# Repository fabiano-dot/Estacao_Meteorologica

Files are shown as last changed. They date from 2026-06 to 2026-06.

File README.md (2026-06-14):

# 📡 Estações Meteorológicas LoRaWAN – UNICAMP

Firmware e infraestrutura de servidor de uma rede de monitoramento ambiental baseada em **LoRaWAN**, implantada no campus da **Universidade Estadual de Campinas (UNICAMP)**. As estações são identificadas de `em01` a `em10` e estão sendo gradualmente implantadas ao longo do campus.

Os dados coletados estão disponíveis publicamente e são atualizados diariamente em: **[HuggingFace Dataset](https://huggingface.co/datasets/adr1t0s/estacao-meteorologica/tree/main)**

---

## 🏗️ Arquitetura do sistema

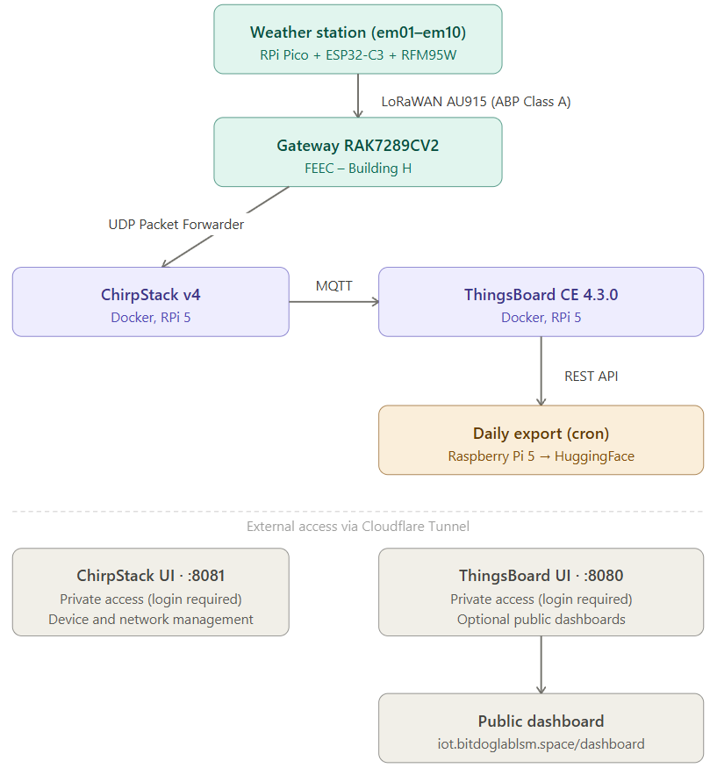
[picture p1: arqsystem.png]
Arquitetura do sistema


---

## 📡 Rede LoRaWAN

| Parâmetro | Valor |
|---|---|
| **Gateway** | RAK7289CV2 |
| **Região** | AU915 — sub-bandas 0 e 1 (16 canais) |
| **Modo** | ABP Classe A |
| **Servidor de rede** | ChirpStack v4 (self-hosted, Docker) |
---

## 🖥️ Servidor

| Componente | Descrição |
|---|---|
| **Hardware** | Raspberry Pi 5 (8 GB RAM) + SSD NVMe 256 GB |
| **OS** | Raspberry Pi OS (64-bit) |
| **ChirpStack v4** | Servidor de rede LoRaWAN (Docker) |
| **ThingsBoard CE 4.3.0** | Plataforma IoT — ingestão, regras e dashboards (Docker) |
| **Mosquitto** | MQTT broker |
| **Cloudflare Tunnel** | Acesso remoto seguro sem exposição de portas |

---

📂 Estrutura do repositório

```
Estacao_Meteorologica/
├── README.md
├── arquitectura.png
├── ScriptsToDataDailyUpdate/
│   ├── export_for_date.sh      ← exporta dados de uma data específica
│   ├── export_yesterday.sh     ← wrapper que chama export_for_date com ontem
│   ├── run_daily.sh            ← orquestrador do cron: pull → export → push
│   └── config.env              ← credenciais (não versionado)
└── .gitignore
```

Os scripts de exportação de dados e os CSVs estão no **[HuggingFace Dataset](https://huggingface.co/datasets/adr1t0s/estacao-meteorologica/tree/main)**, não neste repositório. Os três scripts principais são:

- **`export_for_date.sh`** — recebe uma data (`YYYY-MM-DD`) como argumento, autentica na API REST do ThingsBoard, baixa a telemetria de cada dispositivo ativo e do asset OWM para aquela janela de 24h (fuso `America/Sao_Paulo`), converte os JSONs brutos em CSVs com `jq` e remove os JSONs ao final.
- **`export_yesterday.sh`** — wrapper simples que calcula a data de ontem e chama `export_for_date.sh`. É o ponto de entrada do cron.
- **`run_daily.sh`** — orquestrador diário: faz `git pull --rebase` para receber atualizações dos scripts, chama `export_yesterday.sh`, e se houver dados novos em `data/` faz commit e push para o HuggingFace automaticamente.

---

## 🚧 Estado do projeto

| Componente | Status |
|---|---|
| Rede LoRaWAN operacional | ✅ |
| ChirpStack v4 self-hosted | ✅ |
| ThingsBoard CE com dashboards públicos | ✅ |
| Export automático diário para HuggingFace | ✅ |
| Plugin ML para ADR (ChirpStack JS + FastAPI) | 🔄 em desenvolvimento |
| Mapeamento preditivo de cobertura (Random Forest) | 🔄 em desenvolvimento |

---

## 🔗 Links

- 📦 [Dataset (HuggingFace)](https://huggingface.co/datasets/adr1t0s/estacao-meteorologica/tree/main)
- 📊 [Dashboard público](https://iot.bitdoglablsm.space/dashboard)
- 📡 [ChirpStack v4](https://www.chirpstack.io/docs/getting-started/docker.html)
- 🖥️ [ThingsBoard CE](https://thingsboard.io/docs/installation/docker/)
- 🌐 [Cloudflare Tunnel](https://developers.cloudflare.com/cloudflare-one/connections/connect-networks/)

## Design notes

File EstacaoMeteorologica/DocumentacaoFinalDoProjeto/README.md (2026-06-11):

# Projeto final - EmbarcaTech 2025-2026

Autores: **Carlos Martinez Perez** e **Ricardo Jorge Furlan** e **Antonio Crepaldi (na fase 3)**  

Curso: Residência Tecnológica em Sistemas Embarcados

Instituição: EmbarcaTech - HBr

Campinas 15, fevereiro de 2026.

---

## ⚠ Disclaimer
## THE PROJECT IS PROVIDED "AS IS", USE AT YOUR OWN RISK
## O PROJETO É FORNECIDO "COMO ESTÁ", USE POR SUA CONTA E RISCO

## This project was developed for educational purposes as an assignment for Phase 3 of the residency program in the **EmbarcaTech professional training program**, with the goal of demonstrating some of the concepts learned during the residency.

## Third-Party Code

- The `pico_sdk_import.cmake` file was **automatically generated** during project creation by the **Raspberry Pi Pico plugin**.
- The `CMakeLists.txt` file was initially **automatically generated** during project creation by the **Raspberry Pi Pico plugin**, and later edited as needed for the project.

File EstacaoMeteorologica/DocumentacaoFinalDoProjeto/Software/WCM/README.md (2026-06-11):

# Esp32-C3

## Comando para verificar acesso ao Esp32
$ .espressif/python_env/idf6.0_py3.13_env/bin/esptool --chip esp32c3 --port /dev/ttyACM0 chip-id

## Comando para apagar Flash
$ .espressif/python_env/idf6.0_py3.13_env/bin/esptool --chip esp32c3 --port /dev/ttyACM0 erase-flash

## Comando para gravar Flash
$ .espressif/python_env/idf6.0_py3.13_env/bin/esptool.py --chip esp32c3 --port /dev/ttyACM0 --baud 460800 write_flash 0x0 lmic_abp_00.ino.merged.bin

## Versões:
- Build 0004: Testado na semana 12-16/01/2026
- Build 0005: Incorpora OTAA ainda não testado

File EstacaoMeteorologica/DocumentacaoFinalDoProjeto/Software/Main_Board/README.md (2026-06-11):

# Descrição do Código da Estação Meteorológica IoT
Rev: Beta01   Data: 07/02/2026

## Configurações pelo usuário
Os parâmetros configuráveis pelo usuário são feitos apenas através do monitor serial e está descrito claramente no manual do usuário. Resumidamente as principais são:
- Modo LoRa e seus parâmetros
- Sensores ativos na estação
- Definição do tempo para cada leitura
- Configuração de recursos de log, LEDs e USB (Obs. eles afetam o consumo da estação).

Estes parâmetros podem ser salvos em flash (no menu de configuração) assim sendo desnecessário a reconfiguração quando se reenergiza a estação.

## Configurações pelo programador
Os parâmetros de configuração de compilação ficam em:
- CMakeLists.txt
Utilizado para definir configurações específicas para debug
- code_config.h
Arquivo que concentra todas as principais configurações do código, destacando-se:
    - PICO_WITH_DEBUG_PROBE, se definido habilita o uso do debug probe reconfigurando as portas UART a serem utilizadas
    - DEBUG_ON e derivados, habilitam printf de log para depuração
    - WATCHDOG_ENABLED, se definido ativa o funcionamento do watchdog
    - START_SEND_WITH_FIX_DATA, se definido faz com que as 5 primeiras transmissões sejam valores conhecidos independentes do valor lido, útil para debug
    - SLEEP_STATE_BY_GPIO, se definido faz que durante os períodos de sleep os gpio reflitam o funcionamento do Sleep mode, util para debug
    - INITIAL_DELAY_MS, define o tempo, em milissegundos, de espera inicial para rodar o programa, permitindo assim conectar a interface serial (USB) antes do programa iniciar
    - USB_TURN_ON_TIME_S, define o tempo, em segundos, que vai esperar a USB ligar quando no modo de log ON-OFF
    - ADD_CHECKSUM_ON_PAYLOAD, adiciona uma sum e xor dos bytes do payload com objetivo de verificar a integridade do mesmo (util para debug)

## Funcionamento do código
A estrutura do código foi definida visão o baixo consumo da estação. Para isso foi utilizado os recursos de colocar os sensores em sleep-mode e desativar ao máximo os recursos não utilizados da rp2040 bem como reduzir seu clock nos momentos de sleep-mode, o que reduz expressivamente seu consumo.

**Obs.: Os fluxogramas são versões simplificadas do código com intuito de mostrar os pontos principais do código. Tratamento de erros e timeout geralmente não estão incluídos.**

### main.c
A rotina main tem como função inicializar todos os dispositivos após o power on e manter o main-loop.

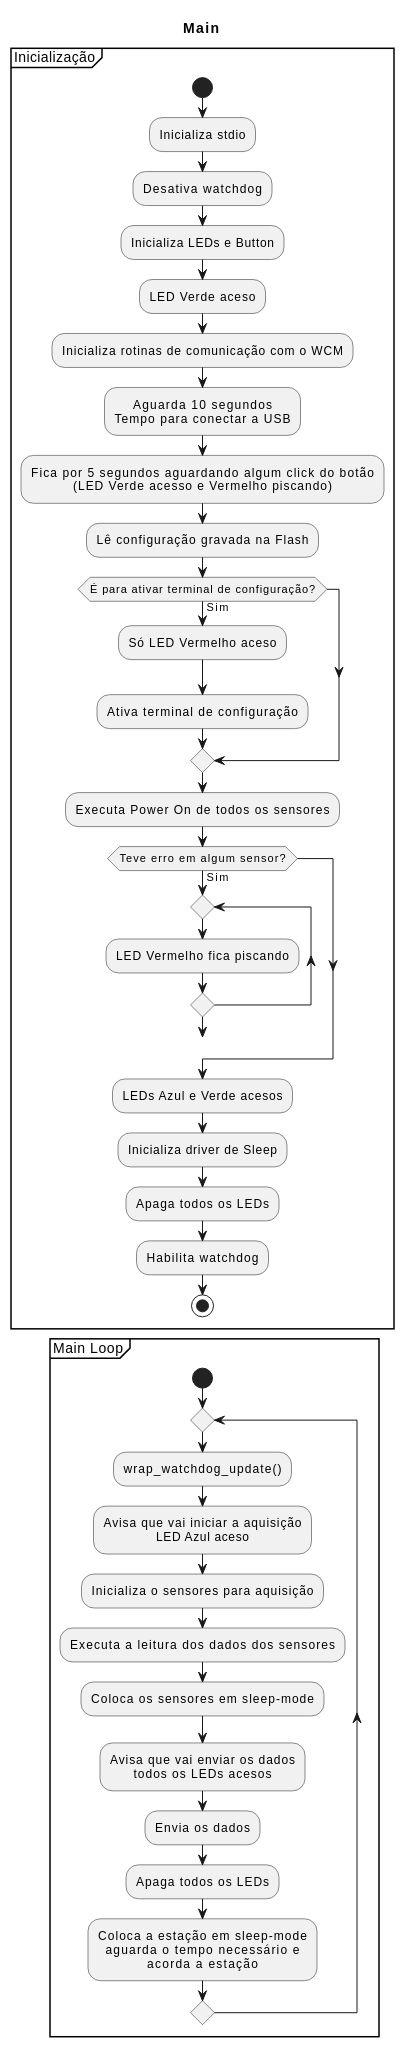
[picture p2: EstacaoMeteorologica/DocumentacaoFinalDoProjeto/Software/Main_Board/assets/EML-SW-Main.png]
Fluxograma do main


### aq_data
Neste arquivo há:
- A definição de uma variável que armazena os dados de todos os sensores;
- Um grupo de funções que tem como objetivo chamar as funções equivalentes de cada sensor quando este está ativo (Obs.: O sensor é definido como ativo pelo usuário na configuração do sistema).

Funções:
- aqdata_init_power_on: Utilizada apenas após o power-on/reset do software;
- aqdata_init_aq: chamada no main-loop após o MPU acordar e tem como função acordar os sensores e inicializar as aquisições dos mesmos;
- aqdata_read: chamada após a aqdata_init_aq, le os dados dos sensores;
- aqdata_sleep: chamada após a aqdata_read, tem como objetivo colocar os sensores em sleep-mode quando for o caso.

### aq_data_ad
Driver do AD para leitura da MPU Temperature e VSys.
Desliga e liga quando não necessários:
- Sensor de temperatura
- O AD
- O Clock do AD

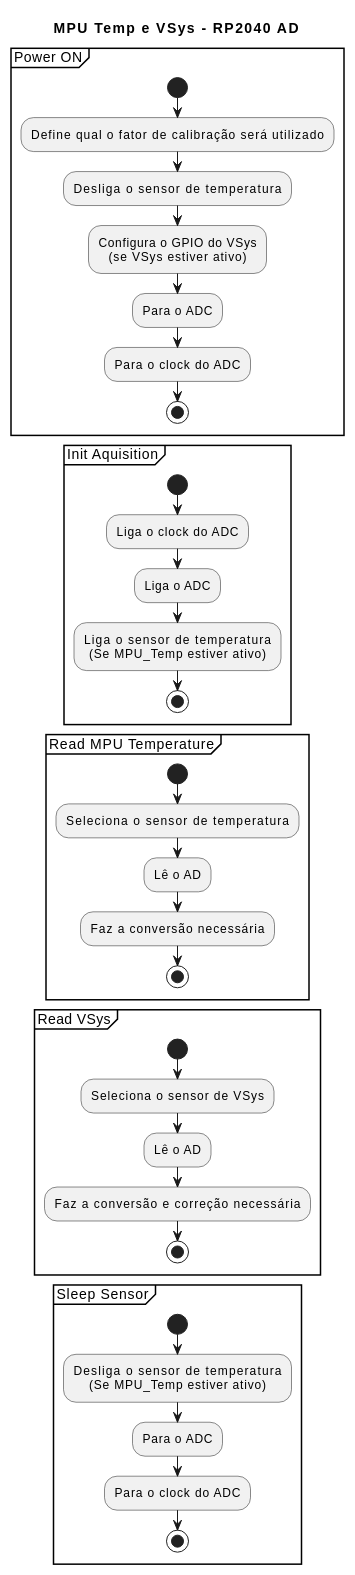
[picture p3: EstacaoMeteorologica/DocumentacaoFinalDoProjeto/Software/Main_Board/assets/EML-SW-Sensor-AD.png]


### aq_data_bmep280
Obs.: O sensor de: temperatura, pressão, e umidade é o bme280, mas caso se utilize o bmp280, que não tem o módulo de umidade, ele será reconhecido e tratado corretamente, apenas o dado de umidade será reportado como ERRO.

Funcionamento
- A rotina após o reset lê qual CI está instalado e lê os dados de calibração presentes no CI
- Para cada leitura é necessário:
    - Setar o mode de oversample de cada unidade.
    - Disparar o modo de  aquisição, no caso se está usando o Forced Mode que inicia uma aquisição e após ela estar concluida faz o CI entrar em sleepo-mode
    - Para fazer a leitura correta é necessário:
        - Aguardar o flag de em aquisição true
        e após
        - Aguardar o flag de em aquisição false
        Obs.: O flag demora uns 450us para ficar true, caso não se aguarde ele ficar true e só se verifique que ele esta false, pode-se estar lendo a aquisição anterior.
    - Fazer as compensações com os parâmetros de calibração.

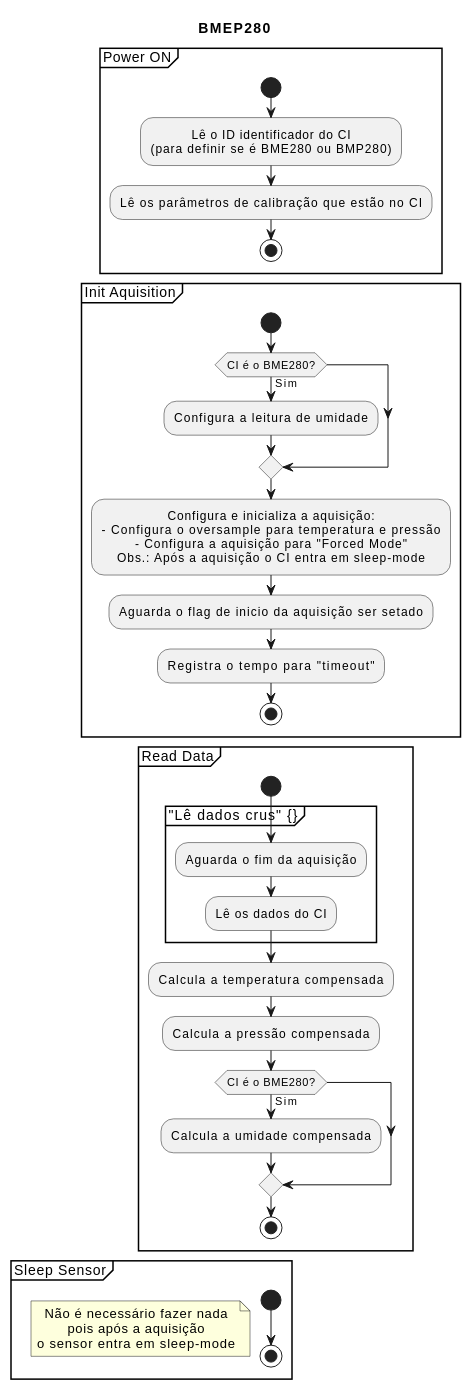
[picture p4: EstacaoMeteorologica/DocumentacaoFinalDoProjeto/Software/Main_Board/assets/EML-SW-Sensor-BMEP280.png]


### aq_data_gps

### aq_data_lux
O sensor de luminosidade, luxímetro, é o BH1750.
Como a leitura dele é afetada pela proteção que o envolve há um fator de correção configurável pelo usuário (detalhes no manual do usuário).
O sensor BH1750 consome algo em torno de:
- 115 uA quando ativo
- 3.7 uA quando em sleep-mode
Por isso está sendo setado o modo em que ele faz uma leitura e já entra em sleep-mode, reduzindo o consumo.

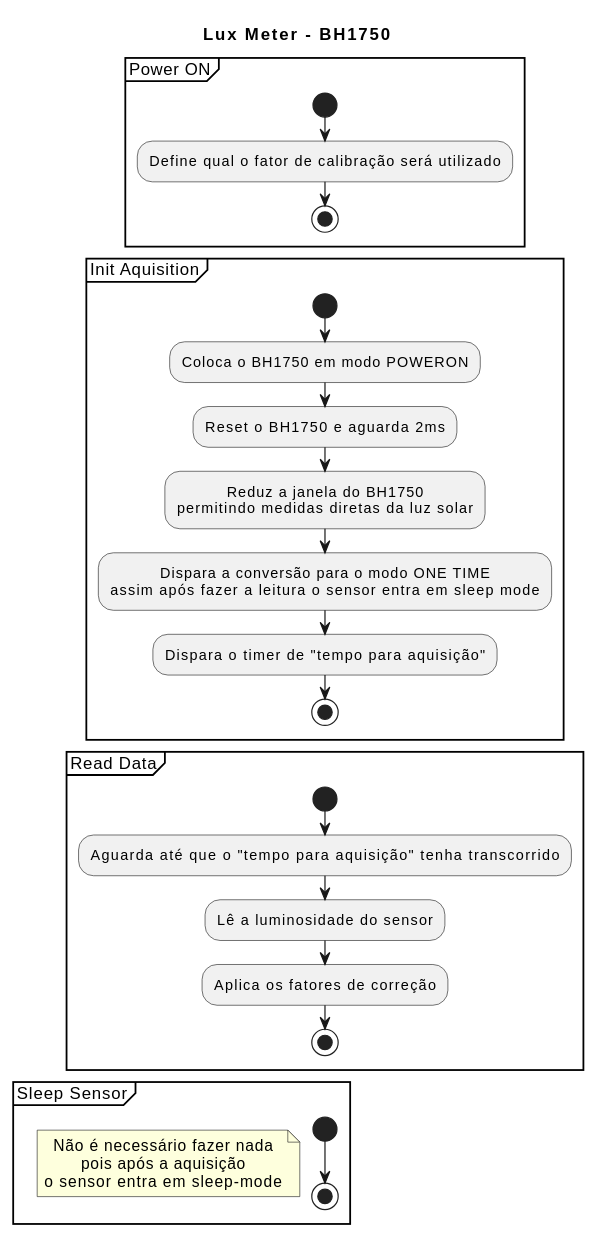
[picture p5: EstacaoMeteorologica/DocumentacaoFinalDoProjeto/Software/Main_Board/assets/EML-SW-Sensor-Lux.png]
Fluxograma das rotinas do Luximetro


### buttons_and_leds
Configura o Driver dos LEDs e botão
- A porta do botão é configurada como input e com um pullup
- A porta dos LEDs serão configuradas como output e como zero
- Obs.: durante a inicialização cada LED fica aceso por: LED_INIT_DELAY_MS

### est_config
Define as estruturas utilizadas para a configuração da estação
Possui funções para manipular a configuração:
- Ler da flash
- Salvar na flash
- Definir valores default
Obs.: Os valores que são salvos e lidos na flash possuem um "HASH-like" para verificação da integridade

### hw_sleep
Para que o sistema consuma o mínimo de energia é necessario desativar módulos desnecessarios.
Entre uma aquisição e outra o número de recurso necessários e muito baixo podendo a maioria ser desligado, mas que devem ser ligados quando se for efetuar a aquisição e transmissão dos dados,
O Clock da CPU tem um grande impacto no consumo sendo que sua redução durante o periodo entre aquisições é relevante.
Temos duas funções:
- init, que desativa tudo que não será utilizado permanentemente
- sleep, que:
    - desativa tudo que não for necessário entre aquisições;
    - aguarda até o momento da próxima aquisição
    - ativa tudo o que é necessário para a próxima aquisição

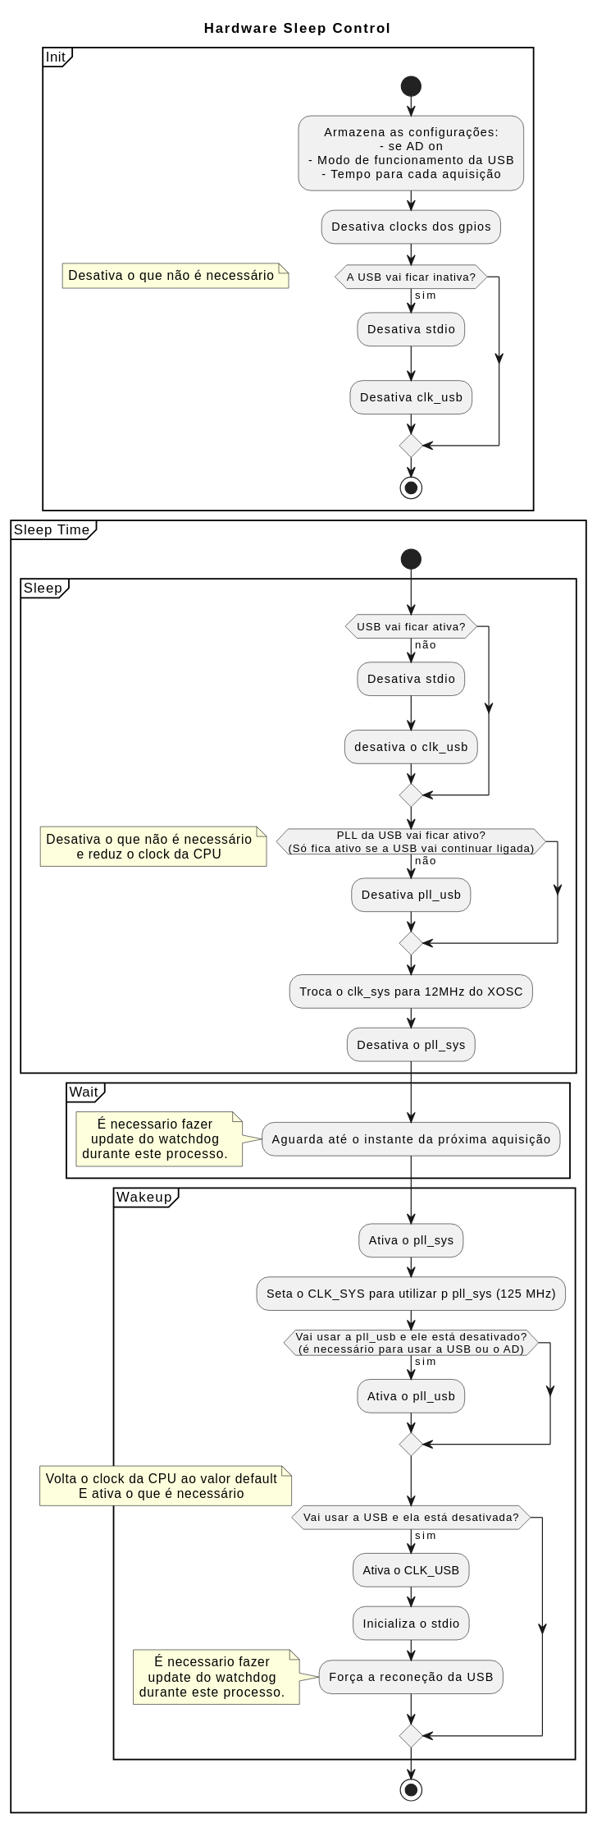
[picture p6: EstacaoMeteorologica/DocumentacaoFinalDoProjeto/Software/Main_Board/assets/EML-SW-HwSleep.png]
Fluxograma das rotinas de Sleep


### loop_printf
 Rotina que "embrulha" o printf em loop_printf
 Funciona como o printf só que:
 - a função loop_printf é chamada no lugar do printf pelas rotinas que são executadas dentro do main-loop
 - Foi criada pensando em futuras melhorias, para ser usada quando o USB está off ==> inativar o printf

### menu_conf
O menu de configuração funciona enviando e recebendo caracteres txt para o terminal;
Para gerar a tela é iniciado com uma sequencia de caracteres que faz "ir" para o topo da tela. Ai são enviadas todas as linhas formatadas.
O programa aguarda um caractere que será tratado como comando. Este comando é executado e o processo se repete.
Obs.: Caso o comando seja Exit a rotina é encerrada, voltando para a execução do programa principal.

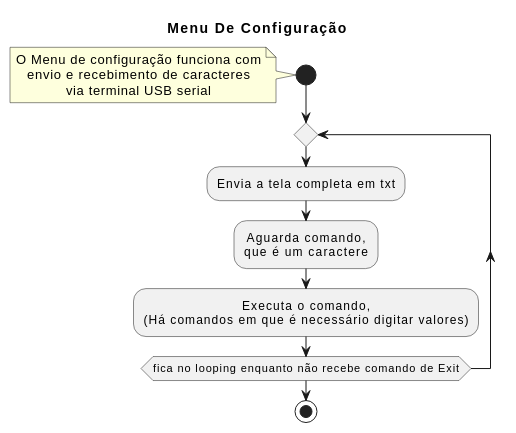
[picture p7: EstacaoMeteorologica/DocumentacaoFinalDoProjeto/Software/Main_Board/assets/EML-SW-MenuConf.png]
Fluxograma do Menu de Configuração


### storage
Obs.: Este arquivo é uma simplificação do utilizado na fase2.

O ponto mais relevante é que para que se escrever na flash tem que ser garantido que não ocorrerá nenhum outro acesso a flash até que a operação de escrita seja feita.
Para isso normalmente todas as interrupções devem estar inativas e o programa de escrita rodar a partir da RAM. Para isso utiliza-se na definição da função a expressão: __not_in_flash_func

### wcm
A rotina de envio do WCM consta de:
- Criar o comando
    - Monta a parte que depende apenas da configuração
    - Adiciona o payload dos dados recém adquiridos
- Enviar o comando
    - Ativar o WCM para receber dados
    - Enviar o comando
    - Aguardar a resposta

- Obs.: o payload é formado por números inteiros (bytes, não ASCII) e será convertido ao ser utilizado com a grandeza e resolução abaixo:

| Grandeza |  Resolução  | Unidade | Casas<br>decimais | Exemplo |
| :---: | ---: | --- | :-: | ---: |
| BME280<br>Temperatura | 0,01 | Celsius |  2  | 23.45 |
| BME280<br>Pressão | 0,02 | hPa |  2  | 12.34 |
| BME280<br>Umidade | 0,5 | % |  1  | 12.5  |
| Luminonidade | 4 | lx |  0  | 123456 |
| GPS-Latitude<br>GPS-Longitude | 0,000000119 | graus |  7  | -42.1234567 |
| GPS-Altitude | 0,1 | m |  1  | 432.1  |
| VSys |  20<br>0,02 | mV<br>V | 0<br>2 |3220<br>3.22 |
| MPU-temp | 1 | Celsius |  0  | 25 |

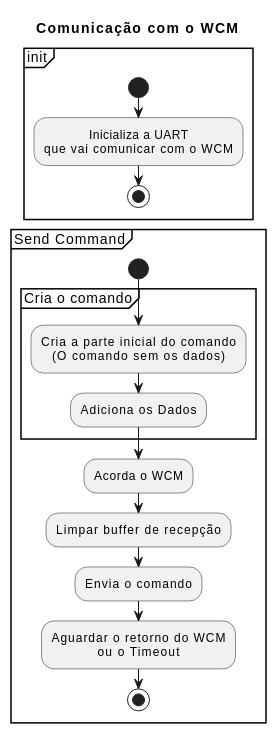
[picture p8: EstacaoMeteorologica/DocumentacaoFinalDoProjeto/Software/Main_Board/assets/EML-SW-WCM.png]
Fluxograma das rotinas de comunicação com o WCM


#### Descrição do Payload
               
##### O Primeiro byte, byte de controle BC, descreve os bytes seguintes.       
Cada um dos bits do BC representa a presença ou não de um valor no payload:
- bit 0 ==> Battery,  1 byte (Deprecated)                                
- bit 1 ==> BME280,   5 bytes                                            
- bit 2 ==> GPS,     10 bytes                                            
- bit 3 ==> BH1750,   2 bytes                                            
- bit 4 ==> Reserved                                                     
- bit 5 ==> Reserved                                                     
- bit 6 ==> VSys,     1 byte                                             
- bit 7 ==> MPU Temp, 1 byte                                             
                                                                           
##### Tamanho e descrição de cada valor:                                       
- Bit 0 – Battery (Deprecated)
    - Utiliza um byte
    - Corresponde a carga da bateria em %, passos de 0,5%
    - Valor real = byte * 0.5
    - Quando o byte for 0xFF ==> ERRO
- Bit 1 – BME280
    - Utiliza 5 bytes, sendo:
      - Byte  0                  ==> Umidade, passos de 0.5%
        Quando o byte for 0xFF   ==> ERRO
      - Bytes 1 e 2              ==> Temperatura, passos de 0,01 °C
        Quando a word for 0x7FFF ==> ERRO
      - Bytes 3 e 4              ==> Pressão, passos de 0,02 hPa
        Quando a word for 0xFFFF ==> ERRO
- Bit 2 – GPS
    - Utiliza 10 bytes, sendo:
      - Bytes 0 a 3              ==> Latitude,  passos de 1 / (2^23) graus
        Quando a long word for 0x7FFFFFFF ==> ERRO
      - Bytes 4 a 7              ==> Longitude, passos de 1 / (2^23) graus
        Quando a long word for 0x7FFFFFFF ==> ERRO
      - Bytes 8 a 9              ==> Altitude,  passos de 0,1 metro
        Quando a word for 0x7FFF ==> ERRO
- Bit 3 – Lux Meter
    - Utiliza 2 bytes, sendo:
        - Bytes 0 e 1              ==> luminosidade, passos de 4 lux
        Quando a word for 0xFFFF ==> ERRO
- Bit 4 – Reserved
- Bit 5 – Reserved
- Bit 6 – Vsys
    - Utiliza um byte
    - Corresponde a tensão VSys, passos de 20 mV
    - Valor real(em mV) = byte * 20
    - Quando o byte for 0xFF ==> ERRO
- Bit 7 – CPU Temp
    - Utiliza um byte
    - Corresponde a temperatura da MPU, passos de 1 Celsius
    - Valor real = byte tratado como signed
    - Quando o byte for 0x7F ==> ERRO

### wrap_watchdog
Rotinas que embrulham (wrap) as rotinas originais do wathdog
Permitindo assim serem facilmente habilitadas ou desabilitadas: WATCHDOG_ENABLED

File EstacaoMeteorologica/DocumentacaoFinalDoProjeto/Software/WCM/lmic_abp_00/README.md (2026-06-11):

# main
- Versão funcional no envio de LoRaWAN ABP:
    - WCM Versão 0.00.04 04/01/2026 Build: 0004
    - Branch CmdUart
- Utiliza placa WCM com:
    - RFM95W
    - Speed Studio, XIAO ESP32-C3
- Recebe comandos pela UART, nesta versão só está ativo o CMD 'A' (LoRaWAN ABP)

### Comentários
- Os parâmetros LoRaWAN são enviados junto com a linha de comando
- O módulo consome algo como 2,1 segundos para cada transmissão

### Próximos passos
- Documentar o código
- Suporte ao ESP32-C3 Mini Super
- Iniciar testes com OTAA
- Avaliar melhorias no consumo

### Consumo do Módulo WCM com transmissão ABP

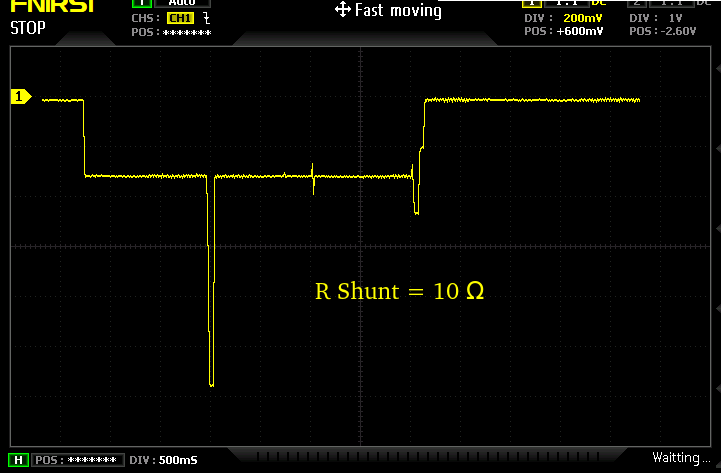
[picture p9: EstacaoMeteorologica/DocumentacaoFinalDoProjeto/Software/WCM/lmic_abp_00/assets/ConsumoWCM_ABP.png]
Foto1


## Versão 0.00.05 - 14/01/2026 - Build: 0005
Add Suporte para LoRaWAN OTAA

## Versão 0.00.06 - 25/02/2026 - Build: 0006
- Correção do setting do SF

## Versão 0.00.07 - 25/02/2026 - Build: 0007
- Remoção das mensagens de debug

## Versão 0.00.07c - 26/03/2026 - Build: 0008
- Instruções de Build
    para o lmic funcionar em au915 é necessario editar o arquivo:
        /home/user01/Arduino/libraries/MCCI_LoRaWAN_LMIC_library/project_config/lmic_project_config.h
        para:
```
// project-specific definitions
//#define CFG_eu868 1
//  #define CFG_us915 1
#define CFG_au915 1
//#define CFG_as923 1
// #define LMIC_COUNTRY_CODE LMIC_COUNTRY_CODE_JP      /* for as923-JP; also define CFG_as923 */
//#define CFG_kr920 1
//#define CFG_in866 1
#define CFG_sx1276_radio 1
//#define CFG_sx1261_radio 1
//#define CFG_sx1262_radio 1
//#define ARDUINO_heltec_wifi_lora_32_V3
//#define LMIC_USE_INTERRUPTS
```
## Versão 0.00.08 - 07/04/2026 - Build: 0009
- Add channels:
    - 0xFD  ==> AUTO 0-7
    - 0xFE  ==> AUTO 8-15
    - 0xFF  ==> AUTO 0-15

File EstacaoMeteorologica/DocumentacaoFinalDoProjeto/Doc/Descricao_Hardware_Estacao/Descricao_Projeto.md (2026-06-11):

# Descrição Técnica do Projeto da Estação Meteorológica

**Autores: Antonio - Carlos - Ricardo**
**Data: 15/02/2026**

## Hardware

Principais elementos da Estação Meteorológica:  
- Placa principal;
- Módulo WCM;
- Base de fixação;
- Caixa da PCB;
- Painel Solar;
- Invólucro do luxímetro;
- Invólucro do BME280;
- GPS;
- Antena LoRa.  

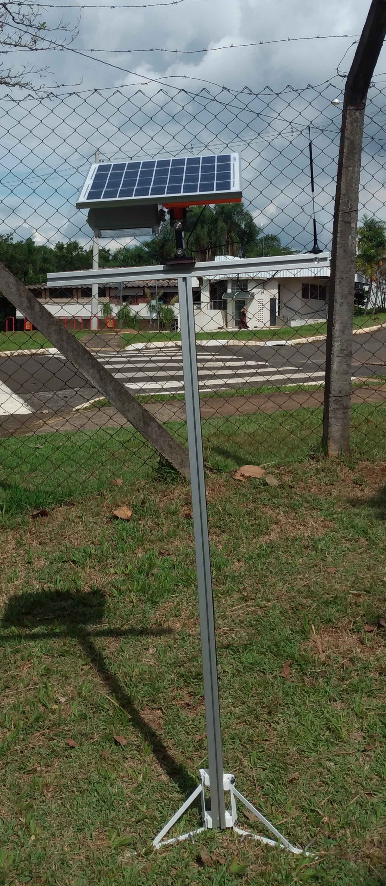
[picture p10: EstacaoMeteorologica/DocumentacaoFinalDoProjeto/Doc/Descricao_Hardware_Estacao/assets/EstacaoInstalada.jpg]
Estação Instalada


### PCB da Estação

Principais elementos da PCB:
- Fonte de Energia:
	+ Conversor DC-DC de 21V para 5V - permite que o painel solar que funciona na faixa dos 21V alimente com segurança o carregador de bateria;
	+ Carregador de Bateria com circuito de proteção - carrega a bateria e a protege contra cutto circuito e descarga além do limite permitido;
	+ Obs.: Todos os demais elementos da PCB são alimentados com 3v3 fornecido pelo regulador buck-boost da placa Raspberry Pi Pico.
- MPU:
	+ Placa Raspberry Pi Pico (RP2040) - possui as funções de:
		* Gerar 3V3 a partir da bateria;
		* Orquestrar todo o funcionamento da estação.
- WCM - LoRaWAN:
	+ Permite que através de comandos seriais via UART faça a transmissão das informações através do protocolo LoRaWAN.
- Conectore3s para os sensores:
	+ BME280 - permite, via I2C, medir temperatura, pressão e umidade atmosférica;
	+ BH1750 - permite, via I2C, medir a luminosodade visível incidente;
	+ GPS - permite, via UART, obter a localização geográfica da estação, ou seja, latitude, longitude e altitude.
- Sinalização:
	+ Três LEDs (R, G e B) - indicam em que estágio o software se encontra.

A figura a seguir mostra a distribuição dos principais elementos na PCB
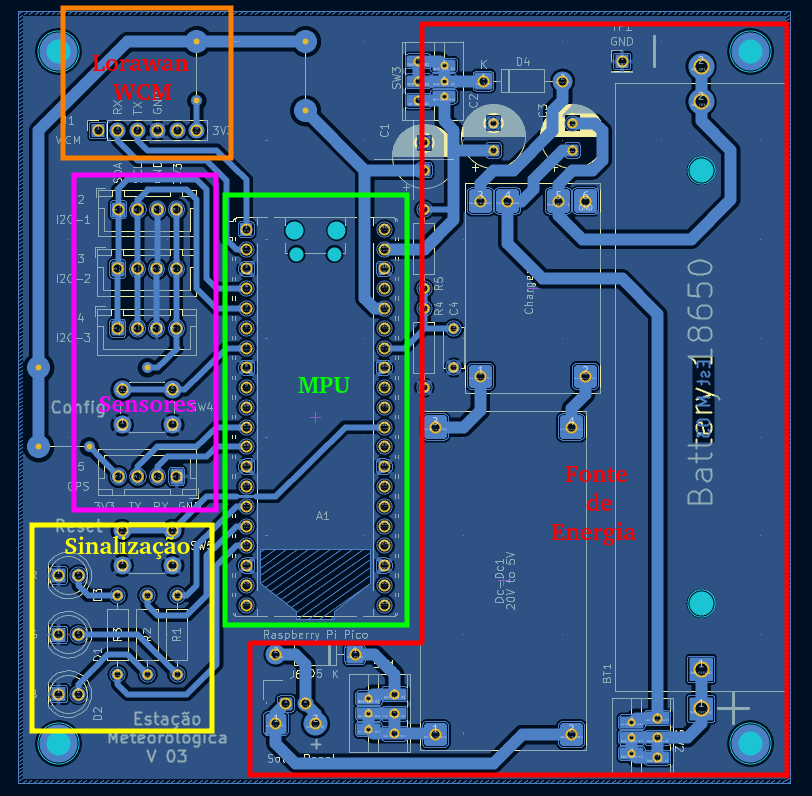
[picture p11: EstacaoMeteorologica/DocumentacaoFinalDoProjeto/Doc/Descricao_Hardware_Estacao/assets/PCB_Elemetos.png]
Distribuição do elementos na PCB


A figura a seguir mostra a PCB Montada
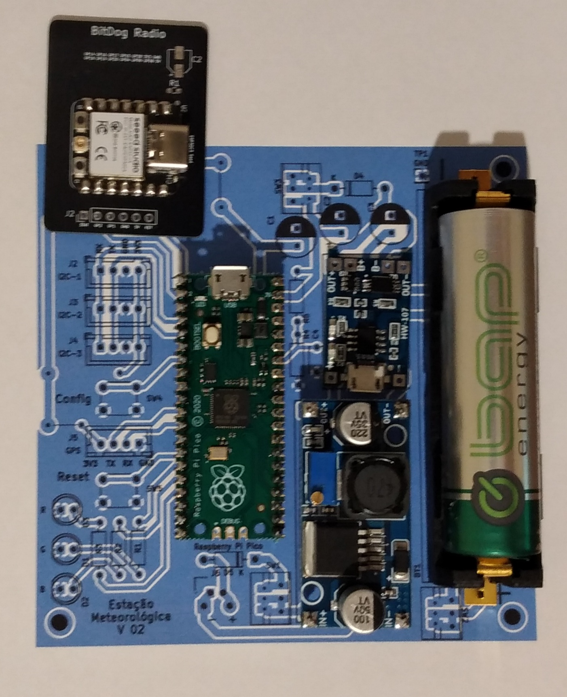
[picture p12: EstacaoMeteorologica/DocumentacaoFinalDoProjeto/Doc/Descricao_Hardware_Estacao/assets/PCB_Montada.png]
PCB Montada


A figura a seguir nostra o esquema Elétrico da PCB
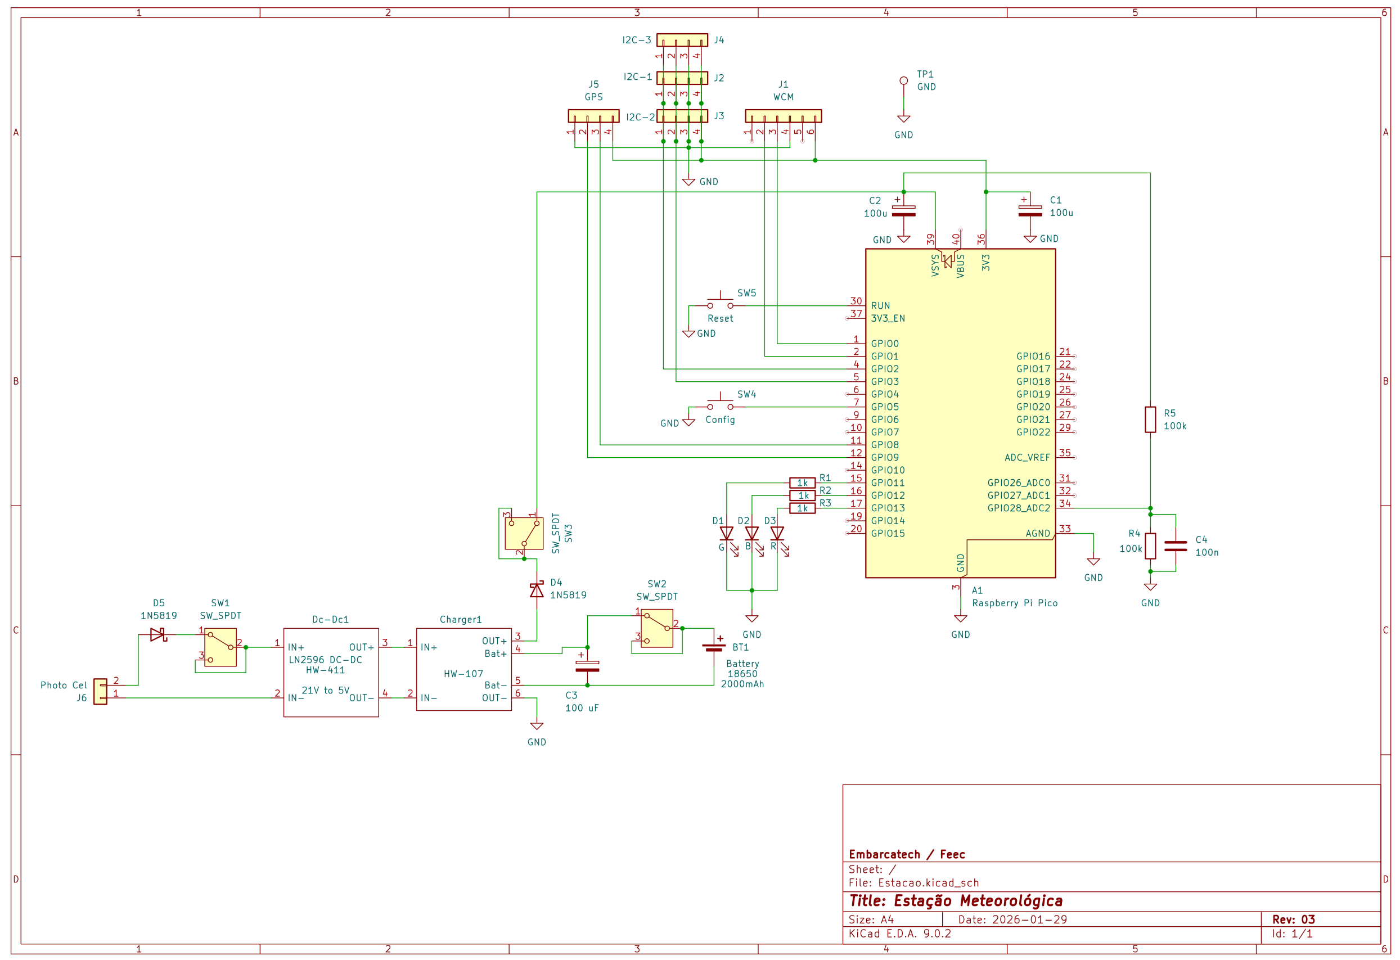
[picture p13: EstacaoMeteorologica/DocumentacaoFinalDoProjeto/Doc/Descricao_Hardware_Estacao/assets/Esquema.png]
Esquema Elétrico


- A PCB possui 3 chaves, que são úteis para a aperação. Em operação normal todas devem estar ligadas.
Função das chaves:  
	- SW1: Liga o Painel solar, permitindo, se desligado, que a estação só funcione via bateria. Isso é útil para se medir a autonomia da estação sem a carga do painel solar.
	- SW2: Liga a bateria, permitindo, se desligado, que a estação só funcione com o painel solar. Isso é fortemente não recomendado.
	- SW3: Liga efetivamente a estação.  
    Portanto, é possível:
	    - A estação operar só com a bateria;
	    - A bateria ser carregada pelo painel solar enquanto a estação está desligada;
	    - A bateria ser carregada pelo painel solar enquanto a estação está ligada.
  
- O Botão SW4 (Config) é utilizado para que a estação entre no modo de configuração ao energizar a estação (vide manual do usuário).

- O Botão SW5 (Reset) é utilizado para reinicializar o MCU sem ter a necessidade de desligar a placa.

- Os resistores R1, R2 e R3 tem como função limitar as correntes nos LEDs.

- Os resistores R4 e R5 integram um divisor resistivo para que o AD do RP2040 possa monitorar de forma segura a tensão do VSys, que é bem próxima a tensão da bateria. C4 ajuda na estabilização da leitura de tensão.
 
- D1, D2 e D3 são os LEDs de sinalização da placa.

- D4 tem como função evitar que quando a placa estiver conectada em uma porta USB, a bateria seja incorretamente carregada por esse meio.
 
- D5 tem como função evitar que a ligação invertida do painel solar danifique a placa.

- C1, C2 e C3 ajudam na estabilização da alimentação da placa.

### WCM
Principais elementos do WCM:
- XIAO-Esp32-c3 - traduz os comandos recebidos via UART em pacotes LoRaWAN e os direciona para o RFM95W respeitando as sequencias e os tempos dos comandos necessários.

- RFM95W - rádio LoRa, agrega todos os circuitos de RF (Transmissor, Receptor, PLL, etc), moduladores e demoduladores de sinal e circuitos auxiliares para a transmissão e recepção do sinal.

A figura abaixo mostra o esquema fornecido pela equipe da Unicamp.
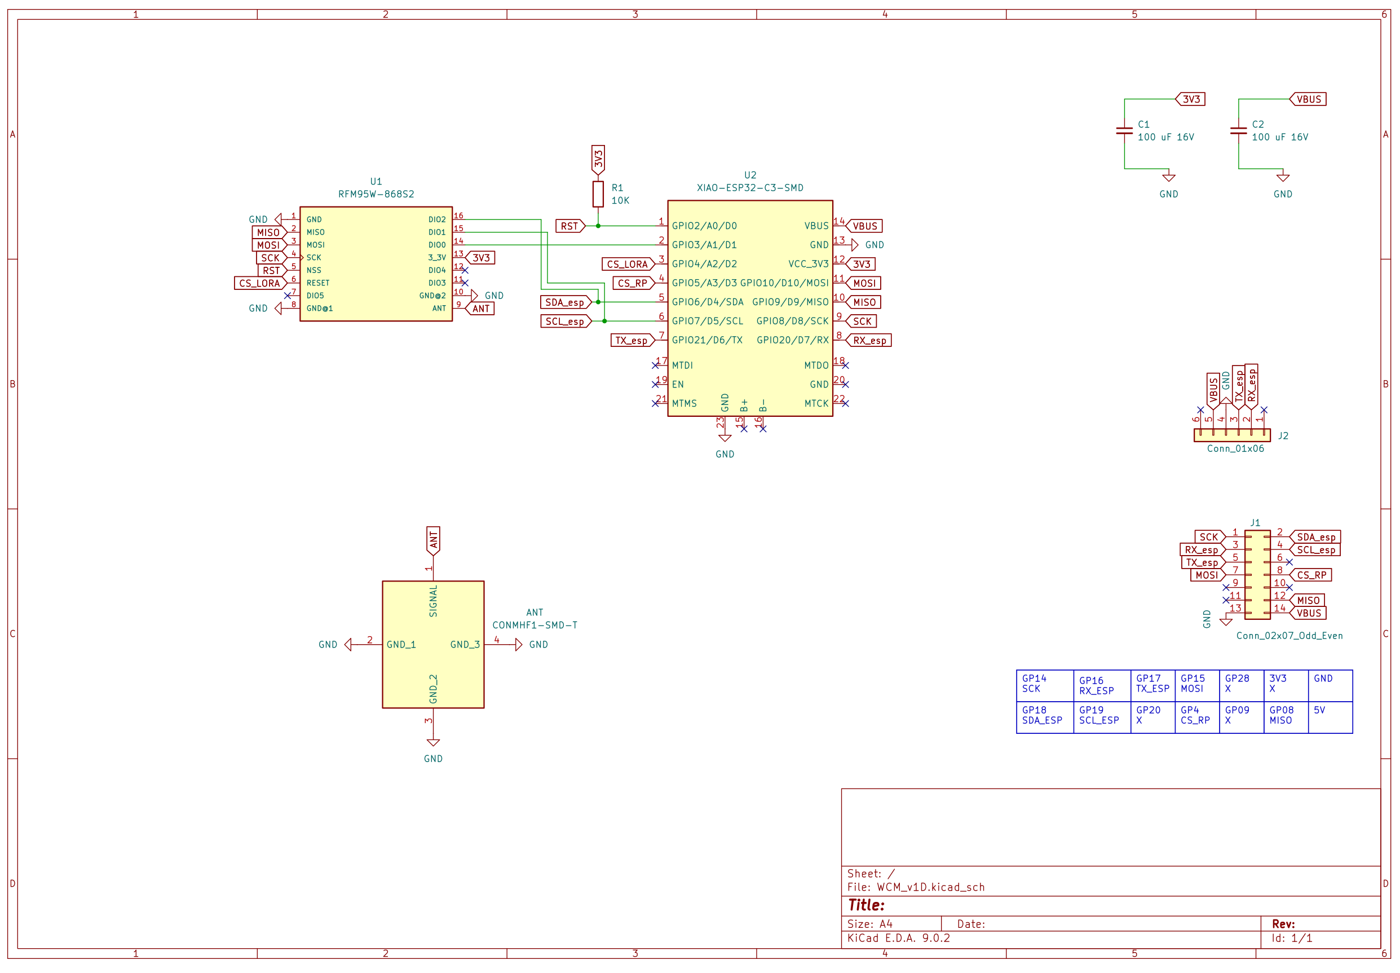
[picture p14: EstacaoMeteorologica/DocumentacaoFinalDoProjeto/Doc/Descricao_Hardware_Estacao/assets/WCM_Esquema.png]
Esquema Elétrico WCM
    

WCM antiga visão frontal:
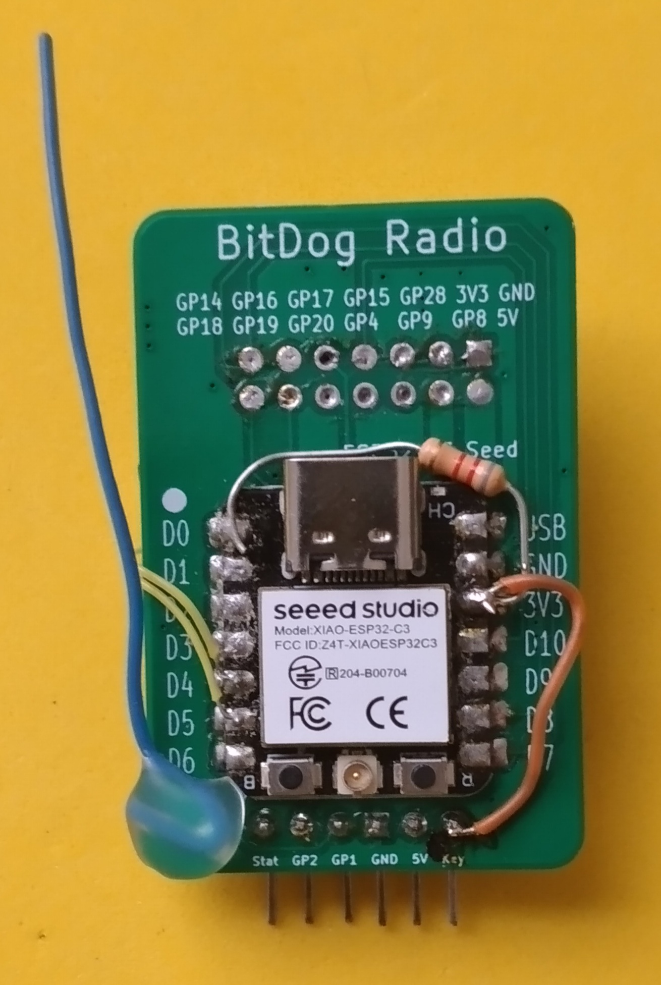
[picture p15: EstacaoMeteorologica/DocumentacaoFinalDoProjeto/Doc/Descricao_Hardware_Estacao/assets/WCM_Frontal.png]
Vista Frontal WCM
  

WCM antiga visão traseira:
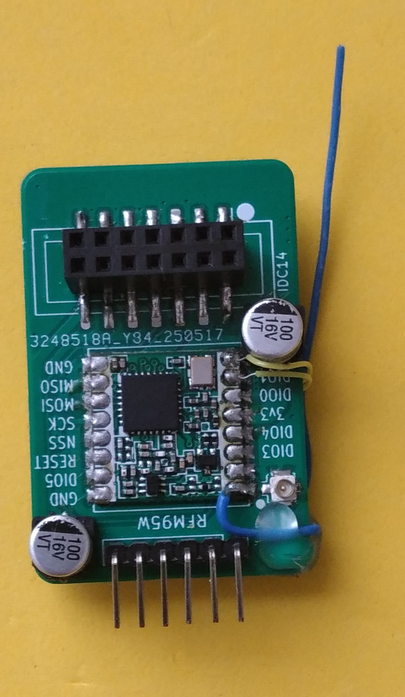
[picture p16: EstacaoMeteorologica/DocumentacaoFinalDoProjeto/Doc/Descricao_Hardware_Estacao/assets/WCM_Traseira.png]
Vista Traseira WCM
  

WCM nova com correção:
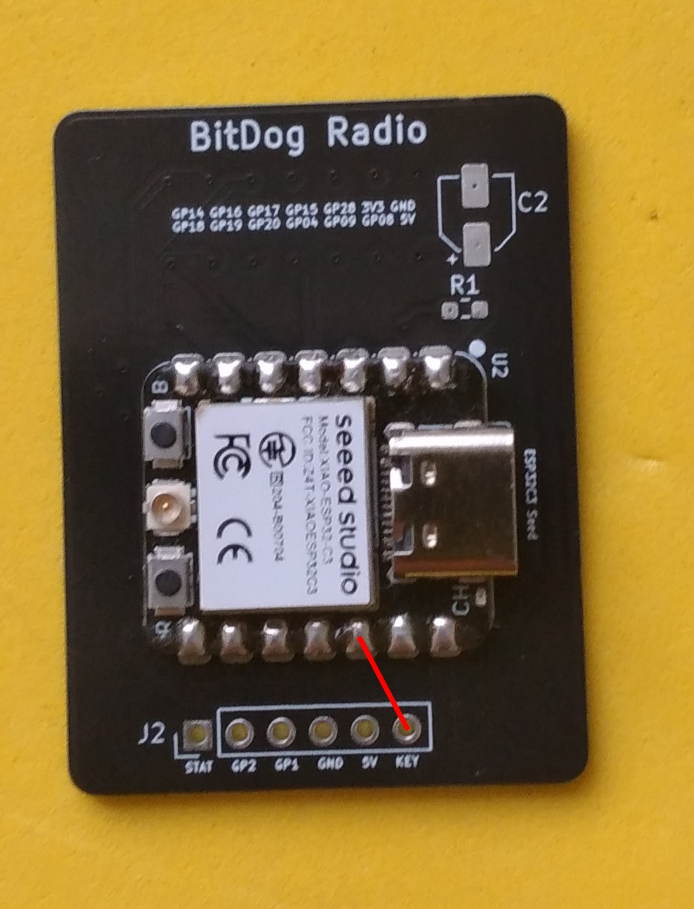
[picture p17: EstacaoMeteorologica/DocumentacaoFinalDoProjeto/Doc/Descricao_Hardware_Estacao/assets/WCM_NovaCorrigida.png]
PCM da WCM nova com correção
  

## Software

### Estação

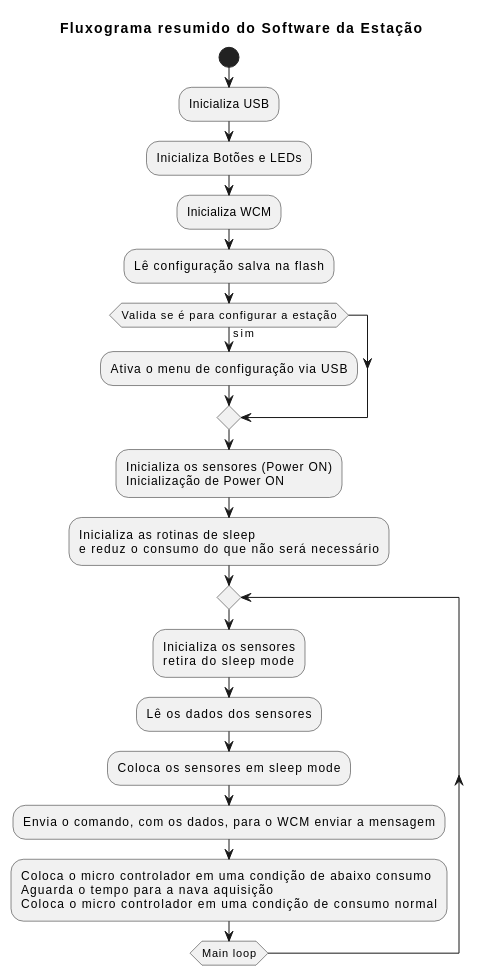
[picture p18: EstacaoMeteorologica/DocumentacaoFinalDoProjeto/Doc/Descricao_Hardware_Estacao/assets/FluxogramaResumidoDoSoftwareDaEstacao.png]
Fluxograma Resumido do Software da Estacão


### WCM

O software do WCM foi desenvolvido para que:  
- Ao receber um nível low no RX da uart, o WCM acorda e aguarda comandos;
- Caso o WCM não receba comandos completos (Timeout), ou receba comandos inválidos, retornará para o light-sleep mode;
- Há dois comandos válidos:
	+ Comando de envio de mensagem via ABP;
 	+ Comando de envio de mensagem via OTAA.
- Ao receber o comando válido o WCM fará a codificação LoRaWAN e transmitirá. Caso obtenha sucesso na operação retornará OK. Caso contrário, não retornará nada.

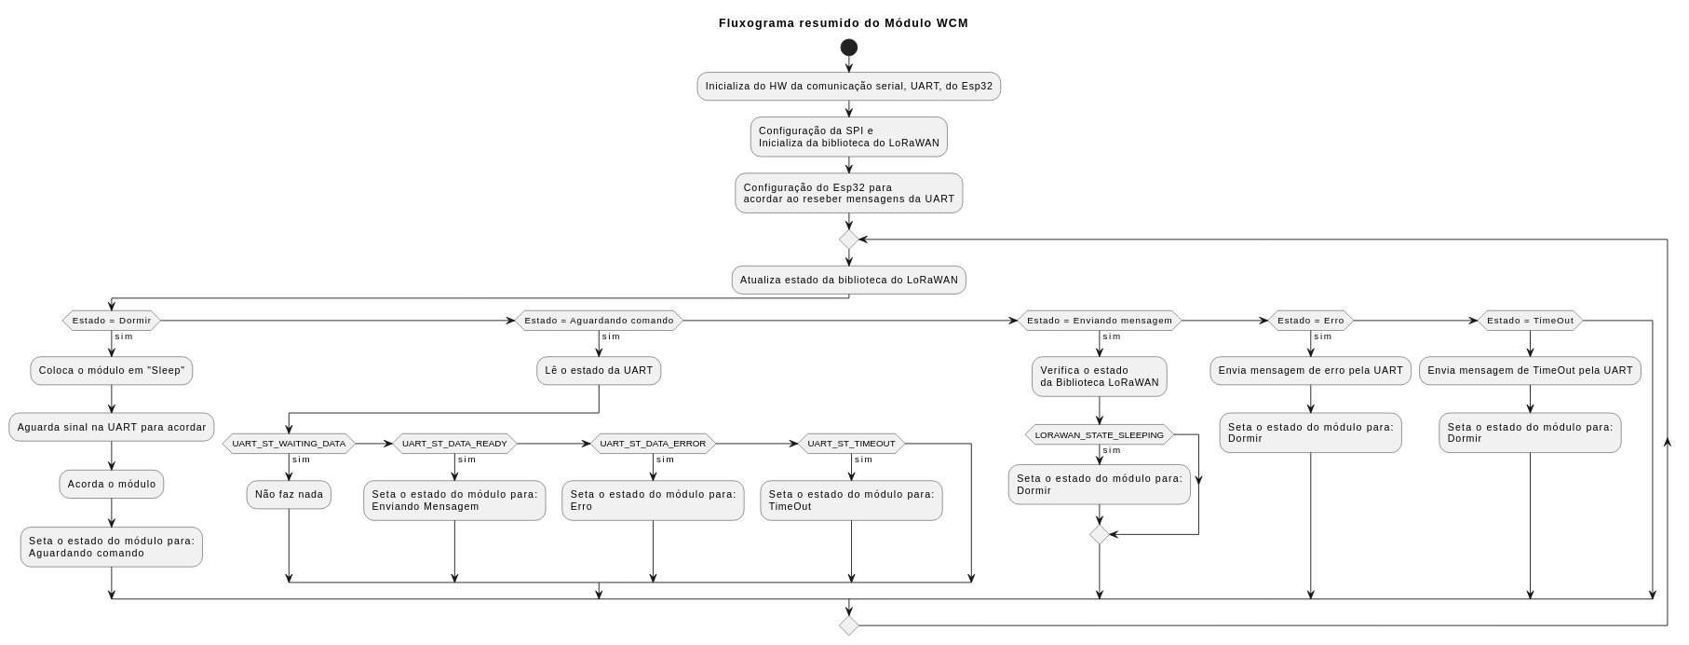
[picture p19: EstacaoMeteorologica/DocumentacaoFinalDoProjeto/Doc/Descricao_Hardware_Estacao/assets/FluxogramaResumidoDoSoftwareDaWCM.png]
Fluxograma Resumido do Software da WCM


## Estratégia de Consumo de Energia
Utilizou-se, no desenvolvimento do firmware, uma abordagem para reduzir ao máximo o consumo de energia. Consegui-se, com isso, uma redução expressiva de consumo. Ainda assim, outros avanços podem ser obtidos através da utilização de um MPU único com modo deep sleep.  
Cabe ressaltar que a utilização de estratégias de sleep mode podem ocasionar efeitos colaterais, como a demora na obtenção de novas aquisições.  

Abaixo temos uma amostra de como ficou o consumo do MPU e do WCM. Pode-se notar claramente os estados:  
- MPU e WCM em "sleep";
- MPU ativo e WCM em "sleep";
- MPU e WCM ativos (curto espaço de tempo);
- MPU e WCM ativos, WCM transmitindo;
- MPU e WCM ativos, com alguns transientes, provavelmente por ativação do modo de escuta do rádio;
- Entrada em sleep mode do WCM e na sequencia do MPU;
- MPU e WCM em sleep.

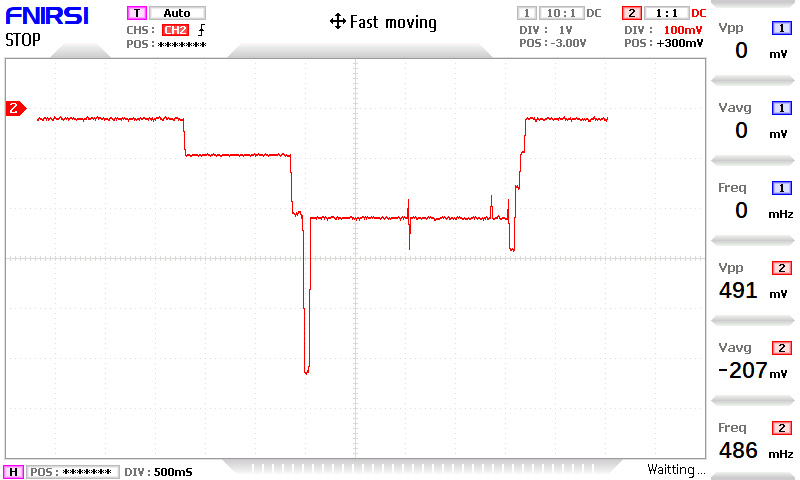
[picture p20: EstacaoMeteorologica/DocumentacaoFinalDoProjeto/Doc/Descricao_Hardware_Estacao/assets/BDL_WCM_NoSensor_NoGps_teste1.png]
Consumo do MPU e WCM


Alguns pontos relevantes para a redução do consumo do RP2040, são:  
- Desativação dos clocks desnecessários;
- Redução do Clock principal de 125MHz para 12MHz;
- Desativação dos PLLs.

Com relação ao Esp32-C3, a abordagem de redução de consumo contituiu-se no uso de light sleep, presente neste MPU.

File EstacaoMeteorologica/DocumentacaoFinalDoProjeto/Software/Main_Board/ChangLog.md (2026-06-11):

# Estação Meteorológica LoRa/LoRaWAN
## Next:
- Melhorar estrutura do loop_printf quando o USB está off
- Manter histórico na flash do fcnt
- Verificar se e possivel melhorar a estabilidade da USB no modo OFF-ON
- rever funcionamento GPS, principalmente durante sleep
- Compartilhar código com esp32-c3

- wcm melhorar protocolo de envio/recebimento dos dados para o WCM
    - Aguardar OK de acordado
    - Criar Tipos de Mensagem de retorno
- Remover driver ina
- Doxigen pendentes:
    - aq_data_gps
    - fcnt
    - store
    
1-avaliar payload de 32 bits
3-melhoria comunicação esp32
mudar fcnt de 16 para 32bits? menu e wcm
Corrigir o build:0037 para funcionar no debug

## Build:0042 - 07/04/2026
- Add modos channel AUTO 0-7, 8-15 e 0-15

## Build:0041 - 19/02/2026
- Corrigido erro da  correção do bh1750

## Build:0040 - 18/02/2026
- Atualização do README.md para o WCM
- desativado START_SEND_WITH_FIX_DATA
- Correção, em caso de falha na leitura i2c do bh1750, repetia o último valor, não reportava o erro;

## Build:0039 - 15/02/2026
- Correção do número da versão

## Build:0038 - 15/02/2026
- Ativado doxigen

## Build:0037 - 15/02/2026
- Add config para transmitir fcnt do ABP com 4 ou 8 Bytes

## Build:0036 - 12/02/2026
- Desativado NoFlash, pois é necessário para funcionar o storage
- write flash com 8 bytes travava, usando 256 bytes

## Build:0035 - 12/02/2026
- Add file fcnt
- Removido: LorawanAbpPar.fcnt

## Build:0034 - 12/02/2026 - Rev02
- Version = 0.00.02
- removido:
    ActiveSensors.battery
    AqData.battery
    files aq_data_bat

## Build:0033 - 11/02/2026
- Doxigen:
    - hw_sleep

## Build:0032 - 08/02/2026
- Correção, faltava desligar o pll_sys no sleep

## Build:0030 - 08/02/2026
- refactory da rotina de geração do CMD do arquivo wcm.c
- Add opção de adicionar checksum ao payload
- Add janela para pressionar botão
- Doxigen:
    - wcm
    - storage

## Build:0029 - 07/02/2026
- Move conteudo das rotinas que estavam dentro do dir src/gps para aq_data_gps

## Build:0028 - 07/02/2026
- Doxigen:
    - main
    - aq_data
    - aq_data_ad
    - aq_data_bmep280
    - aq_data_lux
    - buttons_and_leds
    - code_config
    - est_config
    - loop_printf
    - menu-conf
    - wrap_watchdog
    
## Build:0027 - 07/02/2026
- gps rever printf para loop_print
- Criação do ChangeLog.md, estes dados foram para lá
- README.md com a descrição do funcionamento do programa (iniciado)
- Inicio da documentação com Doxygen

## Build:0026 - 06/02/2026
- Pequenos ajustes no MPU Temp
- Correção da primeira leitura do BME280
- BMEP280 suporta leitura tanto no BME280 como no BMP280
- Correçao nas defines de DEBUG do code_config.h

## Build:0025 - 06/02/2026
- Corrigido msg de erro do bme280
- Ajustado layout do printf:
  - de dados que serão enviados ao WCM
  - aq_data_lux
  - aq_data_ad
- Redução do consumo do BH1750 de 115uA para 3,7 uA

## Build:0024 - 01/02/2026
- USB TurnOn parametrizado
- Correção do calculo da pressão de bme280

## Build:0023 - 31/01/2026
- Correções do watchdog

## Build:0022 - 30/01/2026
- Opção de sempre ativar o menu após reset (util para detectar resets/travamentos)
- Add prints de parâmetros de compilação
- criação da rotina get_t_now() para que timer_hw->timerawl se transforme em uma variável de 64 bits
- Menu_conf: revisão de testos, limitado o modo LoRa em ABP e OTAA
- Botão Config, inverte a função do always menu
- Add Watchdog

## Build:0021 - 28/01/2026
- Adicionado no menu/sistema um parâmetro de calibração vsys_k_10000
- removido antigos src do bmp280
- rotinas i2c do luximetro revisto o blocking por timeout

## Build:0020 - 28/01/2026
- Luximetro:
    - foi reduzida a sensibilidade para 31/69 para poder suportar incidencias diretas do sol
    - foi adicionado no menu/sistema um parâmetro de calibração lux_k_10000
    - removido o antigo driver bh1750
- Correções no WCM.c para o VSys

## Build:0019 - 27/01/2026
- correção: Não salvava a versão da configuração
- Unificada as rotinas de ad: cpu temp e vsys
- corrigido a falta de? adc_gpio_init(ADC_VSYS_GPIO);

## Build:0018 - 24/01/2026
- Add aq_data_bmep280.h
Obs.: - roda só o bmep280 para testes e está com prints de debug
      - Está com o debug ativo e só em flash

## Build:0017 - 22/01/2026
- Add VSys

## Build:0016 - 17/01/2026
- Add ao Payload lux
- Add no estado original da flash, no printf e no menu_conf
- Refactore sensor tbo por cpu_temp
- Change default channel to 8

## Build:0015 - 15/01/2026
- Add no log das chamadas ao WCM o char que retornou
- Add driver do luximetro bh1750
- Add Timeout de transmissão

## Build:0014 - 14/01/2026
- Rotina de on-off do PLL USB agora leva em conta não só a USB mas também se o AD está On ou Off
- Implementada rotinas para comunicação LoRa e LoRaWANa OTAA
- Corrigido ordem do address no ABP

## Build:0013 - 14/01/2026
- Removido arquivos flash .h e .c

## Build:0012 - 14/01/2026
- Migrado da estação original as rotinas storage.h .c
- Add Funcionalidade no menu para Read Write configuração e clear all

## Build:0011unic - 13/01/2026
- Códigos default da instalação da Unicamp

## Build:0011 - 13/01/2026
- Correções no sensor CPU temp

## Build:0010 - 13/01/2026
- Criado: int aqdata_init_power_on( AqData *value)
- Transformado em parâmetro a interrupção da UART do GPS
- No menu:
  - Add CPU temp
  - Mudança de "Sleep time" para "Sampling time"

## Build:0009 - 11/01/2026
- Pequenas melhorias no menu_conf.c
- Adicionado controle de log(ativação) da USB: OFF, ON, OFF-ON
- Adicionado controle de LEDs acessos para reduzir consumo
- Obs.: wcm_send está documentado

## Build:0008- 10/01/2026
- replace printf por loop_printf para printf s que são acessados dentro do loop, para poder desativar a USB

## Build:0007- 10/01/2026
- Refactory variáveis de configuração
- Add Mode Lora
- Revisto menu

## Build:0006- 10/01/2026
- Transmitindo LoRaWAM ABP
- Baixo consumo quando em idle 

## Build:0004- 04/01/2026
- Menu parcialmente funcional para LoRaWAN ABP variaveis do lorawan
- Rotinas com sensores de:
    - Bateria
    - Pressão, temperatura (BMP280)
    - GPS
- Sleep mode
- Comunicação com WCM para envio LoRaWAN ABP

## Build:0002- 08/12/2025
- Add simple Sleep mode
- Add simple Bat    Driver
- Add simple Bmp280 Driver
- Add simple GPS    Driver
- Add print do que deve ser enviado pelo loRa
- Add Debug Mode

## Build:0001- 05/12/2025
- inicio do menu
- estrutura do main e todos os arquivos necessários
- Estrutura básica da configuração
- Estrutura básica dos dados
- Definição do payload físico:
[Byte de controle] [dados....] [Byte de controle] [dados....] [Byte de controle] [dados....]

BC[0] ==> Byte de controle 1 define o que está presente e o tamanho de cada item

Bit 0 ==> Battery Level, Add 1 Byte no Payload
    Add 1 Byte: Batery Level 0-100 %, 0xFF ==> erro no sensor

Bit 1 ==> Bme280, Add 5 Bytes no Payload,
    Add 1 Byte:  Umidade:       0 -  100 %,       Resolução  0.5 %
        0xFF ==> erro no sensor
        0x00 ==>   0.0 %
        0x01 ==>   0.5 %
        0x02 ==>   1.0 %
        0xC8 ==> 100.0 %
        Umidade(em %) = Valor * 0.5;

    Add 2 Bytes: Temperatura: -40 -  +85 Celsius, Resolução 0.01 C
        0x7FFF ==> erro no sensor
        0xD8F0
        -10000 ==> -100.00 C
        0xFFFF ==>   -0.01 C
        0x0000 ==>    0.00 C
        0x0001 ==>    0.01 C
        0x2710
         10000 ==> +100 0.00 C
        Temperatura (em Celsius) = Valor * 0.01
        T = V / 100

    Add 2 Bytes: Pressão:     300 - 1100 hPa,     Resolução 0.02 hPa
        0xFFFF ==> erro no sensor
        0x0000 ==> 1200.00 hPa
        0x0001 ==> 1199.98 hPa
        0xAFC8
         45000 ==>  300.00 hPa
        Pressão(em hPa) = (60000 - Valor) * 0.02
    
Bit 2 ==> GPS, Add 10 Bytes
    Add x 4 Bytes Latitude
        0x7FFF FFFF ==> erro no sensor
        latitude em graus = valor * 512 /(2^32)
    Add x 4 Bytes Longitude
        0x7FFF FFFF ==> erro no sensor
        latitude em graus = valor * 512 /(2^32)
    Add x 2 Bytes Altitude
        0x7FFF ==> erro no sensor
        atitude em metros = valor * 0.1

A serem definidos:
Bit 3 ==> Luxímetro (2 bytes)
Bit 4 ==> UV índex (1 Byte)
Bit 5 ==> vento(direção (1byte, 2 graus de resolução) e velocidade (1byte, resolução de 0,2 m/s para vMax  51m/2 ou 0,72km/h com Vmax 183 km/h)) 
Bit 6 ==> Pluviômetro
Bit 7 ==> 

BC[1] ==> Byte de controle 2, pode ou não existir para definir outros campos com o byte de controle 1

## Build:0000-Base 05/12/2025
Wizard Raspberry Pi Pico para Pico

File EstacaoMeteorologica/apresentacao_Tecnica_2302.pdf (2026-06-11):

# Estação Meteorológica IoT

Contexto e Objetivos
- Âmbito Embarcatech
- Implantação distribuída no campus da Unicamp
- Projeto open source
- Requisitos técnico e não funcionais

# Estação Meteorológica IoT

Requisitos
- Sensores de temperatura, umidade, pressão e luminosidade
- Localização por GPS
- Autonomia energética
- Comunicação LoRaWAN
- IP68
- Visualização dos dados
- Escalabilidade

# Estação Meteorológica IoT

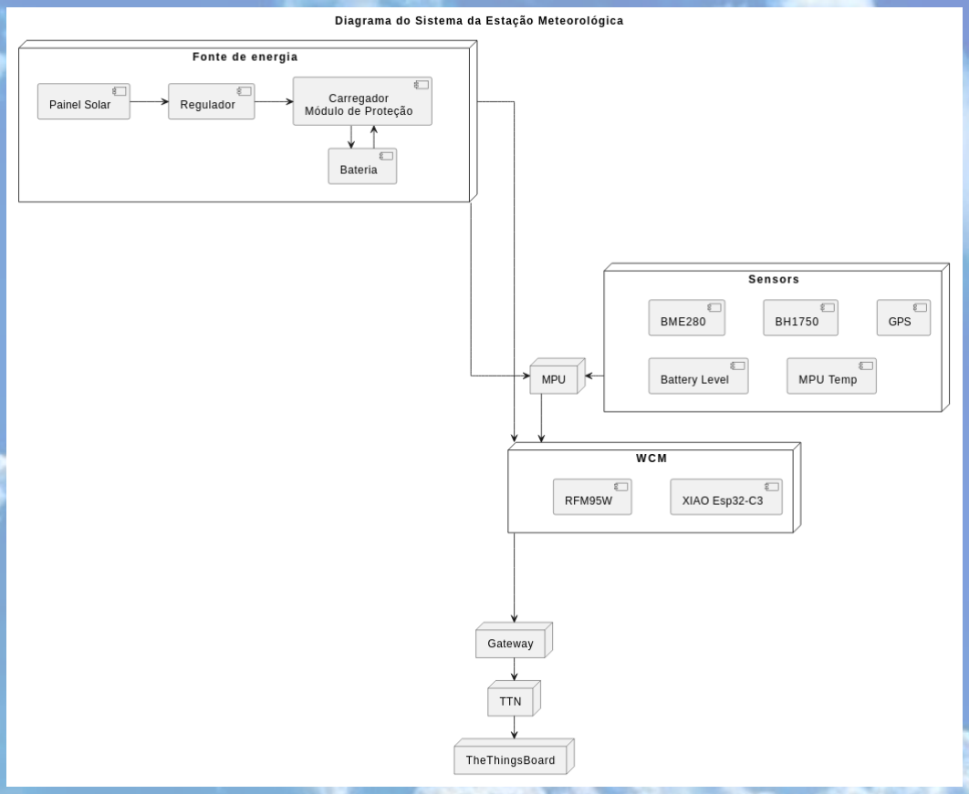
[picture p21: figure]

Arquitetura
- Sensoriamento
- Processamento
- Comunicação
- Backend
- Aplicação

# Estação Meteorológica IoT

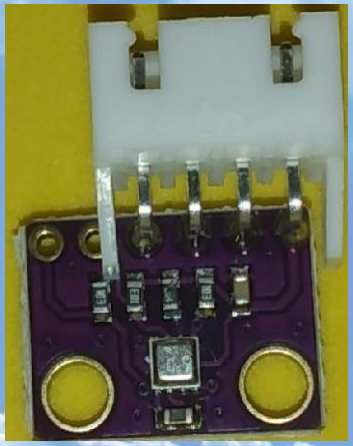
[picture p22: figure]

Camada de Sensoriamento

- BME280
- BH1750
- GPS
- Tensão da bateria
- Temperatura interna do MCU

# Estação Meteorológica IoT

Camada de Processamento

- RP2040
- Modularização do firmware
- Simulação de sleep mode via software:
- Redução de clock
- Desligamento de PLL

# Estação Meteorológica IoT

Decisão Crítica de Engenharia – BitDogLab --> PCB dedicada

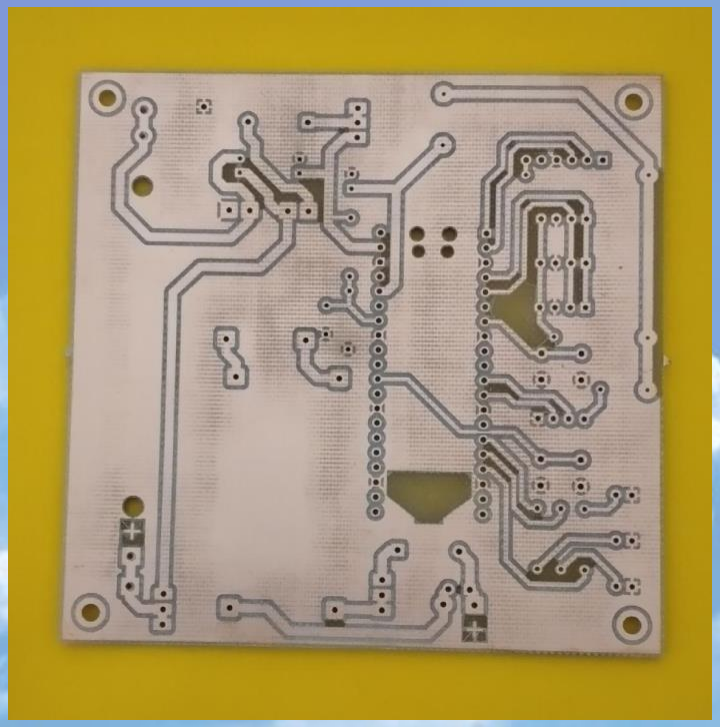
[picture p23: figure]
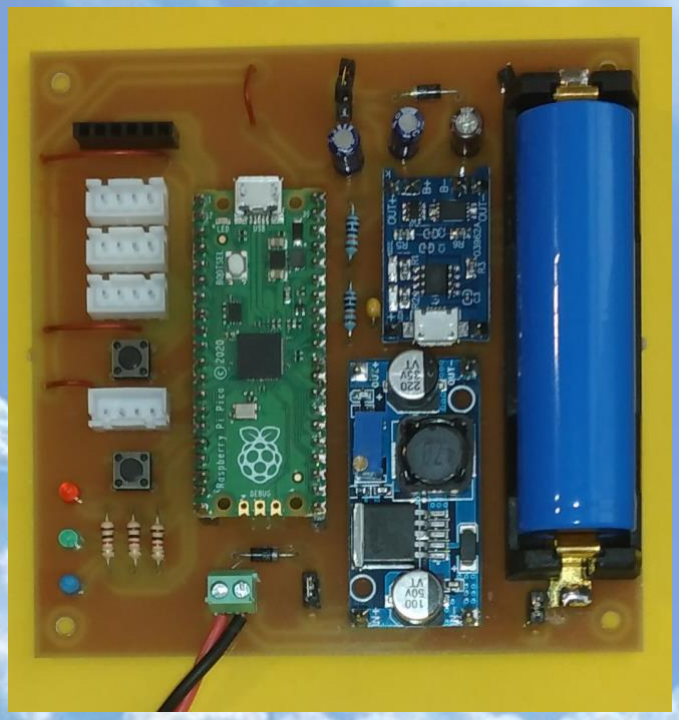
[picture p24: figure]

# Estação Meteorológica IoT

Camada de Comunicação

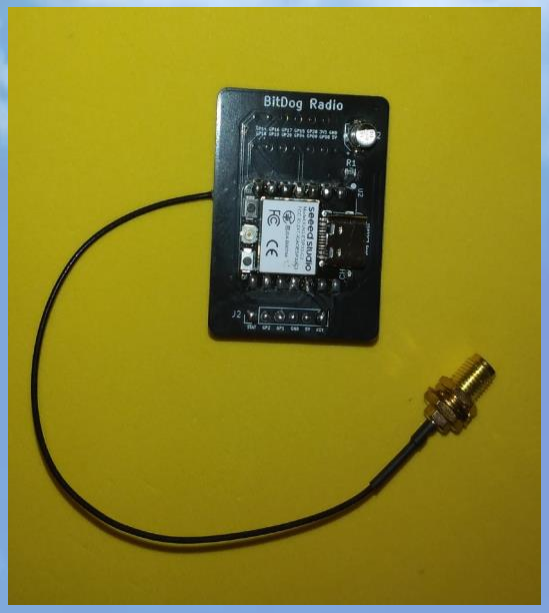
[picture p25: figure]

- WCM (ESP32-C3 + RFM95W)
- LoRaWAN ABP
- Lite Sleep Mode
- Payload otimizado


# Estação Meteorológica IoT


Gerenciamento Energético - Resultado da otimização

# Estação Meteorológica IoT

Backend

- Gateway RAK7289V2
- TTN
- Cloudflare
- Raspberry Pi 5
- ThingsBoard
- PostgreSQL

# Estação Meteorológica IoT


Evidências em Campo

# Estação Meteorológica IoT


TRL

- TRL 4 - componente e processos
- TRL 5 - teste de integração em laboratório
- TRL 6 - protótipo em laboratório
- TRL 7 - protótipo em campo

# Estação Meteorológica IoT

Conclusão Técnica

- Sistema validado
- Arquitetura consolidada
- Escalável
- Preparado para operação contínua
- Custo estimado de R$ 695,00

# Estação Meteorológica IoT

## OBRIGADO!

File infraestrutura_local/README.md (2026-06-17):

# Infraestrutura Local

Esta pasta contém evidências de operação e monitoramento da infraestrutura local de coleta, processamento e armazenamento de dados meteorológicos.

---

## Visão geral

A infraestrutura é executada em uma **Raspberry Pi 5 (8 GB RAM, 256 GB SSD NVMe)** e opera de forma totalmente local, sem dependência de serviços externos em nuvem. Os seguintes serviços são executados em contêineres Docker:

| Serviço | Função |
|---|---|
| ChirpStack v4 | Servidor de rede LoRaWAN — gerenciamento de dispositivos e processamento de uplinks |
| Mosquitto | Broker MQTT — integração ChirpStack → ThingsBoard |
| ThingsBoard CE 4.3.0 | Armazenamento, visualização e exportação dos dados |
| PostgreSQL | Banco de dados relacional (backend do ThingsBoard) |

O acesso remoto é disponibilizado via **Cloudflare Tunnel**, sem exposição direta de portas na rede institucional.

---

## Período de operação e uptime

| Métrica | Valor |
|---|---|
| Início da coleta de dados | 02/02/2026 |
| Uptime do servidor (última reinicialização) | 5 semanas, 5 dias |
| Uptime dos contêineres Docker | Up 5 weeks (todos os serviços) |

Medido via `uptime -p` e `docker ps --format "table {{.Names}}\t{{.Status}}"`:

```
up 5 weeks, 5 days, 23 hours, 45 minutes

chirpstack-docker-chirpstack-gateway-bridge-1   Up 5 weeks
chirpstack-docker-chirpstack-rest-api-1         Up 5 weeks
chirpstack-docker-chirpstack-1                  Up 5 weeks
chirpstack-docker-postgres-1                    Up 5 weeks
chirpstack-docker-redis-1                       Up 5 weeks
chirpstack-docker-mosquitto-1                   Up 5 weeks
tb-thingsboard-ce-1                             Up 5 weeks
tb-postgres-1                                   Up 5 weeks
```

Os dados históricos estão disponíveis publicamente no HuggingFace:
👉 https://huggingface.co/datasets/adr1t0s/estacao-meteorologica

---

## Recursos do servidor

Monitoramento realizado via painel sysadmin do ThingsBoard em 13/06/2026.

| Recurso | Valor |
|---|---|
| CPU | ~1% (4 cores) |
| RAM | ~46% de 8 GB |
| Disco | ~20% de 234 GB |

O consumo de recursos permaneceu estável ao longo do dia, sem picos significativos.

Recursos do sistema
Recursos — histórico 24h

---

## Dispositivos ativos e mensagens transportadas

Período de referência: **11/06/2026 12:00 a 12/06/2026 00:00**

| Métrica | Valor |
|---|---|
| Dispositivos ativos | **4** (constante ao longo do período) |
| Transport messages por intervalo de 30 min | ~372 |
| Transport messages por hora | ~744 |

Atividade — dispositivos 12h
Atividade — mensagens 12h

---

## Mensagens processadas pela Rule Engine

Estatísticas do nó **Save Timeseries** da Rule Chain principal (ChirpS Root) no mesmo período.

| Métrica | Valor |
|---|---|
| Mensagens processadas por hora | ~182–187 |
| Esperado teórico (4 estações) | 186 |
| Erros ocorridos | **0** |

Os valores observados são consistentes com a configuração de transmissão das estações (em02, em06, em10 a 60 s e em04 a 600 s), confirmando que nenhuma mensagem foi descartada pela infraestrutura.

Rule Engine Statistics

---

## Latência de processamento

A latência foi estimada com base em dois componentes mensuráveis:

**1. Airtime LoRaWAN** — calculado para um pacote real da em02 (20 bytes de payload, SF7, BW 125 kHz, CR 4/5):

| Parâmetro | Valor |
|---|---|
| Payload | 20 bytes |
| Spreading Factor | SF7 |
| Bandwidth | 125 kHz |
| Code Rate | CR 4/5 |
| Airtime | **~56.6 ms** |

**2. Processamento no servidor** — medido via Debug do nó Save Timeseries:

| Parâmetro | Valor |
|---|---|
| ChirpStack (gwTime → nsTime) | ~16 ms |
| Save Timeseries (IN → OUT) | 7–37 ms |

**Latência total estimada (airtime + servidor): ~80–110 ms**

> Nota: o timestamp `aq_timestamp_ms` gerado pela estação não foi utilizado para este cálculo por estar sujeito a drift do relógio interno do microcontrolador.

---

## Comportamento após reinicialização e perda de conexão

### Reinicialização do sistema

Medido via `systemd-analyze blame`:

```
11.160s docker.service
 5.995s NetworkManager-wait-online.service
 5.991s cloudflared.service
```

Os três serviços inicializam em paralelo. Como os contêineres Docker comunicam-se internamente e não dependem da rede externa para operar, o tempo dominante é **~11s** até os serviços locais estarem operacionais. O acesso remoto via Cloudflare Tunnel fica disponível em até **~6s adicionais**. Todos os serviços estão configurados com `restart: always` no Docker Compose.

### Perda temporária de conexão com a internet

Testado desligando e religando a interface de rede via `nmcli`:

```bash
start=$(date +%s%3N); sudo nmcli networking off; sleep 10; sudo nmcli networking on; \
while ! ping -c1 8.8.8.8 &>/dev/null; do sleep 1; done; \
end=$(date +%s%3N); echo "Recovery time: $((end-start)) ms"
# Recovery time: 15478 ms
```

O resultado de 15478 ms inclui 10s de espera forçada do script. O tempo real de recuperação de conectividade após religar a rede foi de **~5.5s**. Durante todo o período, a coleta e o armazenamento local permanecem ininterruptos — apenas o acesso externo via Cloudflare Tunnel é afetado temporariamente.

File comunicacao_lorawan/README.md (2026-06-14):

# Comunicação LoRaWAN — Estações Meteorológicas Unicamp

Esta pasta contém os dados de telemetria LoRaWAN coletados pelas estações meteorológicas instaladas no campus da FEEC/Unicamp, juntamente com informações sobre a configuração da rede e a localização dos dispositivos.

---

## Estações

A rede conta com **4 estações simultâneas** operando em modo ABP Classe A sobre LoRaWAN AU915 (sub-bandas 0 e 1, canais 0–15).

| Estação | Dist. GW (m) | Canal | Freq. (MHz) | rfChain | SF | DR | TX Power (dBm) | BW (kHz) | Intervalo (s) | Pacotes (24h) | PDR (%) | RSSI médio (dBm) | SNR médio (dB) | GPS |
|---|---|---|---|---|---|---|---|---|---|---|---|---|---|---|
| em02 | 35 | 8 | 916.8 | 2 | SF7 | DR5 | 14 | 125 | 60 | 1440 | 100.0 | -81.0 | 13.2 | Sim |
| em04 | 45 | 8 | 916.8 | 2 | SF7 | DR5 | 14 | 125 | 600 | 143 | 99.3 | -94.9 | 11.7 | Sim |
| em06 | 606 | 6 | 916.4 | 1 | SF7 | DR5 | 14 | 125 | 60 | 1401 | 97.3 | -103.2 | 1.3 | Não |
| em10 | 605 | 6 | 916.4 | 1 | SF10 | DR2 | 14 | 125 | 60 | 1439 | 99.9 | -89.3 | 10.1 | Não |

### Coordenadas

| Estação | Latitude | Longitude |
|---|---|---|
| em02 | -22.822205 | -47.065704 |
| em04 | -22.822132 | -47.065639 |
| em06 | -22.819542 | -47.071064 |
| em10 | -22.818361 | -47.062000 |
| Gateway | -22.822360 | -47.066000 |

> **em04:** o intervalo de 600 s foi configurado para gestão energética, uma vez que o módulo GPS apresenta consumo elevado, reduzindo a autonomia da bateria durante períodos sem geração solar.  
> **em06 / em10:** operam sem GPS, o que reduz o consumo e permite maior autonomia em campo.

---

## Gateway

| Parâmetro | Valor |
|---|---|
| Modelo | RAK7289CV2 |
| Localização | FEEC – Edifício H, Unicamp |
| Latitude | -22.82236 |
| Longitude | -47.06600 |

---

## Configuração LoRaWAN

| Parâmetro | Valor |
|---|---|
| Região | AU915 |
| Sub-bandas | 0 e 1 (canais 0–15) |
| Método de ativação | ABP (Activation By Personalization) |
| Classe | A |
| Code Rate | CR 4/5 |

---

## Arquivos de telemetria

Os arquivos CSV contêm os dados de telemetria brutos exportados via API REST do ThingsBoard. Cada arquivo corresponde a uma estação e a um período de 24 horas.

| Arquivo | Estação | Período |
|---|---|---|
| `telemetria_em02_2026-06-12_00h00_2026-06-13_00h00.csv` | em02 | 12/06/2026 |
| `telemetria_em04_2026-06-08_00h00_2026-06-09_00h00.csv` | em04 | 08/06/2026 |
| `telemetria_em06_2026-06-12_00h00_2026-06-13_00h00.csv` | em06 | 12/06/2026 |
| `telemetria_em10_2026-06-12_00h00_2026-06-13_00h00.csv` | em10 | 12/06/2026 |

### Colunas

| Coluna | Descrição | Unidade |
|---|---|---|
| `Data/Hora` | Timestamp de recepção no servidor | UTC |
| `RSSI (dBm)` | Received Signal Strength Indicator | dBm |
| `SNR (dB)` | Signal-to-Noise Ratio | dB |
| `Frame Counter` | Contador de quadros LoRaWAN (fCnt) | — |
| `Data Rate` | Data Rate LoRaWAN (DR0–DR5, AU915) | — |

---

## Mapa de localização

Localização das estações

Localização do gateway RAK7289CV2 e das quatro estações meteorológicas no campus.

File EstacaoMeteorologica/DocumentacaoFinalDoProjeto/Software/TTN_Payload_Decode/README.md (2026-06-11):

# Para testar localmente  

1. Instalar ambiente JavaScript
	- $ node -v
	- $ sudo apt install nodejs npm

2. Rodar o código:
	- $ node decoderXXXX.js

# Builds

- 0006:
	+ Correção no tratamento de erro para pressão inválida
	+ Documentação aprimorada.

- 0005:
	+ Correção do fator de luminosidade x4

- 0004:
	+ Add parâmetro da tensão da bateria

# Documentação do Payload
Encontra-se no início do arquivo decoder0006.js

# Instalação no TTN
Só não deve ser instalada a parte do arquivo descrita como TESTES

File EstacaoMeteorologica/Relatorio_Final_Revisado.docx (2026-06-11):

INSTITUTO HARDAWARE BR – EMBARCATECH

Estação Meteorológica IoT

Autores: Antonio Crepaldi – Carlos Perez – Ricardo Furlan

22/02/2026


# 1. Introdução

O monitoramento ambiental contínuo é essencial para pesquisas científicas, gestão de recursos naturais e tomada de decisão baseada em dados climáticos. No entanto, em regiões remotas ou com infraestrutura de comunicação limitada, a coleta de dados meteorológicos enfrenta desafios como ausência de conectividade convencional, restrições energéticas e altos custos operacionais. Nesse contexto, instituições acadêmicas, centros de pesquisa e gestores ambientais necessitam de soluções autônomas, de baixo consumo energético e com capacidade de comunicação de longo alcance.

Este projeto propõe o desenvolvimento de uma estação meteorológica IoT de baixo consumo energético, baseada em comunicação LoRaWAN, com o objetivo de viabilizar o monitoramento ambiental remoto de forma eficiente, escalável e economicamente acessível. A relevância da proposta está na crescente demanda por sistemas IoT capazes de operar de maneira autônoma por longos períodos, reduzindo intervenções humanas, custos de manutenção e dependência de infraestrutura convencional de rede.

Para atender a esses requisitos, foi desenvolvida uma estação meteorológica autônoma mostrada na figura 1 a seguir, capaz de medir múltiplos parâmetros ambientais, transmitir dados por meio da rede LoRaWAN e operar com bateria recarregável associada a painel solar, garantindo autonomia energética prolongada. O desenvolvimento envolveu o projeto de hardware dedicado (incluindo a elaboração da placa de circuito impresso – PCI), a implementação de firmware embarcado otimizado para baixo consumo, a integração com a rede LoRaWAN e a realização de validação experimental em ambiente real, a fim de verificar desempenho, alcance de comunicação e eficiência energética.


Fig. 1: Estação operando em campo.

# 2. Requisitos do Projeto

O Programa Embarcatech – Fase 3 estabeleceu como objetivo o desenvolvimento de um sistema embarcado IoT capaz de realizar monitoramento ambiental remoto, com comunicação de longo alcance, autonomia energética e integração a uma plataforma de visualização de dados.

O projeto desenvolvido atende a essas diretrizes ao implementar uma estação meteorológica autônoma baseada em LoRaWAN, capaz de coletar, transmitir e disponibilizar dados ambientais em ambiente web, operando com baixo consumo energético e infraestrutura própria de alimentação.

Os requisitos consolidados são descritos a seguir:

## 2.1 Requisitos Funcionais

Os requisitos funcionais descrevem as funcionalidades que o sistema deve executar.

Medição de Parâmetros Ambientais e do sistema

O sistema deve ser capaz de realizar as seguintes medições:

- Temperatura do ar: medição em graus Celsius (°C);
- Umidade relativa do ar: medição em porcentagem (%);
- Pressão atmosférica: medição em hecto pascal (hPa);
- Luminosidade: medição em lux (lx);
- Localização geográfica: obtenção de coordenadas geográficas (latitude, longitude e altitude);
- Tensão da bateria: medição em volts (V), para monitoramento do sistema de alimentação;
- Temperatura interna da MCU (Micro Controler Unity).

Coleta de Dados

- O sistema deve realizar a leitura dos sensores habilitados em intervalos configuráveis (por exemplo, 1 minuto, 10 minutos ou outro valor pré definido no firmware).

Transmissão de Dados

- O sistema deve transmitir os dados coletados por meio do protocolo LoRaWAN para o gateway RAK7289V2 instalado na FEEC.

Visualização e Análise de Dados

- Os dados transmitidos devem ser armazenados e disponibilizados para visualização na plataforma TheThingsBoard, permitindo a criação de dashboards personalizáveis para análise das variáveis monitoradas.

## 2.2 Requisitos Não Funcionais

Os requisitos não funcionais descrevem restrições e atributos de qualidade do sistema.

Modularidade

- O sistema deve permitir a adição ou substituição de sensores sem necessidade de reformulação completa do hardware, possibilitando sua adaptação a diferentes aplicações.

Escalabilidade

- A solução deve permitir a implantação de múltiplas estações em diferentes locais, com integração centralizada dos dados em uma mesma plataforma.

Autonomia Energética

- O sistema deve operar de forma autônoma com baixo consumo energético, utilizando bateria de lítio recarregável associada a painel solar.

Robustez Física e Resistência a Intempéries

- O encapsulamento eletromecânico deve oferecer proteção contra condições climáticas adversas (chuva, poeira, umidade e exposição solar), atendendo ao grau de proteção IP68.

Manutenibilidade

- O sistema deve permitir manutenção simplificada e atualização de firmware em campo, minimizando intervenções complexas.

Segurança

- A transmissão de dados deve utilizar os mecanismos de segurança fornecidos pelo protocolo LoRaWAN, garantindo autenticação e criptografia básica das comunicações.

# 3. Arquitetura do Sistema

A figura 2 a seguir, mostra a arquitetura geral do sistema, destacando os elementos de energia, sensores e comunicação.


Fig. 2: Digrama da arquitetura geral do sistema.

O sistema é composto por seis camadas: Sensoriamento, Processamento, Comunicação, Recepção de Dados, Aplicação e Energia

## 3.1 Camada de Sensoriamento

A implementação consta dos seguintes sensores:

- Temperatura, umidade e pressão atmosférica (BME280) – figura 3 a seguir:


Fig. 3: BME280

- Luminosidade (BH1750) – figura 4 a seguir:


Fig. 4: BH1750

- GPS (GY-NEO6MV2) – figura 5 a seguir:


Fig. 5: GY-NEO6MV2

- Nível de bateria, via AD (Conversor Analógico Digital) e divisor resistivo;
- Temperatura interna do microcontrolador (RP2040).

## 3.2 Camada de Processamento

A camada de processamento é composta pelos seguintes elementos:

- Microcontrolador RP2040 (Raspberry Pi Pico);
- Estratégias de baixo consumo (desativação de funcionalidades desnecessárias e redução de clock do microcontrolador);
- Estrutura modular do firmware.

## 3.3 Camada de Comunicação

A camada de comunicação é constituída por:

- Módulo WCM - Wireless Communication Module (XIAO ESP32-C3 e RFM95W);
- Implementação de Lite Sleep Mode;
- Protocolo de comunicação LoRaWAN ABP;
- Payload otimizado para redução do Time on Air (ToA).

Na figura 6 a seguir, aparece o módulo WCM com seu respectivo cabo de conexão de antena.


Fig. 6: Módulo WCM com seu respectivo cabo de conexão de antena.

O hardware do módulo WCM foi desenvolvido no projeto de iniciação científica da FEEC: "Fruett et al., An Open-Source LoRaWAN Architecture for Educational and Scientific IoT Applications: A Case Study Using BitDogLab".

## 3.4 Camada de Recepção de Dados

A camada de recepção de dados é constituída por:

- Gateway RAK7289V2 (Este item foi definido pelo cliente no início do projeto);
- Servidor na nuvem, The Things Network – TTN (Este item também foi definido pelo cliente no início do projeto).

Obs.: A configuração do gateway e TTN foe desenvolvida no projeto de iniciação científica da FEEC: "Fruett et al., An Open-Source LoRaWAN Architecture for Educational and Scientific IoT Applications: A Case Study Using BitDogLab".

## 3.5 Camada de Aplicação

A camada de aplicação envolve:

- Servidor local (Raspberry Pi 5);
- Persistência de dados com PostgreSQL;
- TheThingsBoard com dashboards individuais e comparativos;
- Acesso via Cloudflare.

Obs.: Esta camada também foi desenvolvida no projeto de iniciação científica da FEEC: "Fruett et al., An Open-Source LoRaWAN Architecture for Educational and Scientific IoT Applications: A Case Study Using BitDogLab"

## 3.6 Camada de Energia

A camada de energia é constituída por:

- Painel solar RSM10P, figura 7 a seguir:


Fig. 7: Painel Solar RSM10P

- Regulador de tensão, figura 8 a seguir:


Fig. 8: Regulador de tensão

- Carregador e módulo de proteção da bateria, figura 9 a seguir:


Fig. 9: Carregador e módulo de proteção da bateria.

- Bateria.

# 4. Evolução Técnica do Projeto

Nesta seção são apresentados os principais aspectos técnicos relacionados ao desenvolvimento e à evolução do projeto, detalhando a implementação dos subsistemas de hardware, software e gerenciamento energético.

## 4.1 Desenvolvimento Individual dos Subsistemas

O desenvolvimento do sistema foi realizado inicialmente de forma a permitir a validação individual de cada subsistema antes da integração final. Foram desenvolvidos os seguintes subsistemas:

- Software para aquisição de dados dos sensores, para rodar no microcontrolador RP2040 (Apêndice 4.1 - Código-fonte do Rapberry Pico RP2040;
- Software para comunicação LoRaWAN utilizando o módulo WCM, para rodar no microcontrolador ESP32-C3 (Apêndice 4.2 - Código-fonte do ESP32-C3);
- Estratégias de redução de consumo energético aplicadas aos microcontroladores RP2040 e ESP32-C3:
  - Para o RP2040 implementou-se a desativação de módulos periféricos desnecessários durante a operação. Nos intervalos entre aquisições de dados, foram aplicadas técnicas adicionais de economia de energia, como desativação do PLL (Phase-Locked Loop) e redução da frequência de clock da CPU.
  - Para o ESP32-C3 foi adotado o modo light sleep, reduzindo significativamente o consumo energético durante períodos de inatividade, mantendo a capacidade de retomada rápida para transmissão de dados.
- Sistema de carregamento de bateria com painel solar, garantindo autonomia energética.

## 4.2 Integração dos Subsistemas

Para a integração dos subsistemas foram desenvolvidos os seguintes itens:

### 4.2.1 Placa principal Dedicada

A concepção inicial da estação meteorológica previa a utilização da placa educacional BitDogLab versão 7, mostrada na figura 10. Entretanto, ao longo do desenvolvimento, observou-se que o consumo energético desnecessario na placa.


Fig. 10: BitDogLab Versão 7

A BitDogLab incorpora diversos periféricos embarcados como display OLED, matriz de LEDs RGB, microfone, amplificador de áudio e regulador 3,3 V, que permanecem consumindo energia mesmo quando não estão em uso. Além disso, o circuito de carregamento não energizava automaticamente a placa durante o processo de recarga.

Outro fator determinante para a mudança de arquitetura foi a necessidade de integração com um sistema de carregamento via painel solar, utilizando um carregador dedicado para a bateria.

Dessa forma, optou-se pelo desenvolvimento de uma placa dedicada, projetada especificamente para a aplicação proposta. A nova placa integra todos os elementos essenciais do sistema, incluindo:

- Microcontrolador RP2040;
- Circuito de carregamento de bateria;
- Regulador de tensão;
- Conector para bateria;
- Chaves de acionamento;
- Conectores dedicados para sensores e para o módulo WCM (Wireless Communication Module).

As figuras 11 e 12 apresentam o resultado final do layout e da placa montada.


Fig. 11: PCI – Cobre | Fig. 12: PCI Montada

Para o desenvolvimento do esquemático e do layout da placa principal foi utilizado o software KiCad, versão 9.0.2+dfsg-1. (Anexo 5.1 – Esquemáticos e PCI – Placa Principal).

### 4.2.2 Firmware da Estação Meteorológica

O firmware da estação meteorológica, disponível no Apêndice 4.1 - Código-fonte do Rapberry Pico RP2040, foi desenvolvido utilizando a IDE Visual Studio Code (VSCode), versão 1.104.1, com a extensão Raspberry Pi Pico versão 0.19.0.

A arquitetura do firmware foi estruturada em duas seções principais:

#### 4.2.2.1 Interface de Usuário

A interface de usuário foi projetada para permitir a configuração inicial da estação e a inicialização do sistema. A interação é realizada por meio de um menu acessado por terminal serial USB, oferecendo navegação intuitiva para definição de parâmetros operacionais, como mostrado na figura 13 a seguir.


Fig.13: Menu de configuração

Durante a operação normal, o modo de configuração pode ser reativado por meio do reset (botão Reset) do sistema combinado com o acionamento do botão de configuração (botão Config).

Além disso, LEDs coloridos foram implementados para indicar os diferentes estados de operação do sistema, tais como:

- Modo de configuração;
- Aquisição de dados;
- Comunicação;
- Modo de baixo consumo (sleep mode);
- Indicação de falhas.

Vide manual do usuário, Apêndice 1 - Manual do Usuário.

#### 4.2.2.2 Loop de Aquisição e Comunicação

O loop principal de operação foi desenvolvido com estrutura modular, visando facilitar manutenção e escalabilidaCaptura de tela em 2026-02-22 13-58-52de.

A aquisição dos sensores foi implementada com drivers padronizados, seguindo a estratégia:

- Energizar o sensor;
- Inicializar a aquisição;
- Realizar a leitura das grandezas;
- Colocar o sensor em modo de baixo consumo (sleep).

A rotina de comunicação com o módulo WCM também foi estruturada de forma modular, permitindo futura adaptação para novos modelos ou protocolos de comunicação.

### 4.2.3 Firmware do Módulo WCM (ESP32-C3)

O firmware do módulo de comunicação foi desenvolvido utilizando a Arduino IDE, versão 2.3.6, com as seguintes bibliotecas:

- LoRa by Sandeep Mistry – versão 0.8.0;
- MCCI LoRaWAN LMIC Library by IBM – versão 5.0.1.

O funcionamento do módulo WCM foi projetado com foco em eficiência energética. O ESP32-C3 permanece em modo de baixo consumo e é ativado quando recebe comunicação via UART proveniente da placa principal.

Após o despertar, o módulo:

- Recebe o comando de transmissão;
- Recebe o payload contendo os dados coletados;
- Realiza a transmissão via LoRaWAN;
- Retorna automaticamente ao modo de baixo consumo.

Essa estratégia minimiza o tempo ativo do módulo de rádio, reduzindo significativamente o consumo energético do sistema.

### 4.2.4 Estrutura mecânica da estação

Para a instalação em campo, a estação meteorológica utiliza um suporte único, estruturado a partir da montagem de 8 peças impressas em 3D com filamento ABS (Anexo 2 - Peças 3D). A união destas peças é feita através de 10 parafusos e 10 porcas, garantindo a sustentação robusta da caixa com a placa principal, da placa solar e dos sensores.

Este conjunto, mostrado na figura 14, é acoplado a uma estrutura metálica, construída em perfis de alumínio (material que pode ser substituído, desde que a adaptação à base do suporte seja mantida). A estrutura é fixada diretamente ao solo utilizando hastes metálicas para ancoragem, assegurando a estabilidade do sistema contra ventos e intempéries. O design permite o posicionamento da placa solar para obter a máxima eficiência de insolação, ao mesmo tempo em que ela atua como uma cobertura protetora para a caixa de componentes, abrigando-a contra a radiação solar direta e chuva.


Fig. 14: Componentes da estrutura mecânica

## 4.3 Construção e Montagem de Protótipos

Nesta etapa foram realizadas as atividades relacionadas à materialização física do projeto e à validação prática dos circuitos desenvolvidos.

Principais atividades executadas:

- Montagem física dos protótipos a partir das placas de circuito impresso (PCIs) desenvolvidas;
- Revisão e correção do layout da PCI com base nos testes iniciais e inconsistências identificadas;
- Substituição de componentes que foram fornecidos com problemas (módulo carregador da bateria e Diodo Schottky)
- Execução de testes funcionais dos subsistemas integrados;
- Instalação física do primeiro protótipo em ambiente externo para validação em campo;
- Mapeamento do sinal LoRaWAN em diferentes pontos do campus, com registro das medições para análise de cobertura (documentação apresentada no Apêndice 3 - Mapeamento do sinal LoRaWAN).

## 4.4 Construção de Novos Protótipos

Em vez da implantação distribuída, nesta etapa foram construídas duas novas unidades protótipo, com o objetivo de validar aspectos mecânicos, estruturais e de integração final do sistema.

Atividades realizadas:

- Montagem de dois novos protótipos funcionais a partir da versão revisada do hardware;
- Construção de uma unidade completa com caixa de proteção, permitindo avaliar vedação, organização interna, dissipação térmica e adequação para instalação em ambiente externo;
- Montagem de uma segunda unidade contendo apenas a parte eletrônica, destinada a testes de bancada, depuração de firmware e validação elétrica;
- Verificação funcional de ambas as unidades, incluindo aquisição de dados, transmissão LoRaWAN e testes de alimentação.

Essa etapa permitiu validar não apenas o funcionamento eletrônico, mas também aspectos construtivos e mecânicos importantes para futura implantação definitiva em campo.

## 4.5 Backend e Dashboards

Nesta etapa foi consolidada a infraestrutura de recepção, armazenamento e visualização dos dados.

Atividades desenvolvidas:

- Verificação da recepção dos dados no Gateway LoRaWAN, na plataforma TTN (The Things Network) e no TheThingsBoard;
- Validação da persistência dos dados, armazenamento histórico e integridade das informações;
- Desenvolvimento e configuração de dashboards para visualização em tempo real e análise histórica dos parâmetros monitorados.

## 4.6 Repositório Open Source

Com o objetivo de garantir organização, rastreabilidade e possibilidade de colaboração futura, foi estruturado um repositório dedicado ao projeto, veja Apêndice 0 – Diretório principal do projeto

Atividades realizadas:

- Criação de repositório exclusivo para o projeto;
- Organização dos diretórios em categorias distintas: Doc, Hardware e Software;
- Padronização da estrutura para facilitar manutenção, versionamento e eventual disponibilização como projeto open source.

# 5. Validação Final Integrada - Resultados Experimentais

Nesta seção são apresentadas as evidências experimentais que comprovam o funcionamento integrado do sistema, contemplando comunicação, autonomia energética e visualização dos dados em ambiente real.

## 5.1 Evidência de Comunicação

Foram realizados testes progressivos de validação da comunicação, desde ambiente simulado até operação real em rede LoRaWAN.

Testes com gateway simulado:

- A Figura 15 a seguir, é apresento o log da estação no momento do envio dos dados ao módulo WCM, evidenciando a geração e o encapsulamento do payload. As marcações em vermelho e verde se referem as transmissões distintas e os dados estão em formato hexadecimal.


Fig. 15: Log da estação

- A Figura 16 a seguir mostra a recepção dos dados pelo simulador de gateway, confirmando a integridade da transmissão ponto a ponto.


Fig. 16: Log do simulador de gateway

Testes em ambiente real:

- A Figura 17 a seguir, demonstra a chegada efetiva dos dados ao gateway LoRaWAN, validando a comunicação em campo.


Fig. 17: Mostra o Log no TTN dos dados recebidos pelo gateway

- A Figura 18 a seguir, apresenta os dados recebidos na plataforma TTN, incluindo a correta decodificação do payload, comprovando o funcionamentocompleto da cadeia de comunicação da aquisição até o backend.


Fig. 18: Mostra o Log no TTN dos dados enviados pelo end device

Esses resultados confirmam a confiabilidade da transmissão e a integridade das informações enviadas.

## 5.2 Evidencia de Autonomia Energética

A validação da autonomia energética foi realizada por meio de medições elétricas de tensões e correntes e análise do comportamento da bateria em operação real.

- A Figura 19 a seguir, apresenta o resultado da otimização de consumo do RP2040 e do módulo WCM. A corrente de alimentação foi medida por meio de resistor shunt, permitindo observar as variações de consumo ao longo dos ciclos de aquisição, transmissão e modo de baixo consumo. Quanto maior a magnitude negativa apresentada no gráfico, maior a corrente drenada pelo sistema.


Fig. 19: Consumo dinâmico da estação

- A Figura 20 a seguir apresenta gráfico extraído do dashboard, contendo dados de luminosidade e nível de carga da bateria com a estação operando ao ar livre. Observa-se correlação direta entre alta luminosidade solar e aumento do nível de carga, evidenciando o correto funcionamento do sistema de carregamento por painel solar, num condição extrema e atipica que é com o GPS ligado e transmitindo dados a cada 10 segundos.


Fig. 20: Dashboard da estação externa

Esses resultados demonstram a efetividade das estratégias de redução de consumo e a viabilidade da operação autônoma com energia solar.

## 5.3 Evidência de Visualização de Dados

A validação da visualização e consistência dos dados foi realizada por meio da análise dos dashboards gerados a partir do backend.

No dashboard representado na Figura 21 a seguir, correspondente à estação instalada em ambiente interno (sem painel solar), é possível observar:

- Oscilações de temperatura e umidade associadas ao acionamento e desligamento do sistema de ar-condicionado;
- Variações abruptas de luminosidade nos momentos de acionamento da iluminação interna;
- Processo gradual de descarga da bateria, evidenciando o consumo energético sem reposição solar.


Fig. 21: Dashboard da estação interna

Em outro dashboard, apresentado na Figura 22 a seguir, com dados referentes ao dia 10/02/2026 (fuso horário de Brasília) da estação instalada em ambiente externo, observam-se:

- Queda expressiva na pressão atmosférica entre 13h e 18h;
- Redução significativa da temperatura entre 16h e 18h30.

Registros meteorológicos da região indicaram ocorrência de tempestades por volta das 18h, corroborando os dados coletados pela estação e demonstrando a coerência das medições realizadas.


Fig. 22: Dashboard da estação externa em dia com tempestade

# 6. Análise do Nível de Maturidade Tecnológica (TRL)

O projeto da Estação Meteorológica IoT teve início em TRL 4 – Validação de componentes em ambiente de laboratório, utilizando originalmente comunicação via WiFi. Nessa fase, os subsistemas principais: sensoriamento, processamento, alimentação e transmissão de dados encontravam-se integrados e funcionalmente validados em bancada.

Entretanto, atendendo ao requisito de uso de LoRaWAN implementou-se uma reformulação arquitetural, substituindo o WiFi por essa tecnologia, mais adequada ao objetivo de baixo consumo e comunicação de longa distância. Alem disso, havia a demanda pelo uso do WCM do projeto do grupo da Unicamp.

Evolução para TRL 5 – Validação em ambiente relevante

Após a reengenharia, foram realizados ajustes de hardware e software para adaptação ao novo modelo de comunicação, incluindo otimização do consumo energético e integração com gateway e backend LoRaWAN.

Com a validação do sistema em condições externas controladas, operando com energia solar e transmissão estável de dados, o projeto evoluiu para TRL 5 – Tecnologia validada em ambiente relevante.

Evolução para TRL 6/7 – Demonstração em ambiente operacional

Na etapa seguinte, a estação foi implantada em campo, operando de forma autônoma com alimentação por bateria, painel solar e transmissão LoRaWAN. O backend passou a operar de forma contínua, permitindo armazenamento e visualização dos dados coletados.

Essa fase caracteriza a transição para TRL 6/7, pois o protótipo foi demonstrado em ambiente operacional real, com desempenho consistente em monitoramento, autonomia energética e comunicação de longa distância.

A consolidação formal do TRL 7 – Demonstração de protótipo em ambiente operacional dependerá de operação contínua prolongada, coleta sistemática de dados e avaliação de confiabilidade em longo prazo.

# 7. Resultados Consolidados

Os resultados obtidos ao longo do desenvolvimento evidenciam a maturidade técnica e a robustez da solução proposta, destacando-se:

- Arquitetura modular e escalável: estrutura de hardware e software organizada em módulos independentes, permitindo manutenção simplificada, expansão funcional e adaptação a novas demandas tecnológicas.
- Payload LoRaWAN otimizado: estrutura de dados compacta e eficiente, reduzindo o tempo de transmissão, o consumo energético e a ocupação do canal, mantendo a integridade das informações enviadas.
- Redução expressiva do consumo energético: implementação de estratégias de gerenciamento de energia em hardware e firmware, associadas ao sistema de carregamento por painel solar, garantindo maior autonomia operacional.
- Integração efetiva com infraestrutura de rede e backend: comunicação validada com gateway LoRaWAN, plataforma TTN (The Things Network) e visualização de dados via TheThingsBoard, assegurando persistência, histórico e monitoramento em tempo real.
- Desenvolvimento de hardware dedicado: projeto e fabricação de PCI específica para a aplicação, eliminando periféricos desnecessários e otimizando o consumo energético e a confiabilidade do sistema.
- Sistema preparado para replicação em escala: solução estruturada para permitir produção de múltiplas unidades, com documentação técnica, organização de firmware e padronização de hardware.

# 8. Custo da estação

Na Tabela 1, pode-se observar o custo estimado de cada módulo e total da estação.

Módulo | Custo estimado
Placa Principal | R$ 114,69
WCM | R$ 164,16
Sensores | R$ 83,97
Itens de Instalação | R$ 328,85
TOTAL | R$ 691,67

Tab.1: Custos estimados por módulo e total.

Obs.: Detalhes em: Apêndice 2 - Planilha de Custos

A título de comparação, uma estação comercial com LoRa, colocada no mercado nacional, pode ser obtida ao preço de R$ 1.390,44, como informa https://www.mercadolivre.com.br/estaco-meteorologica-lora-7-em-1-com-sistema-de/p/MLB2030746108.

# 9. Conclusão

A Estação Meteorológica IoT desenvolvida demonstra viabilidade técnica, maturidade arquitetural e potencial de escalabilidade. A solução implementada apresenta estabilidade operacional, eficiência energética e capacidade de integração com redes de comunicação de longa distância baseadas em LoRaWAN, atendendo aos requisitos propostos para monitoramento ambiental remoto.

O sistema realizou a medição e o monitoramento de múltiplos parâmetros, abrangendo:

- Parâmetros meteorológicos: temperatura, umidade relativa do ar, pressão atmosférica e luminosidade;
- Parâmetros de localização: latitude, longitude e altitude por meio de módulo GPS;
- Parâmetros internos da estação: temperatura da MPU (microcontrolador) e tensão da bateria para supervisão energética.

Os testes de autonomia demonstraram o perfil de baixo consumo do sistema. Operando exclusivamente com alimentação por bateria, a estação apresentou autonomia mínima de 1 dia com o GPS ativo continuamente e colhendo dados a cada 1 segundo. Com o GPS desativado e colhendo dados a cada 1minuto, condição que reduz significativamente o consumo energético, já foram obtidos 5 dias de operação, com testes de longa duração ainda em andamento.

No que se refere à comunicação, foi alcançada distância de 1.108 metros entre a estação (-22.814412, -47.058611) e o gateway (-22.822022, -47.065587), mantendo transmissão estável e a integridade dos dados, validando o uso de LoRaWAN como tecnologia adequada para aplicações de monitoramento distribuído.

O sistema encontra-se apto para expansão de múltiplas unidades, operação contínua em campo e integração com plataformas de processamento e visualização de dados. A arquitetura modular adotada favorece manutenibilidade, atualização incremental e incorporação de novos recursos, garantindo flexibilidade para evolução tecnológica.

# 10. Evolução Futura (Trabalhos Futuros)

A evolução futura da estação meteorológica pode ser direcionada para aprimoramentos em três eixos principais: eficiência energética, otimização de software e ampliação funcional do sistema.

Entre os possíveis trabalhos futuros, destacam-se:

- Aprimoramento do hardware, com foco no maior aproveitamento da energia solar, incluindo otimização do sistema de carga, melhorias no gerenciamento energético e possível adoção de componentes ainda mais eficientes.
- Otimizações no software embarcado, visando reduzir ainda mais o consumo energético por meio de técnicas avançadas de gerenciamento de energia, modos de baixo consumo e ajustes nos ciclos de transmissão.
- Ampliação dos modos de comunicação LoRa, incluindo implementação de comunicação ponto-a-ponto (P2P) e suporte ao protocolo LoRaWAN com ativação via OTAA (Over-The-Air Activation), aumentando a flexibilidade e a segurança da rede.
- Expansão do conjunto de sensores, com a adição de sensor de radiação UV, sensor de direção e velocidade do vento (anemômetro) e sensor pluviométrico, permitindo medições meteorológicas mais completas.
- Migração do ambiente de rede, substituindo o TTN por ChirpStack, possibilitando maior controle da infraestrutura, independência de serviços externos e personalização avançada da rede LoRaWAN.

Com esses aprimoramentos, a estação meteorológica poderá alcançar maior autonomia energética, robustez operacional e capacidade analítica, consolidando-se como uma plataforma escalável e preparada para aplicações em larga escala e cenários de monitoramento ambiental mais complexos.

# Referências

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

# Figuras

Fig. 1: Estação operando em campo.

Fig. 2: Digrama da arquitetura geral do sistema.

Fig. 3: BME280

Fig. 4: BH1750

Fig. 5: GY-NEO6MV2

Fig. 6: Módulo WCM com seu respectivo cabo de conexão de antena.

Fig.7: Painel Solar RSM10P

Fig.8: Regulador de tensão

Fig. 9: Carregador e módulo de proteção da bateria

Fig. 10: BitDogLab Versão 7

Fig. 11: PCI – Cobre

Fig. 12: PCI Montada

Fig.13: Menu de configuração

Fig. 14: Componentes da estrutura mecânica

Fig. 15: Log da estação

Fig. 16: Log do simulador de gateway

Fig. 17: Mostra o Log no TTN dos dados recebidos pelo gateway

Fig. 18: Mostra o Log no TTN dos dados enviados pelo end device

Fig. 19: Consumo dinâmico da estação

Fig. 20: Dashboard da estação externa

Fig. 21: Dashboard da estação interna

Fig. 22: Dashboard da estação externa em dia com tempestade

# Tabelas

Tab.1: Custos estimados por módulo e total.

# Apêndices

## Apêndice 0 – Diretório principal do projeto

Os apêndices abaixo encontram-se dentro da pasta:

https://github.com/EmbarcaTech-2025/projeto-final-antonio_carlos_ricardo/tree/main/DocumentacaoFinalDoProjeto

Obs.: Abaixo estão apenas o caminho e o nome do arquivo

## Apêndice 1 - Manual do Usuário

Doc/Manual_Usuário/Manual_Usuario.md

## Apêndice 2 - Planilha de Custos

Doc/BillOfMaterial_With_Cost.ods

Doc/BillOfMaterial_With_Cost.pdf

## Apêndice 3 - Mapeamento do sinal LoRaWAN

Doc/Dados_TX_LoRa.pdf

## Apêndices 4 - Código Fonte

### Apêndice 4.1 - Código-fonte do Rapberry Pico RP2040

Software/Main_Board

### Apêndice 4.2 - Código-fonte do ESP32-C3

Software/WCM

#### Apêndice 4.3 – Código fonte do - Decodificador de Paylod para o TTN

Software/TTN_Payload_Decode

## Apêndice 5 - Esquemáticos e PCI da Placa Principal (Pico - RP2040)

Hardware/MainBoard

# Anexos

Os anexos abaixo encontram-se dentro da pasta:

https://github.com/EmbarcaTech-2025/projeto-final-antonio_carlos_ricardo/tree/main/DocumentacaoFinalDoProjeto

Obs.: Abaixo estão apenas o caminho e o nome do arquivo

### Anexo 1 - Esquemáticos e PCI da Placa WCM (ESP32-C3)

Hardware/WCM

### Anexo 2 – Peças 3D

Hardware/Pecas3D

Instituto Hardware BR – Embarcatech - 32

Instituto Hardware BR – Embarcatech - 31

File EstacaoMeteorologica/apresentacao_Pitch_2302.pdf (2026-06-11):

# Estação Meteorológica IoT

Monitoramento ambiental distribuído ainda não é amplamente difundido
- Áreas agrícolas
- Campi universitários (pesquisa)
- Cidades inteligentes
- Custo de estações comerciais ~ R$ 1.390+

# Estação Meteorológica IoT

Estação Meteorológica IoT de Baixo Custo, Baixo Consumo e Longo Alcance
- Comunicação LoRaWAN
- Energia Solar
- Estação:
- Autônoma
- Modular
- Escalável

# Estação Meteorológica IoT

Solução Implementada
- Estação
- Gateway
- The Things Network (TTN)
- The Things Board

# Estação Meteorológica IoT

Diferenciais Competitivos
- Hardware dedicado (baixo consumo real)
- Payload otimizado (menor ToA) e menor consumo
- Escalável para múltiplas estações
- IP68
- Projeto open source
- Custo de montagem acessível

# Estação Meteorológica IoT


Resultado em Campo

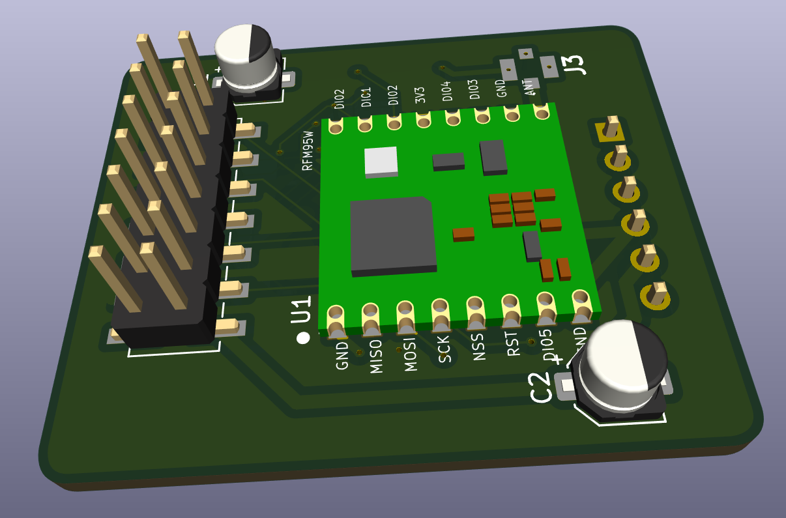
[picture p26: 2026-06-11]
EstacaoMeteorologica/DocumentacaoFinalDoProjeto/Hardware/WCM/assets/3d_F.cu.png

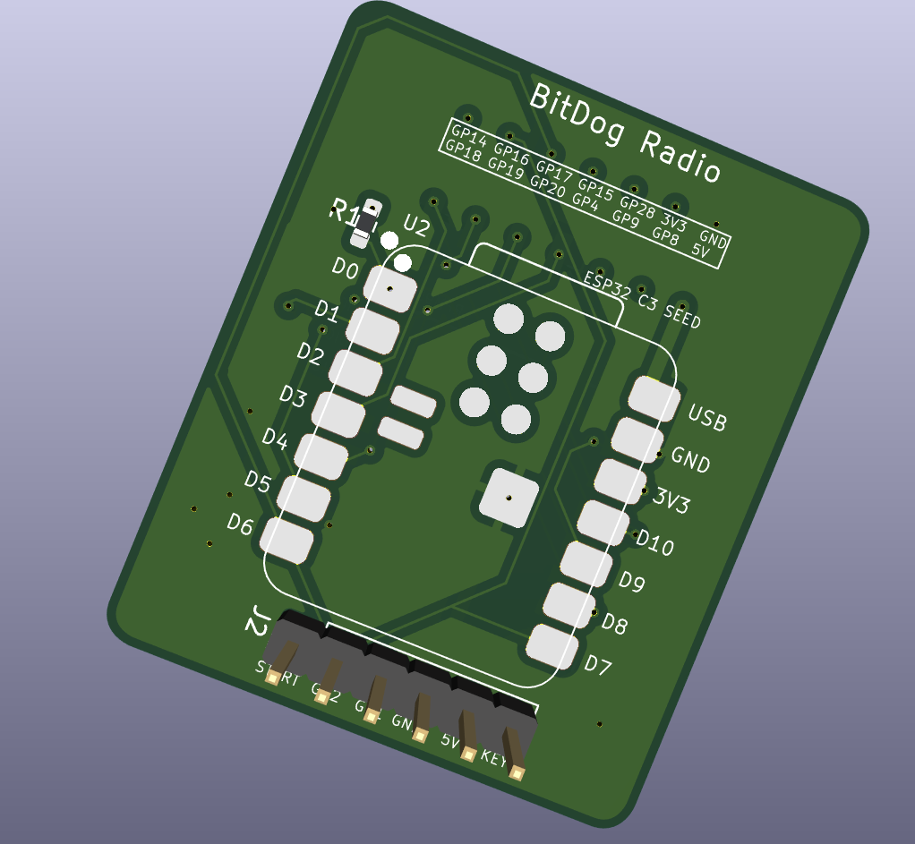
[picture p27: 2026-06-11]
EstacaoMeteorologica/DocumentacaoFinalDoProjeto/Hardware/WCM/assets/B.cu.png

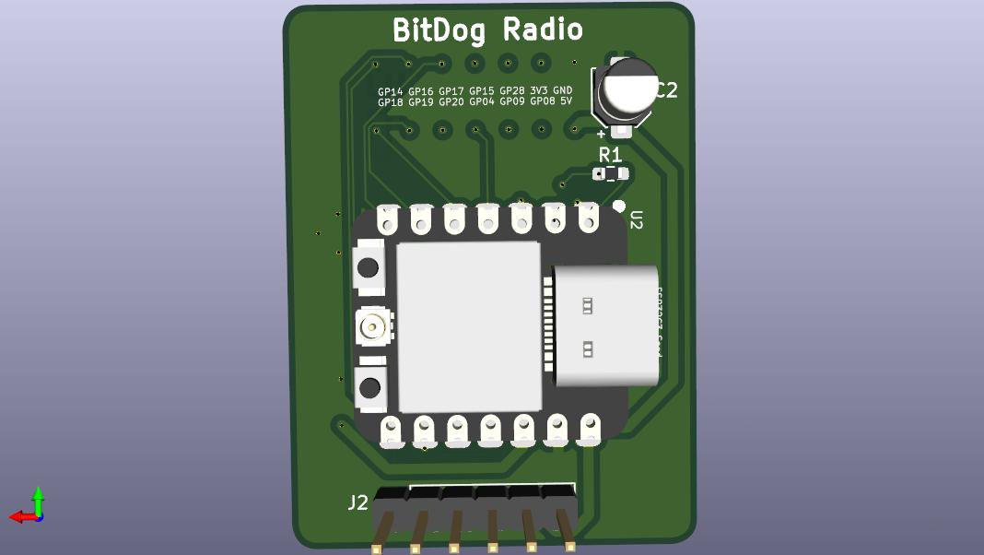
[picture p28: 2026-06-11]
EstacaoMeteorologica/DocumentacaoFinalDoProjeto/Hardware/WCM/assets/WCM_v1D_2.jpg

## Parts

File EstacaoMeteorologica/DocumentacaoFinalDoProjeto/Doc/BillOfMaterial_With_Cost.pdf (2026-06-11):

# Estação Meteorológica IoT: “Bill of Material” (com custos estimados)

## Placa Principal

Item | Quant. | Preço Unitário | Preço Total | Referência
PCB | 1 | R$ 30,00 | R$ 30,00 Estimado
Suporte bateria | 1 | R$ 3,99 | R$ 3,99 | https://www.casadarobotica.com/componentes-eletronicos/partes/suporte-para-pilhas/case-suporte-soquete-para-1-bateria-18650
Bateria | 1 | R$ 14,99 | R$ 14,99 | https://www.casadarobotica.com/fontes-conversores/fontes/outros/1x-bateria-3-7v-18650-de-litio-recarregavel-goldhill
Conector Borne KRE 2 Vias | 1 | R$ 0,60 | R$ 0,60 | https://www.piscaled.com.br/conector-borne-kre-2-vias
Diodos 1N5819 | 2 | R$ 0,22 | R$ 0,44 https://www.eletrogate.com/diodo-1n5819-10-unidades
Chaves H-H | 3 | R$ 1,20 | R$ 3,60 https://www.casadoresistor.com.br/chave-hh-liga-desliga-250v-03-terminais-180
Módulo Regulador de Tensão Step Down LM2596 | 1 | R$ 7,90 | R$ 7,90 | https://www.eletrogate.com/modulo-regulador-de-tensao-step-down-lm2596
Módulo Carregador Bateria de Lítio TP4056 Micro USB | 1 | R$ 3,70 | R$ 3,70 | https://www.makerhero.com/produto/modulo-carregador-de-bateria-de-litio-tp4056/
Capacitores 100uF x 16V | 3 | R$ 0,28 | R$ 0,84 https://www.casadoresistor.com.br/capacitor-eletrolitico-100uf-x-16v
Capacitor 100nF ceramico | 1 | R$ 0,15 | R$ 0,15 https://www.a2robotics.com.br/capacitor-disco-ceramico-100nf-x-50v-104
Raspberry Pico | 1 | R$ 37,90 | R$ 37,90 https://www.makerhero.com/produto/raspberry-pi-pico/
Barra de 40 Pinos | 2 | R$ 1,80 | R$ 3,60 https://www.makerhero.com/produto/barra-de-pinos-1x40-180-graus/
Conector de 20Pinos | 3 | R$ 1,20 | R$ 3,60 | https://www.casadarobotica.com/componentes-eletronicos/partes-eletronicas/conectores/barra-de-pinos-pin-head-femea-pci-1x20-passo-2-54mm-180
Resistores 1 k x 1/4W 5% | 3 | R$ 0,08 | R$ 0,24 https://www.casadoresistor.com.br/resistor-filme-carbono-carvao-cr25-1-4w-5-1k
Resistores 100k x 1/4W 1% | 2 | R$ 0,15 | R$ 0,30 https://www.casadoresistor.com.br/resistor-filme-metalico-metal-film-mf25-1-4w-1-100k
Led Vermelho 3mm | 1 | R$ 0,18 | R$ 0,18 https://www.casadoresistor.com.br/led-3mm-200mcd-30-vermelho-encapsulamento
Led Verde | 1 | R$ 0,18 | R$ 0,18 https://www.casadoresistor.com.br/led-3mm-verde-0301doyg
Led Azul | 1 | R$ 0,32 | R$ 0,32 https://www.casadoresistor.com.br/led-3mm-250-mcd-difuso-azul
Conectores JSH | 4 | R$ 0,40 | R$ 1,60 https://www.smartkits.com.br/conector-jst-xh2-54mm-macho-4-vias
Chaves tactil | 2 | R$ 0,28 | R$ 0,56 | https://www.casadoresistor.com.br/chave-tactil-kfc-a06-6x6x5-4t-180
Total | | | R$ 114,69

## WCM

Item | Quant. | Preço Unitário | Preço Total | Referência
PCB | 1 | R$ 30,00 | R$ 30,00 Estimado
XIAO-ESP32-C3 | 1 | R$ 70,00 | R$ 70,00 Estimado, referências abaixo
RFM95-W | 1 | R$ 61,10 | R$ 61,10 https://www.piscaled.com.br/modulo-lora-rfm95w-915mhz
Capacitores SMD 100uF | 2 | R$ 0,59 | R$ 1,18 https://www.casadoresistor.com.br/capacitor-eletrolitico-smd-100uf-16v-diametro-7mm-altura-5mm
Resistor SMD | 1 | R$ 0,08 | R$ 0,08 https://www.casadoresistor.com.br/resistor-smd-0603-1-4k75
Barra de 6 pinos | 1 | R$ 1,80 | R$ 1,80 https://www.makerhero.com/produto/barra-de-pinos-1x40-180-graus/
Total | | | R$ 164,16
Preço Estimado do XIAO-ESP32-C3 | Referência
US$ 4,90 R$ 69,90 https://www.robocore.net/seeed-studio/seeed-studio-xiao-esp32c6 | https://www.seeedstudio.com/Seeed-XIAO-ESP32C3-p-5431.html

## Sensores

Item | Quant. | Preço Unitário | Preço Total | Referência
bme280 | 1 | R$ 32,87 | R$ 32,87 | https://www.usinainfo.com.br/sensor-de-pressao/sensor-de-pressao-umidade-e-temperatura-bme280-de-alta-precisao-33v-4682.html
bh1750 | 1 | R$ 12,00 | R$ 12,00 https://www.piscaled.com.br/modulo-sensor-de-luminosidade-bh1750-gy-302-lux
Módulo GPS GY-NEO6MV2 Com Antena | 1 | R$ 37,90 | R$ 37,90 | https://www.makerhero.com/produto/modulo-gps-gy-neo6mv2-com-antena/
Conectores JSH | 3 | R$ 0,40 | R$ 1,20 https://www.smartkits.com.br/conector-jst-xh2-54mm-macho-4-vias
Total | | | R$ 83,97

## Instalação

Item | Quant. | Preço Unitário | Preço Total | Referência
Painel Solar | 1 | R$ 78,99 | R$ 78,99 | https://www.mercadolivre.com.br/painel-placa-solar-fotovoltaica-10w-inmetro/up/MLBU727939907
Caixa | 1 | R$ 78,90 | R$ 78,90 | https://www.mercadolivre.com.br/up/MLBU780593118
Cabos JSH | 3 | R$ 3,00 | R$ 9,00
Suporte Caixa Painel solar | 0,22 | R$ 63,50 | R$ 13,97 | https://www.filamentos3dbrasil.com.br/produtos/filamento-abs-premium-natural/
Parafusos Suporte | 2 | R$ 2,00 | R$ 4,00 Estimado
Solda | 1 | R$ 15,99 | R$ 15,99 | https://www.casadarobotica.com/prototipagem-ferramentas/prototipagem/soldas/solda-tubinho-fio-ra-63x37-sn-x-pb-1-0mm-22g-cobix
Parafusos PCB | 4 | R$ 0,75 | R$ 3,00 https://www.casadoresistor.com.br/espacador-nylon-femea-macho-m3x12mm-branco
Antena | 1 | R$ 125,00 | R$ 125,00 | https://www.mercadolivre.com.br/antena-para-rf-lora-868mhz--915mhz-1m-6dbi--cabo-ipex/up/MLBU1972521930
Total | | | R$ 328,85

## Custo Total

Item | Quant. | Preço Unitário | Preço Total | Referência
Placa Principal | 1 | R$ 114,69 | R$ 114,69
WCM | 1 | R$ 164,16 | R$ 164,16
Sensores | 1 | R$ 83,97 | R$ 83,97
Itens de Instalação | 1 | R$ 328,85 | R$ 328,85
Total | | | R$ 691,67

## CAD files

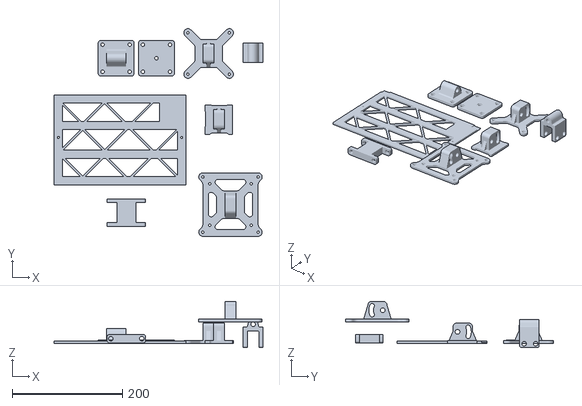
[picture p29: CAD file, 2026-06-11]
EstacaoMeteorologica/DocumentacaoFinalDoProjeto/Hardware/Pecas3D/haste fixação painel solar.stl
378.4 x 376.0 x 83.6

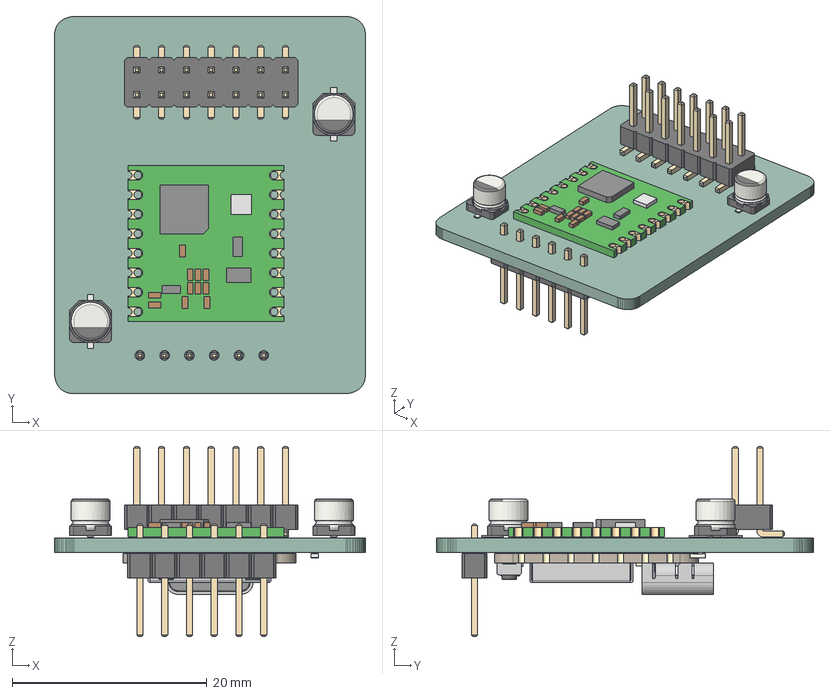
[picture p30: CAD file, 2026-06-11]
EstacaoMeteorologica/DocumentacaoFinalDoProjeto/Hardware/WCM/KiCad/WCM_v1D.step
31.9 x 38.7 x 19.5 mm
CP_Elec_4x3.9 x 2
PinHeader_2x07_P2.54mm_Vertical_SMD
RFM95W-868S2--3DModel-STEP-56544
BOSS-EXTRUDE14_8_
BOSS-EXTRUDE7_4_
BOSS-EXTRUDE7_3_
BOSS-EXTRUDE14_4_
BOSS-EXTRUDE14_2_
BOSS-EXTRUDE14_11_
BOSS-EXTRUDE7_7_
BOSS-EXTRUDE14_9_
BOSS-EXTRUDE14_3_
BOSS-EXTRUDE14_7_
MIRROR2
BOSS-EXTRUDE14_5_
BOSS-EXTRUDE14_12_
BOSS-EXTRUDE7_8_
BOSS-EXTRUDE7_1_
BOSS-EXTRUDE14_10_
BOSS-EXTRUDE7_9_
BOSS-EXTRUDE14_6_
BOSS-EXTRUDE14_1_
BOSS-EXTRUDE7_6_
BOSS-EXTRUDE7_2_
CUT-EXTRUDE5
BOSS-EXTRUDE7_5_
U.FL Connector v1
Button (1) x 2
Shield
PinHeader_1x06_P2.54mm_Vertical
R_0603_1608Metric
WCM_v1D_PCB

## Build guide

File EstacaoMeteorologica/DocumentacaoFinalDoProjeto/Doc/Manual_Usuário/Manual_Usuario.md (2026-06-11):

# 📖 Manual do Usuário – Estação Meteorológica IoT com LoRaWAN

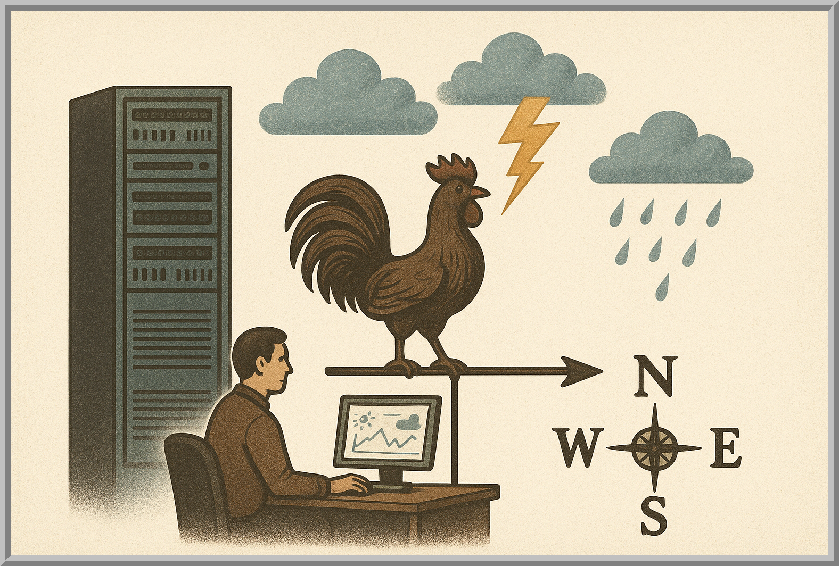
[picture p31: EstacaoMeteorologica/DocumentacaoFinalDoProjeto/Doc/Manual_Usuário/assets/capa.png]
Capa


Autores: **Antonio**, **Carlos** e **Ricardo**

Versão: 0.00.04 de 15/02/2026

## Índice

- [📖 Manual do Usuário – Estação Meteorológica IoT com LoRaWAN](#-manual-do-usuário--estação-meteorológica-iot-com-lorawan)
  - [Índice](#índice)
  - [1. Apresentação do Sistema](#1-apresentação-do-sistema)
  - [2. Materiais Necessários](#2-materiais-necessários)
  - [3. Visão Geral do Funcionamento](#3-visão-geral-do-funcionamento)
  - [4. Instalação Física da Estação](#4-instalação-física-da-estação)
  - [5. Configuração da Estação](#5-configuração-da-estação)
    - [5.1 Parâmetros LoRaWAN](#51-parâmetros-lorawan)
    - [5.2 Definição dos Intervalos de Coleta](#52-definição-dos-intervalos-de-coleta)
    - [5.3 Seleção dos Sensores Ativos](#53-seleção-dos-sensores-ativos)
    - [5.4 Seleção dos Modos de Log](#54-seleção-dos-modos-de-log-afetam-o-consumo-da-estação)
    - [5.5 Opções Adicionais do Menu](#55-opções-adicionais-do-menu)
  - [6. Funcionamento da Estação](#6-funcionamento-da-estação)
    - [6.1 Indicações dos LEDs da Placa](#61-indicações-dos-leds-da-placa)
    - [6.2 Indicações do Monitor Serial](#62-indicações-do-monitor-serial)
  - [7. Configuração do Gateway e do The Things Network](#7-configuração-do-gateway-e-do-the-things-network)
  - [8. Configuração do TheThingsBoard](#8-configuração-do-thethingsboard)
  - [9. Especificações Técnicas da Estação](#9-especificações-técnicas-da-estação)
    - [Principais características](#principais-características)
    - [Características dos sensores homologados](#características-dos-sensores-homologados)
---

## 1. Apresentação do Sistema

A Estação Meteorológica IoT é um sistema para monitoramento ambiental distribuído, projetado para operar de forma autônoma e com baixo consumo energético. A solução utiliza comunicação **LoRaWAN**, permitindo a coleta e visualização remota de dados meteorológicos por meio de plataformas web.

O sistema foi desenvolvido, primeiramente, para aplicações no Agronegócio e na Agricultura Familiar, tendo sido estendido posteriormente para aplicações acadêmicas, experimentais e de pesquisa. Como parte do projeto, o campus universitário da Unicamp possibilitará a instalação de múltiplas estações distribuídas geograficamente.

---

## 2. Materiais Necessários

- Uma caixa para a instalação da estação;
- Uma placa da Estação Meteorológica;
- Um módulo WCM;
- Sensores:
  - BH1750, sensor de luminosidade;
  - BME280, sensor de pressão, temperatura e umidade;
  - GPS, sensor de posição;
- Três Cabos JST XH de 4 pinos;
- Um Painel Solar;
- Suporte para caixa e painel solar;
- Manual de instruções.

---

## 3. Visão Geral do Funcionamento

A estação opera de forma totalmente automática após a instalação. O ciclo de funcionamento é composto por:

1. Coleta periódica dos dados ambientais.  
2. Processamento local das medições.  
3. Empacotamento dos dados.  
4. Transmissão via LoRaWAN.  
5. Recepção pelo GTateway.  
6. Armazenamento e visualização.  

Não é necessária intervenção do usuário durante a operação normal.

---

## 4. Instalação Física da Estação

Para garantir o funcionamento adequado da estação, siga as orientações abaixo:

1. Instale a estação em local aberto e bem ventilado.  
2. Evite proximidade com superfícies metálicas ou obstáculos.  
3. Posicione o painel solar voltado para o norte geográfico com uma inclinação condizente à latitude do local de instalação.  
4. Instale os módulos segundo os seguintes passos:  
   - Conecte os módulos I2C (BH1750 e BME280) na placa da estação com os cabos JST XH de 4 pinos;
   - Conecte o GPS na placa da estação com o cabo JST XH de 4 pinos;
   - Conecte o painel solar a placa da estação atravês do conector KRE;
   - Conecte o módulo WCM à placa principal;
   - Conecte a antena ao módulo WCM;
   - Insira a vateria ao suporte de bateria (atente-se à polaridade da bateria);
   - Obs.: Para a configuração inicial será necessário conectar a placa da estação via cabo USB a um terminal serial, utilizando o conector USB da placa Raspberry Pi Pico.  

---

## 5. Configuração da Estação

Obs.: Obrigatória na primeira energização.

- A estação meteorológica inicia automaticamente seu funcionamento assim que é energizada.  
- Para energizar a estação ligue as chaves na sequinte sequência:  
	+ SW2
	+ SW3
	+ SW1
- Caso queira ajustar os parâmetros da estação use o terminal serial USB. Para isso, energize a estação ou pressione o botão Reset. Quando o LED vermelho começar a piscar pressione o botão Config na placa da estação.  
- A configuração é realizada através de **menu textual** exibido no monitor serial.  
  - O menu permite ajustar parâmetros gerais, de comunicação, os intervalos de coleta de dados e ativar ou desativar os sensores, conforme será descrito a seguir.
- Para configurar os parâmetros da estação, pressione a letra/número correspondente ao item desejado. Alguns parâmentros têm seu valor atualizado automaticamente e outros necessitam que se digite o valor desejado seguido de Enter.

### Tela de Configuração Geral da Estação

As imagens abaixo mostram telas do menu:
  
- Quando configurando parâmetros ABP:
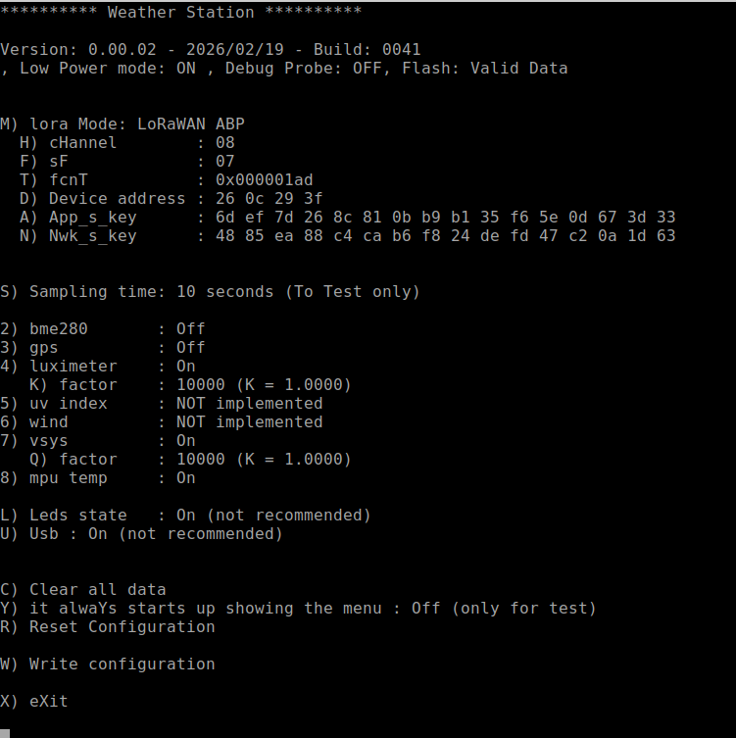
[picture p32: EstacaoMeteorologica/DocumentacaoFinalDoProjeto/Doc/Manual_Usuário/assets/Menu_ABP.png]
Menu de Configuração ABP
  
  
- Quando configurando parâmetros OTAA:
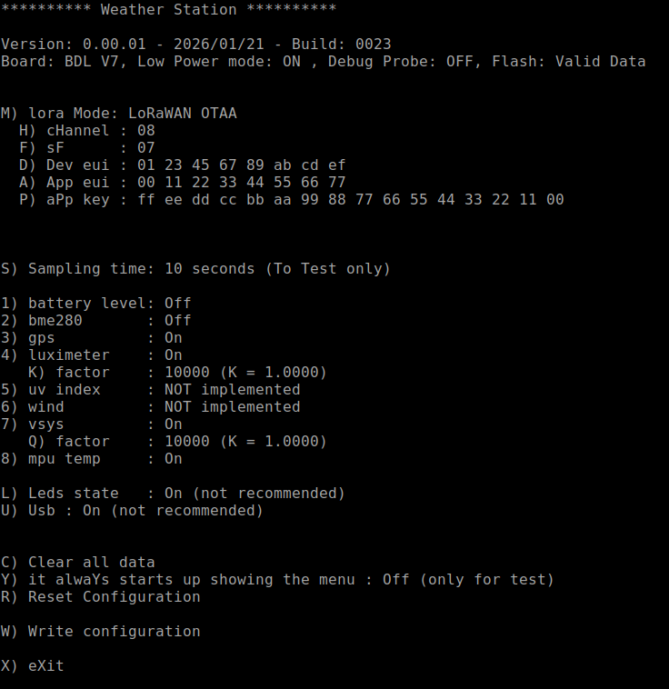
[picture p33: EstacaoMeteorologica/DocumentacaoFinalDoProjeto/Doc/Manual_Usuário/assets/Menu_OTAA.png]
Menu de Configuração OTAA
  

---

### 5.1 Parâmetros LoRaWAN

- Para selecionar entre os modos ABP ou OTAA utilize a tecla M;  
- Cada modo tem seus próprios parâmetros configuráveis, sendo:  
    + Modo ABP:  
        - Canal  
        - Sf  
        - fcnt  
        - Device Address  
        - App_s_Key  
        - Nwk_s_Key  
    + Modo OTAA:  
        - Canal  
        - Sf  
        - Dev EUI  
        - App EUI  
        - App Key  
	- Obs.: Em operação normal os parâmetros Canal e Sf devem estar em AUTO.  

---

### 5.2 Definição dos Intervalos de Coleta

Pressione a tecla S para escolher os intervalos de coleta entre 10 segundos (apenas para teste) e 1, 2, 5, 10, 15, 20, 30, 45 ou 60 minutos.  

---

### 5.3 Seleção dos Sensores Ativos

- **2) bme280** – Para medir a umidade relativa, a temperatura e a pressão atmosférica.  
- **3) gps** – Para medir a latitude, a longitude e a altitude.  
- **4) luxímetro** – Para medir a luminosidade do ambiente.
    - **K) factor** – Fator de correção do luxímetro.
- **5) uv index** – Ainda não implementado.  
- **6) wind** – Ainda não implementado.  
- **7) vsys** – Para medir a tensão de alimentação da placa.  
    - **Q) factor** – Fator de correção do Vsys.
- **8) mpu temp** – Para medir a temperatura interna do microcontrolador.  

---

### 5.4 Seleção dos Modos de Log (afetam o consumo da estação)

- **L) Leds state** – Se ativado (aumenta o consumo da estação), os LEDs coloridos exibem o estado da estação, ou seja:
  - Sleeping - Estação em modo de baixo consumo. Todos os LEDs apagados.  
  - Coleta - Estação em modo de aquisição de dados dos sensores. LED azul aceso.  
  - Transmissão - Estação em modo de envio de dados ao gateway. Todos os LEDs acesos.    

- **U) Usb** – Para escolher entre os modos do USB:  
  - OFF - Desativa a porta USB (menor consumo energético);  
  - ON - Mantêm a porta USB sempre ativa (maior consumo energético);  
  - ON-OFF AUTO - Ativa a USB apenas se a estação está em modo de aquisição ou transmissão de dados (consumo intermediário).  

---

### 5.5 Opções Adicionais do Menu

- **C) Clear all data** – Apaga todos os registros locais, **é necessário ser executado na primeira inicialização da estação**.  
- **Y) it alwaYs starts up showing the menu** – Ativa ou desativa o menu de configuração ao ligar a estação.  
- **R) Reset configuration** – Restaura os parâmetros de fábrica.  
- **W) Write configuratiom** – Salva as alterações das configurações.
- **X) eXit** – Encerra o menu de configuração e ativa a operação da estação.  

---

## 6. Funcionamento da Estação

Após a energização do sistema os LEDs R, G e B piscam rapidamente na sequência vermelho, verde e azul.

Se o botão Config for pressionado durante o periodo em que o LED vermelho estiver piscando, inverte-se a definição atual do item "it always starts up showing the menu".  

### 6.1 Indicações dos LEDs da Placa

Durante a operação, os LEDs acessos indicam:
- Verde ==> Inicializando o sistema (dumora 10 segundo);
- Verde aceso e Vermelho piscando ==> Botão Config habilitado;
- Vermelho ==> Modo de configuração ativo. O menu pode ser acessado pela USB;
- Vermelho piscando ==> Falha na inicialização dos sensores. A estação aguarda correção;
- Azul ==> A estação faz a aquisição dos dados dos sensores;
- Azul, Verde e Vermelho ==> A estação transmite os dados;
- Nenhum LED acesso ==> Periodo entre aquisições. A estação está em baixo consumo.

---

### 6.2 Indicações do Monitor Serial

Durante a operação da estação, se o log USB estiver ativo, o monitor serial mostrará os dados enviados para o gateway, conforme a figura a seguir.  

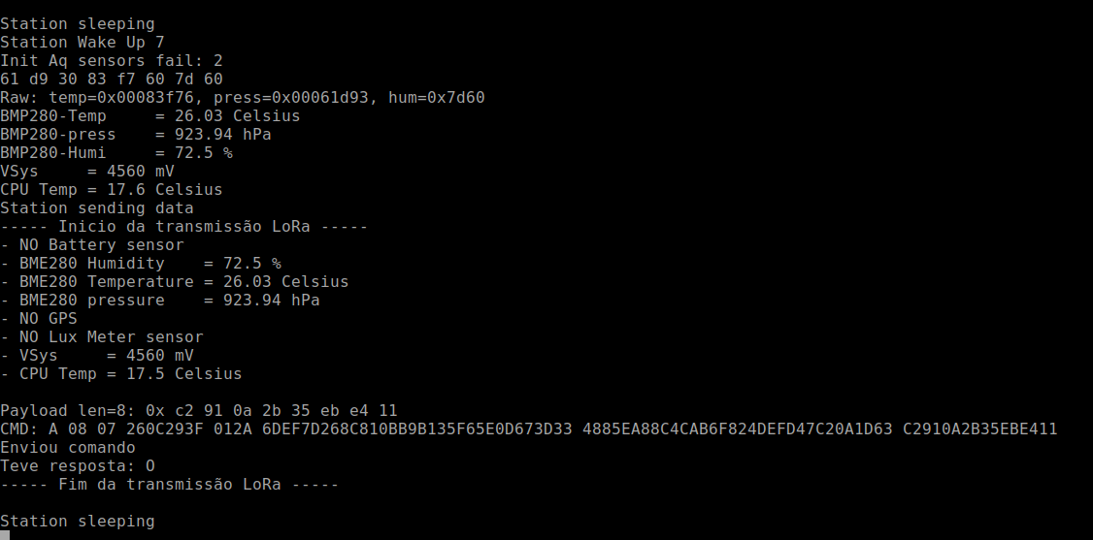
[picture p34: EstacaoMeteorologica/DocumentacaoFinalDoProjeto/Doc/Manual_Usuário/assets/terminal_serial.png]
Terminal serial


---

## 7. Configuração do Gateway e do The Things Network

Veja: [Link](https://docs.google.com/document/d/1o25VC49TM4YPC_RLyG_XDTTJo1DXNHsViMWomo7teZQ/edit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)

---

## 8. Configuração do TheThingsBoard

Veja: [Link](https://docs.google.com/document/d/1o25VC49TM4YPC_RLyG_XDTTJo1DXNHsViMWomo7teZQ/edit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)

---

## 9. Especificações Técnicas da Estação

### Principais características
  
- Placa principal dedicada com a Raspberry Pi Pico.  
- Software Build: 0021 ou superior.
- Consumo médio:  
	+ Sleep mode: 6 mA
	+ Estação transmitindo os dados coletados: 97 mA  

  Obs.: Sem GPS conectado.  

- Duração estimada da bateria sem alimentação solar (noite, nublado):
  - sem GPS ligado: em avaliação  
  - com GPS ligado: em avaliação  
	+ Considerando:
        - Bateria 18650 de 2000 mA hora;
        - Comunicação a cada 5 minutos. 

### Características dos sensores homologados

| Sensor | Grandeza | Unidade | Range | Precisão | Faixa de Operação |Consumo | Outros |
| --- | --- | --- | --- | --- | --- | --- | --- |
| BME280 | Pressão | hPa| 300 a 1100 hPa|+/- 1 hPa (de 0 a +40 ºC) | -40 a +85 ºC | 1120 uA peak | I2C address = 0x60 |
| BME280 | Temperatura | ºC | 0 a 65 ºC| +/-1.0 ºC | |
| BME280 | Umidade relativa | % | 0 a 100 %|  | |
| BH1750 | Luminosidade | lx | 0 a 65535 * | | -40 a +85 ºC | 190 uA | I2C address = 0x23 0x5C |

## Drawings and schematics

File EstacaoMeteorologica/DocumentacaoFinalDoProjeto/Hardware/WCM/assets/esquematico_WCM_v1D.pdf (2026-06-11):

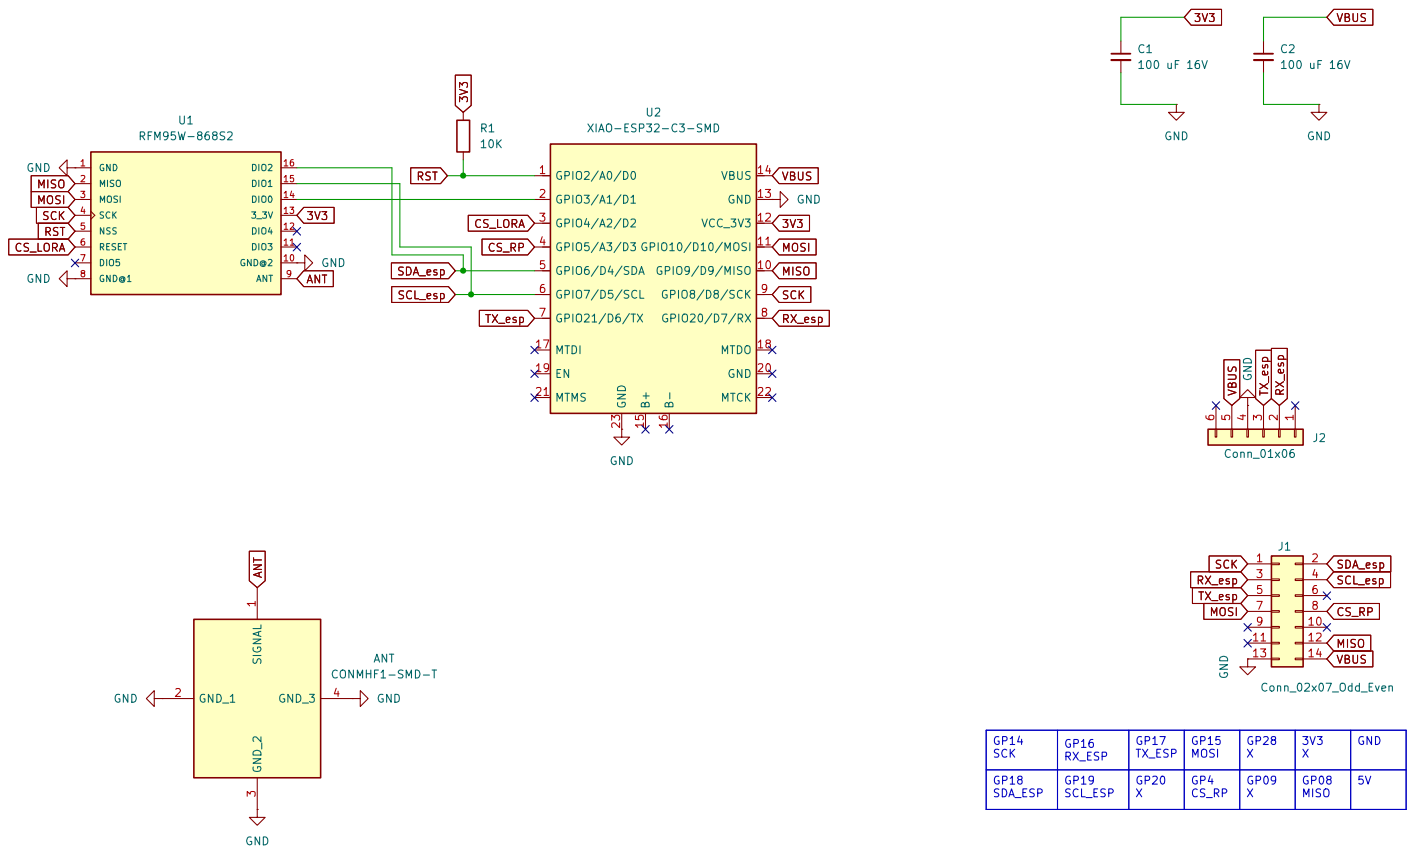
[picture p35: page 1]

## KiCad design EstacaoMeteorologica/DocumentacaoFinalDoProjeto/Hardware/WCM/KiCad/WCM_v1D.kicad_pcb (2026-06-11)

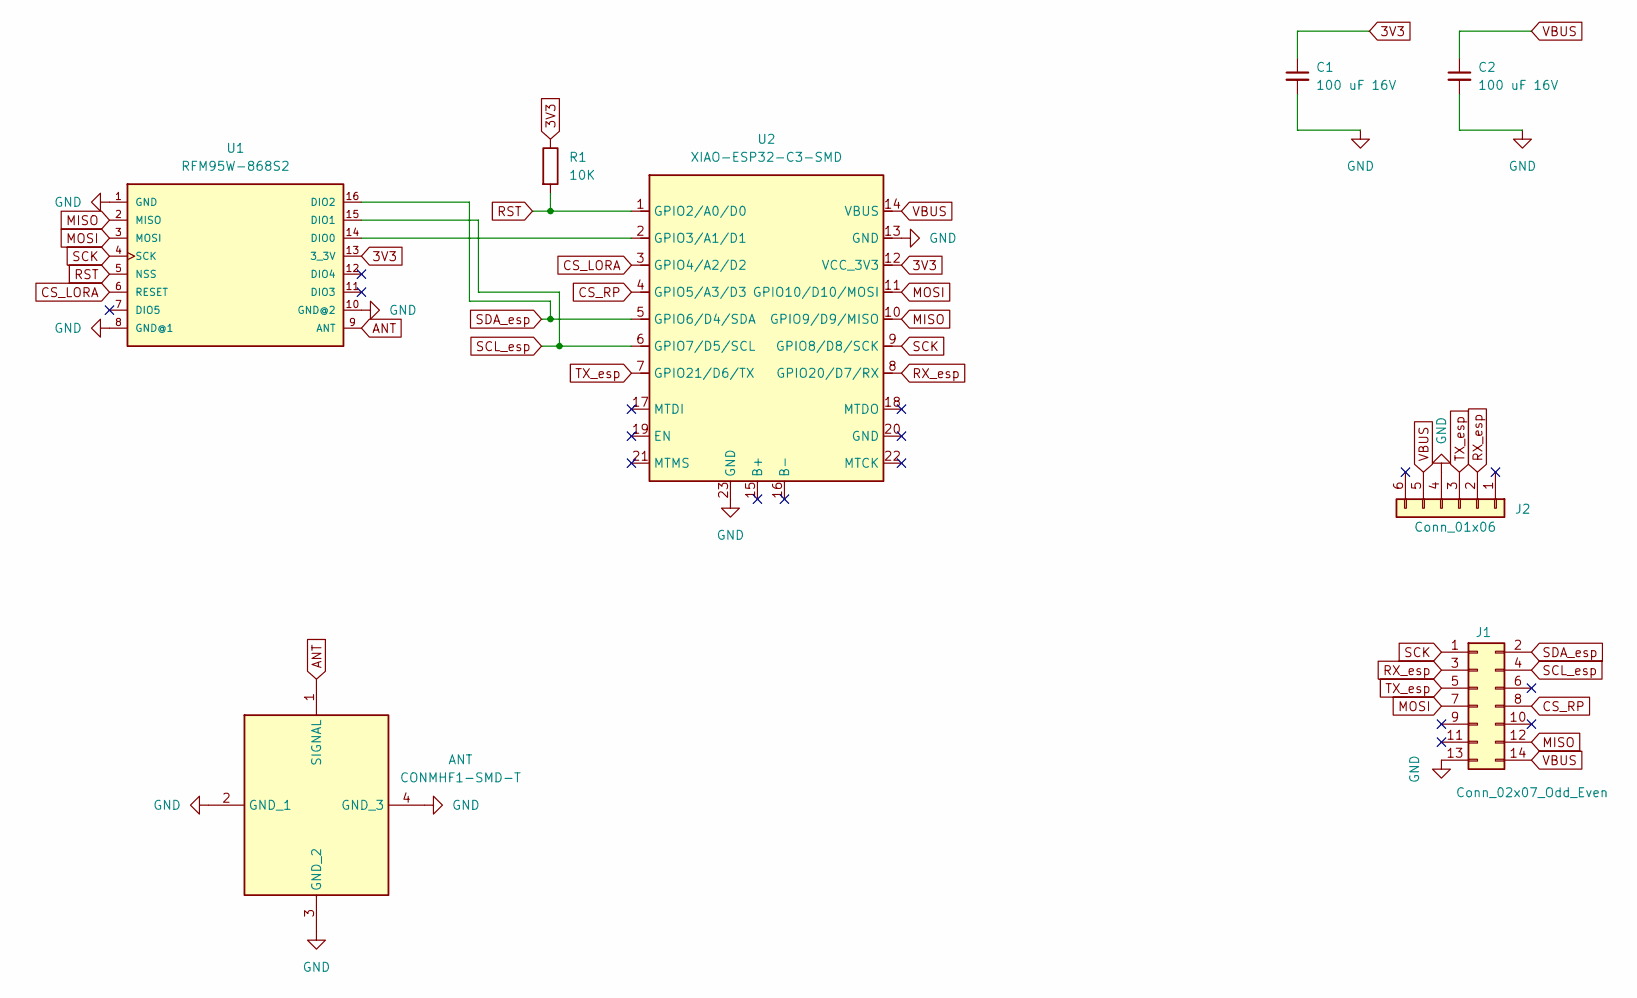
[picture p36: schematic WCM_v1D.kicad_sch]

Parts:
ANT: CONMHF1-SMD-T; CONMHF1SMDT; Mouser Part Number 712-CONMHF1-SMD-T
C1, C2: 100 uF 16V; CP_Elec_4x3.9
J1: Conn_02x07_Odd_Even; PinHeader_2x07_P2.54mm_Vertical_SMD
J2: Conn_01x06; PinHeader_1x06_P2.54mm_Vertical
R1: 10K; R_0603_1608Metric_Pad0.98x0.95mm_HandSolder
U1: RFM95W-868S2; XCVR_RFM95W-868S2
U2: XIAO-ESP32-C3-SMD; XIAO-ESP32C3-SMD

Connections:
3V3: C1.1, R1.1, U1.13 (3_3V), U2.12 (VCC_3V3)
ANT: ANT.1 (SIGNAL), U1.9 (ANT)
CS_LORA: U1.6 (RESET), U2.3 (GPIO4/A2/D2)
CS_RP: J1.8, U2.4 (GPIO5/A3/D3)
GND: ANT.2 (GND_1), ANT.3 (GND_2), ANT.4 (GND_3), C1.2, C2.2, J1.13, J2.4, U1.1 (GND), U1.8 (GND@1), U1.10 (GND@2), U2.13 (GND), U2.23 (GND)
MISO: J1.12, U1.2 (MISO), U2.10 (GPIO9/D9/MISO)
MOSI: J1.7, U1.3 (MOSI), U2.11 (GPIO10/D10/MOSI)
unnamed: U1.14 (DIO0), U2.2 (GPIO3/A1/D1)
RST: R1.2, U1.5 (NSS), U2.1 (GPIO2/A0/D0)
RX_esp: J1.3, J2.2, U2.8 (GPIO20/D7/RX)
SCK: J1.1, U1.4 (SCK), U2.9 (GPIO8/D8/SCK)
SCL_esp: J1.4, U1.15 (DIO1), U2.6 (GPIO7/D5/SCL)
SDA_esp: J1.2, U1.16 (DIO2), U2.5 (GPIO6/D4/SDA)
TX_esp: J1.5, J2.3, U2.7 (GPIO21/D6/TX)
VBUS: C2.1, J1.14, J2.5, U2.14 (VBUS)

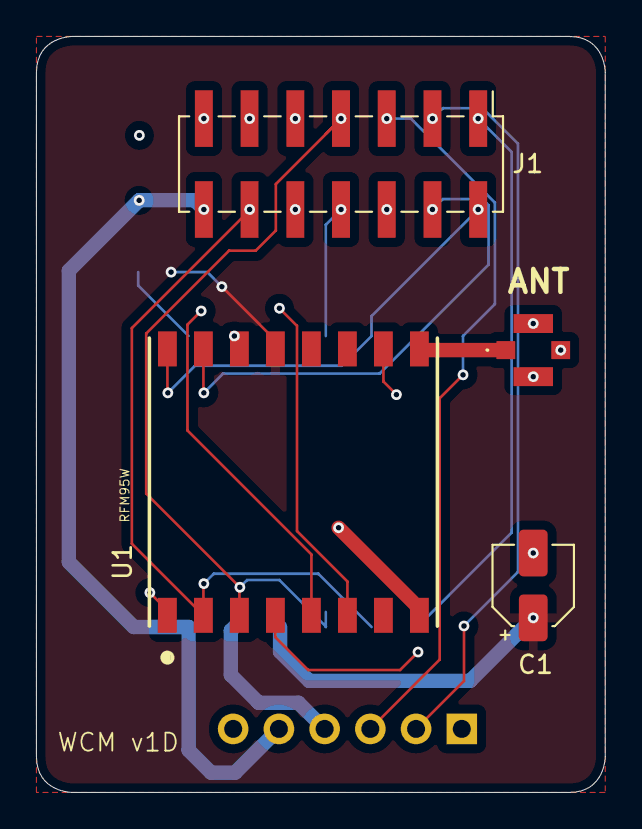
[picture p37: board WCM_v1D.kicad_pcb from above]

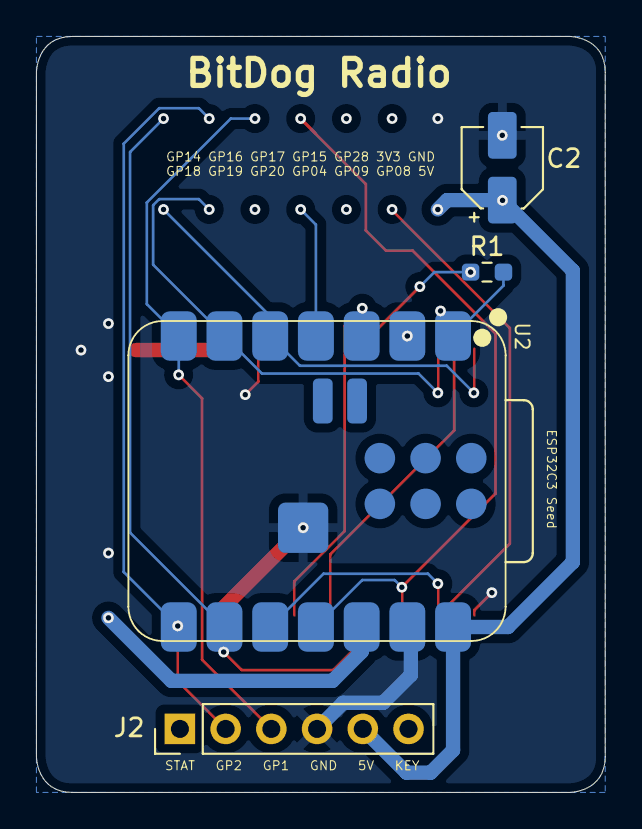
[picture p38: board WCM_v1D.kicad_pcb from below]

Board: 2 copper layers, 31.6 x 42.0 mm, 8 parts (4 on the bottom side), 15 nets.

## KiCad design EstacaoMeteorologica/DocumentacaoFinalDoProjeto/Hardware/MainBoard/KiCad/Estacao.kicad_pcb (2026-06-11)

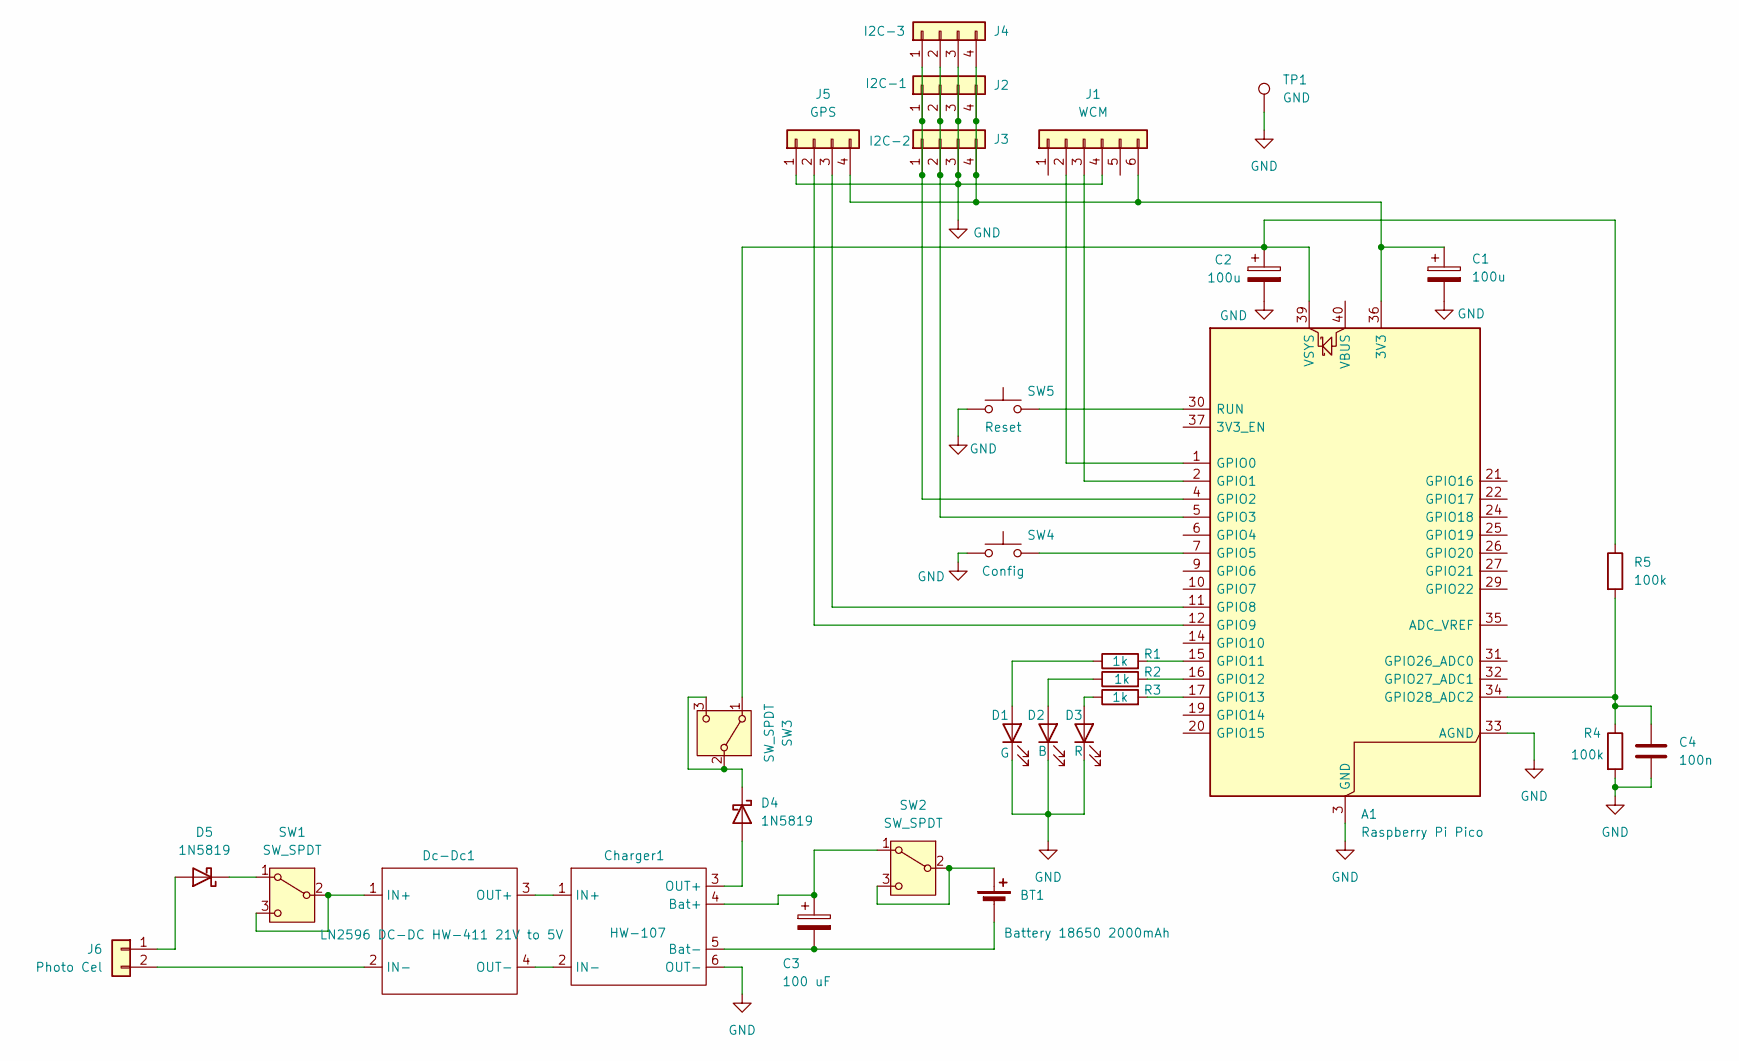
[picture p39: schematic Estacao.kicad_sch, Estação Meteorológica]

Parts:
A1: Raspberry Pi Pico; RaspberryPi_Pico_Common_Unspecified
BT1: Battery 18650 2000mAh; BatteryHolder_MPD_BK-18650-PC2b
C1, C2: 100u; CP_Radial_D7.5mm_P2.50mm
C3: 100 uF; CP_Radial_D7.5mm_P2.50mm
C4: 100n; C_Disc_D5.0mm_W2.5mm_P5.00mm
Charger1: HW-107; Charger
D1: G; LED_D5.0mm
D2: B; LED_D5.0mm
D3: R; LED_D5.0mm
D4, D5: 1N5819; D_DO-41_SOD81_P10.16mm_Horizontal
Dc-Dc1: LN2596 DC-DC HW-411 21V to 5V; Dc_DC
J1: WCM; PinSocket_1x06_P2.54mm_Vertical
J2: I2C-1; JST_XH_B4B-XH-A_1x04_P2.50mm_Vertical
J3: I2C-2; JST_XH_B4B-XH-A_1x04_P2.50mm_Vertical
J4: I2C-3; JST_XH_B4B-XH-A_1x04_P2.50mm_Vertical
J5: GPS; JST_XH_B4B-XH-A_1x04_P2.50mm_Vertical
J6: Photo Cel; BorneBatSolar
R1, R2, R3: 1k; R_Axial_DIN0207_L6.3mm_D2.5mm_P10.16mm_Horizontal
R4, R5: 100k; R_Axial_DIN0207_L6.3mm_D2.5mm_P10.16mm_Horizontal
SW1, SW2, SW3: SW_SPDT; switch_3p_2.54mm_on_off
SW4: Config; SW_PUSH_6mm
SW5: Reset; SW_PUSH_6mm
TP1: GND; PinHeader_1x01_P2.54mm_Vertical

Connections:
GND: A1.3 (GND), A1.8 (GND), A1.13 (GND), A1.18 (GND), A1.23 (GND), A1.28 (GND), A1.33 (AGND), A1.38 (GND), C1.2, C2.2, C4.2, Charger1.6 (OUT-), D1.1 (K), D2.1 (K), D3.1 (K), J1.4, J2.3, J3.3, J4.3, J5.1, R4.2, SW4.1, SW5.1, TP1.1
unnamed: A1.36 (3V3), C1.1, J1.6, J2.4, J3.4, J4.4, J5.4
unnamed: A1.1 (GPIO0), J1.2
unnamed: A1.2 (GPIO1), J1.3
unnamed: A1.4 (GPIO2), J2.1, J3.1, J4.1
unnamed: A1.5 (GPIO3), J2.2, J3.2, J4.2
unnamed: A1.7 (GPIO5), SW4.2
unnamed: A1.11 (GPIO8), J5.3
unnamed: A1.12 (GPIO9), J5.2
unnamed: A1.15 (GPIO11), R1.2
unnamed: A1.16 (GPIO12), R2.2
unnamed: A1.17 (GPIO13), R3.2
unnamed: A1.34 (GPIO28_ADC2), C4.1, R4.1, R5.2
unnamed: A1.30 (RUN), SW5.2
unnamed: A1.39 (VSYS), C2.1, R5.1, SW3.1 (A)
unnamed: BT1.1 (+), SW2.2 (B), SW2.3 (C)
unnamed: BT1.2 (-), C3.2, Charger1.5 (Bat-)
unnamed: C3.1, Charger1.4 (Bat+), SW2.1 (A)
unnamed: Charger1.1 (IN+), Dc-Dc1.3 (OUT+)
unnamed: Charger1.2 (IN-), Dc-Dc1.4 (OUT-)
unnamed: Charger1.3 (OUT+), D4.2 (A)
unnamed: D1.2 (A), R1.1
unnamed: D2.2 (A), R2.1
unnamed: D3.2 (A), R3.1
unnamed: D4.1 (K), SW3.2 (B), SW3.3 (C)
unnamed: D5.2 (A), J6.1
unnamed: D5.1 (K), SW1.1 (A)
unnamed: Dc-Dc1.1 (IN+), SW1.2 (B), SW1.3 (C)
unnamed: Dc-Dc1.2 (IN-), J6.2

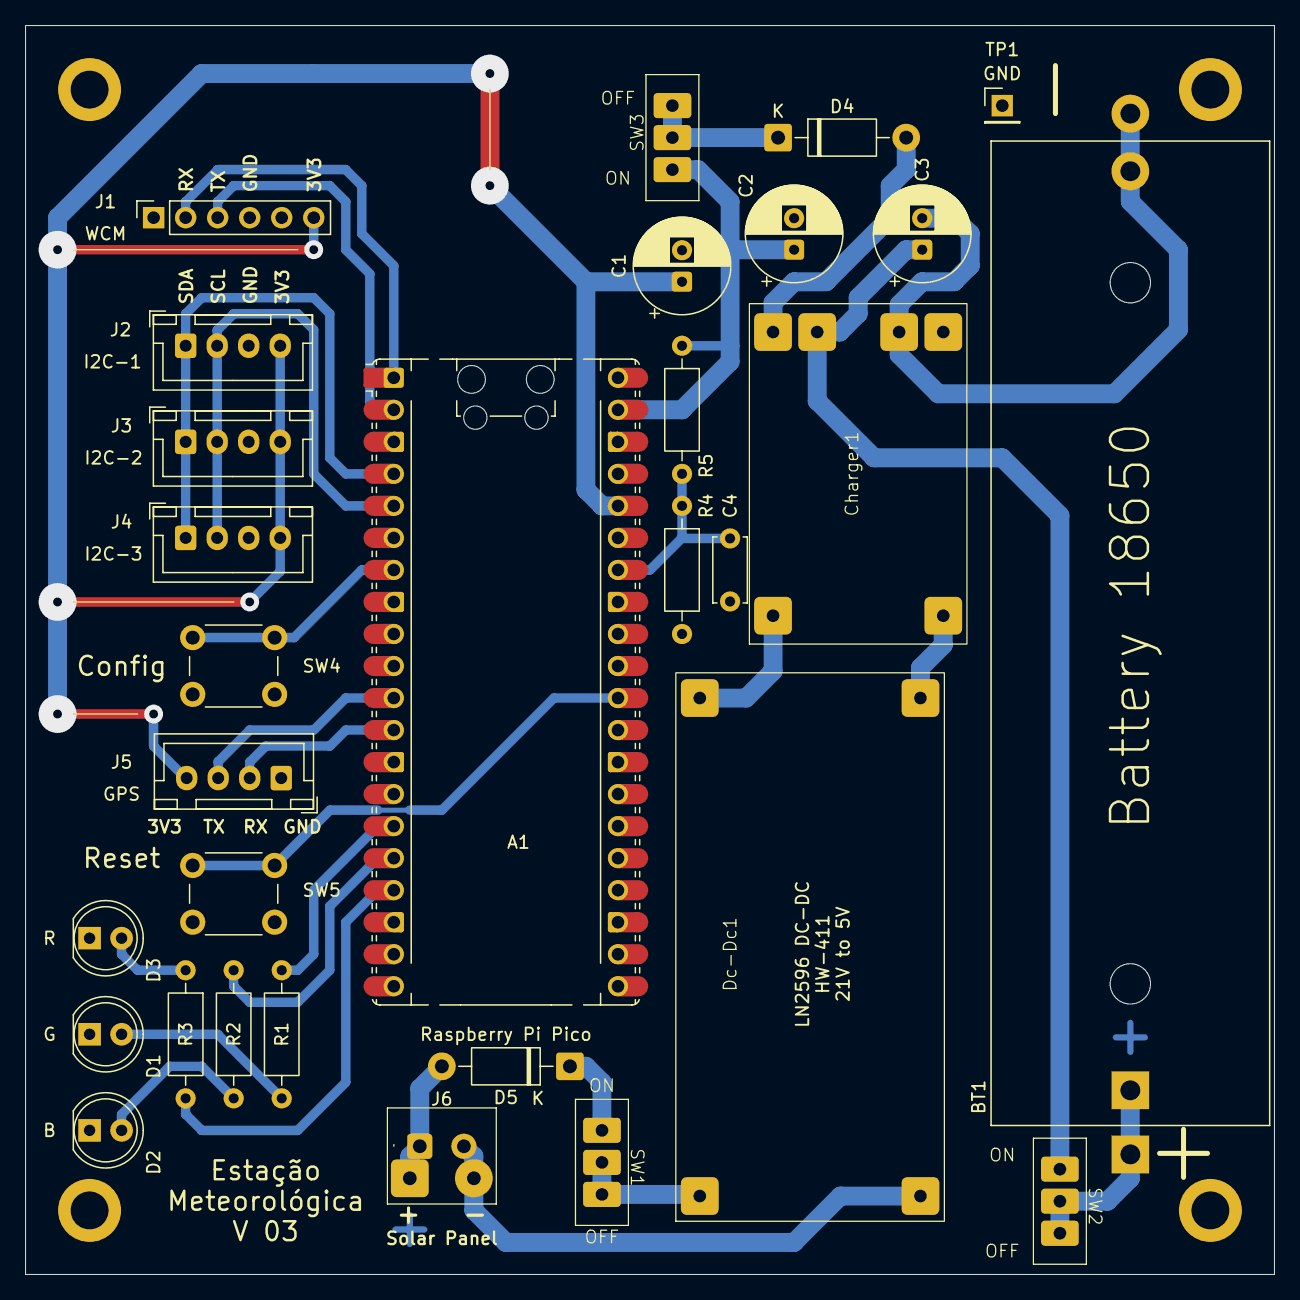
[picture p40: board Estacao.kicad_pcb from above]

Board: 2 copper layers, 99.1 x 99.1 mm, 30 parts (0 on the bottom side), 29 nets.

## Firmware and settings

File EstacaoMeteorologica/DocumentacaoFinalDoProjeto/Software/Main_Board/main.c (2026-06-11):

/**
 * @file    main.c
 * @author  Antonio-Carlos-Ricardo
 * @brief   Inicialização do sistema e main loop
 * @version 0.2
 * @date    2026-02-08
 * 
 * @copyright Copyright (c) 2026
 */

#include <stdio.h>
#include "pico/stdlib.h"
#include "include/aq_data.h"
#include "include/buttons_and_leds.h"
#include "include/code_config.h"
#include "include/fcnt.h"
#include "include/est_config.h"
#include "include/hw_sleep.h"
#include "include/loop_printf.h"
#include "include/menu_conf.h"
#include "include/wcm.h"
#include "include/wrap_watchdog.h"


#define MAIN_ST_INIT            LED_GREEN       // LED Green, indica inicializando o sistema, tempo para conectar USB
#define MAIN_ST_WAIT_BUTTON     LED_YELLOW      // LED Red e Green, indica que botão será reconhecido
#define MAIN_ST_MENU            LED_RED         // Indica que o menu de configuração esta ativo
#define MAIN_ST_MENU_AFTER      LED_CYAN        // Indica que a estação já passo pelo menu
#define MAIN_ST_AQUISITION      LED_BLUE        // Indica que está fazendo aquisição dos dados
#define MAIN_ST_TRANSMISSION    LED_WHITE       // Indica que está transmitindo os dados
#define MAIN_ST_SLEEPING        LED_BLACK       // Indica que a estação está em sleep-mode, baixo consumo de energia


static uint32_t  wakeup_cycle = 0;
static AqData    aq_data;
static EstConfig est_config;

/**
 * @brief Inicializa todo o sistema e mantêm o main loop
 * 
 * @return int  Nunca retorna (main-loop)
 */
int main(){
    int ret;

    stdio_init_all();
    wrap_watchdog_disable();

    #ifdef SLEEP_STATE_BY_GPIO
        // Configuração das GPIOs utilizadas para monitorar o sleep state da estação
        gpio_set_dir(     SLEEP_STATE_GPIO_0, GPIO_OUT);
        gpio_put(         SLEEP_STATE_GPIO_0, 0);
        gpio_set_function(SLEEP_STATE_GPIO_0, GPIO_FUNC_SIO);

        gpio_put(         SLEEP_STATE_GPIO_1, 0);
        gpio_set_dir(     SLEEP_STATE_GPIO_1, GPIO_OUT);
        gpio_set_function(SLEEP_STATE_GPIO_1, GPIO_FUNC_SIO);
    #endif

#ifdef PICO_WITH_DEBUG_PROBE
    // Reconfiguração dos GPIOs da UART para uso em Debug
    gpio_set_function( 0, GPIO_FUNC_SIO);
    gpio_set_function( 1, GPIO_FUNC_SIO);
    gpio_set_function(17, GPIO_FUNC_UART);
    gpio_set_function(16, GPIO_FUNC_UART);
#endif

    buttons_and_leds_init();
    buttons_and_leds_set_color(MAIN_ST_INIT);
    fcnt_init();
    wcm_init();

    // Dar tempo para conectar a interface serial
    sleep_ms(INITIAL_DELAY_MS);    

    printf("********** %s **********\n\n", NAME);
    printf("Version: %s - %s - Build: %s\n", VERSION, VERSION_DATA, BUILD);

    // Janela para pressionar o botão
    bool button_pressed = false;
    for(int i=0;i<25;i++){
        buttons_and_leds_set_color(i&0x01?MAIN_ST_INIT:MAIN_ST_WAIT_BUTTON);
        for(int j=0;j<100;j++){
            if(buttons_and_leds_button_pressed()) button_pressed = true;
            sleep_us(2000);
        }
    }

    
    bool valid_flash_data = est_config_storage_read(&est_config);
    printf(valid_flash_data?"Flash: Valid Data\n\n\n":"Flash: Invalid Data\n\n\n");

    // Verifica condições para iniciar o terminal TXT:
    //    - Dados inválidos na flash                     ou
    //    - (Botão pressionado  e always_menu == false)  ou
    //    - (Botão solto        e always_menu == true )
    //    Obs.: O Botão pressionado inverte o funcionamento do parâmetro always_menu
    if((!valid_flash_data) || 
       (  button_pressed  && (!est_config.always_menu)) || 
       ((!button_pressed) &&   est_config.always_menu)){
        buttons_and_leds_set_color(MAIN_ST_MENU);
        menu_conf(&est_config, valid_flash_data);
    }

    buttons_and_leds_set_color(MAIN_ST_MENU_AFTER);
    aq_data.active_sensors = est_config.active_sensors;

    // Inicializa, power_on de todos os sensores
    if(ret = aqdata_init_power_on(&aq_data, est_config.lux_k_10000, est_config.vsys_k_10000)){
        loop_printf("Init Power sensors fail: %d\n", ret);
        while(1){
            buttons_and_leds_set_color(LED_BLACK);
            sleep_ms(200);
            buttons_and_leds_set_color(LED_RED);
            sleep_ms(200);
        }
    }

    // desativa recursos desnecessários do rp2040
    hw_sleep_init(est_config.usb_mode, est_config.active_sensors.cpu_temp || est_config.active_sensors.vsys,  est_config.sleep_time_min);    
    buttons_and_leds_set_color(LED_BLACK);
    
    wrap_watchdog_enable();

    while (true) {
        wrap_watchdog_update();
        
        // Avisa que vai iniciar a aquisição
        if(est_config.leds_on) buttons_and_leds_set_color(MAIN_ST_AQUISITION);
        
        // Faz a aquisição completa:
        
        // inicia o processo de aquisição
        if(ret = aqdata_init_aq(&aq_data)){
            loop_printf("Init Aq sensors fail: %d\n", ret);
        }
        // lê os dados
        if(ret = aqdata_read(&aq_data)){
            loop_printf("Read sensors fail: %d\n", ret);
        }
        // Coloca os sensores em sleep-mode
        if(ret = aqdata_sleep(&aq_data)){
            loop_printf("Sleep sensors fail: %d\n", ret);
        }
        
        // Envia os dados
        loop_printf("Station sending data\n");
        if(est_config.leds_on) buttons_and_leds_set_color(MAIN_ST_TRANSMISSION);
        wcm_send(&est_config, &aq_data);

        // salva o último fcnt
        fcnt_update();
        
        // Coloca o rp2040 em "sleep-mode" e o ativa para o modo normal quando for fazer o novo ciclo de leitura e aquisição
        loop_printf("Station sleeping\n");
        if(est_config.leds_on) buttons_and_leds_set_color(MAIN_ST_SLEEPING);
        hw_sleep();

        loop_printf("Station Wake Up %d\n", ++wakeup_cycle);
    }
}

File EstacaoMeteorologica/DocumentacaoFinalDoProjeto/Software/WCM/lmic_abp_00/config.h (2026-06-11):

#ifndef CONFIG_H
#define CONFIG_H

#define SW_BUILD   "0008"



#define ESP32C3_XIAO
//#define ESP32C3_SUPER_MINI_PLUS

#define UART_BUFFER_SIZE    256
#define UART_READ_T_MAX_MS  5000

// --- Conexão com o RFM95W ---
#ifdef ESP32C3_XIAO         // seed xiao
#define SPI_SCL     GPIO_NUM_8
#define SPI_MISO    GPIO_NUM_9
#define SPI_MOSI    GPIO_NUM_10
#define SPI_CS      GPIO_NUM_2
#define SPI_RESET   GPIO_NUM_4
#define PIN_DIO0    LMIC_UNUSED_PIN
#define PIN_DIO1    LMIC_UNUSED_PIN
#endif

#ifdef ESP32C3_SUPER_MINI_PLUS   // super mini plus
#define SPI_SCL     GPIO_NUM_4
#define SPI_MISO    GPIO_NUM_5
#define SPI_MOSI    GPIO_NUM_6
#define SPI_CS      GPIO_NUM_7
#define SPI_RESET   GPIO_NUM_10
#define PIN_DIO0    LMIC_UNUSED_PIN
#define PIN_DIO1    LMIC_UNUSED_PIN
#endif


#define RX_PIN GPIO_NUM_20
#define TX_PIN GPIO_NUM_21

#define CMD_LORA            L
#define CMD_LORAWAN_ABP     A
#define CMD_LORAWAN_OTAA    O

extern const char * SETUP_MSG;


#endif // CONFIG_H

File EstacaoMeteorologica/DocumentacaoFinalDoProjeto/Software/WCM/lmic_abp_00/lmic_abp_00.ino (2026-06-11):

#include <Arduino.h>
#include "config.h"
#include "lorawan.h"
#include "uart_com.h"

typedef enum{
    MAIN_STATE_SLEEP = 0,
    MAIN_STATE_SLEEP_ERROR,
    MAIN_STATE_SLEEP_TIMEOUT,
    MAIN_STATE_WAIT_CMD,
    MAIN_STATE_SENDING_MSG
} MainState;

static MainState main_state;

void setup() {
    Serial.begin(115200);
    uart_setup();    
    lorawam_setup();
    delay(10000);
    Serial.println(SETUP_MSG);
    SerialUART.println(SW_BUILD);
    SerialUART.println("Monitor On");

    // configura para sair do sleep pelo RX_PIN
    gpio_wakeup_enable(RX_PIN, GPIO_INTR_LOW_LEVEL);
    esp_sleep_enable_gpio_wakeup();

    main_state = MAIN_STATE_SLEEP;
    Serial.println("Ready System!");
}

void loop() {
    lorawam_update_state();

    switch(main_state){
        case MAIN_STATE_SLEEP:
            Serial.println("Sleeping");
            delay(50);
            esp_light_sleep_start();    // Entrando em light sleep até GPIO20 acordar
            // Acordou do sleep
            // delay(50);
            Serial.println("WakeUp");
            uart_start_read_data();
            main_state = MAIN_STATE_WAIT_CMD;
            break;
        case MAIN_STATE_SLEEP_ERROR:
            SerialUART.print('E');
            main_state = MAIN_STATE_SLEEP;
            break;
        case MAIN_STATE_SLEEP_TIMEOUT:
            SerialUART.print('T');
            main_state = MAIN_STATE_SLEEP;
            break;
        case MAIN_STATE_WAIT_CMD:
            switch(uart_state()){
                case UART_ST_WAITING_DATA:
                    break;
                case UART_ST_DATA_READY:
                    main_state = MAIN_STATE_SENDING_MSG;
                    break;
                case UART_ST_DATA_ERROR:
                    main_state = MAIN_STATE_SLEEP;
                    break;
                case UART_ST_TIMEOUT:
                    main_state = MAIN_STATE_SLEEP;
                    break;
            }
            break;
        case MAIN_STATE_SENDING_MSG:
            if(lorawan_state() == LORAWAN_STATE_SLEEPING){  // Já enviou a msg, pode dormir
                SerialUART.print('O');
                main_state = MAIN_STATE_SLEEP;
            }
            break;
    }
}

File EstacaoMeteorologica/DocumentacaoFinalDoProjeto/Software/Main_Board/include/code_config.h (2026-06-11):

/**
 * @file    code_config.h
 * @author  Antonio-Carlos-Ricardo
 * @brief   Parâmetros de configuração de compilação
 * @version 0.1
 * @date    2026-02-07
 * 
 * @copyright Copyright (c) 2026
 * 
 */
#ifndef CODE_CONFIG_H
#define CODE_CONFIG_H


// ********** Descrição do código gerado **********

#define NAME                        "Weather Station"
#define VERSION                     "0.00.02"
#define VERSION_DATA                "2026/04/07"
#define BUILD                       "0042"
#define CONFIG_DATA_VERSION         5   // uint32_t version;



// ********** Principais parâmetros de configuração **********

// #define PICO_WITH_DEBUG_PROBE                         // habilita o uso do debug probe reconfigurando as portas UART a serem utilizadas

#define DEBUG_ON                false   // true         // habilita printf de log para depuração
#define DEBUG_ON_AD             (DEBUG_ON && true)      // habilita printf de log do módulo aq_data_ad, VSys e MPU Temp
#define DEBUG_ON_BAT            (DEBUG_ON && true)      // habilita printf de log do módulo aq_data_bat
#define DEBUG_ON_BMEP280        (DEBUG_ON && false)     // habilita printf de log do módulo aq_data_bmep280
#define DEBUG_ON_GPS            (DEBUG_ON && true)      // habilita printf de log do módulo aq_data_gps
#define DEBUG_ON_LUXIMETER      (DEBUG_ON && true)      // habilita printf de log do módulo aq_data_lux

#define WATCHDOG_ENABLED                                // se definido ativa o funcionamento do watchdog
// #define START_SEND_WITH_FIX_DATA                      // se definido faz com que as 5 primeiras transmissões sejam valores conhecidos independentes do valor lido, útil para debug
#define SLEEP_STATE_BY_GPIO                             // se definido faz que durante os períodos de sleep os gpio reflitam o funcionamento do Sleep mode, util para debug
#define INITIAL_DELAY_MS        10000                   // define o tempo, em milissegundos, de espera inicial para rodar o programa, permitindo assim conectar a interface serial (USB) antes do programa iniciar
#define USB_TURN_ON_TIME_S      5
// #define ADD_CHECKSUM_ON_PAYLOAD                       // adiciona um CHECKSUM no final do payload
#define LORAWAN_ABP_FCNT_4BYTES


// ********** Parâmetros auxiliares **********

#define LOOP_PRINTF_ENABLED                             // se definido ativa o funcionamento da função loop_printf

// HW_SLEEP_LOW_POWER define se o modo low power será ativado ou não
#ifdef PICO_WITH_DEBUG_PROBE
//#define HW_SLEEP_LOW_POWER false
#define HW_SLEEP_LOW_POWER true
#else
#define HW_SLEEP_LOW_POWER true
#endif



// GPIOs utilizadas para reportar sleep-mode 
#define SLEEP_STATE_GPIO_0      18
#define SLEEP_STATE_GPIO_1      19

// Parâmetros de comunicação do GPS
#define GPS_UART_ID             uart1
#define GPS_UART_UART_IRQ       UART1_IRQ
#define GPS_UART_BAUD_RATE      9600
#define GPS_UART_TX_PIN         8
#define GPS_UART_RX_PIN         9
#define GPS_TIMEOUT_US          10000000

#define GPIO_BUTTON             5
#define GPIO_LED_RED            13
#define GPIO_LED_GREEN          11 
#define GPIO_LED_BLUE           12

// Parâmetros de comunicação do I2C
#define I2C_MAIN_GPIO_SCL       2
#define I2C_MAIN_GPIO_SDA       3
#define I2C_MAIN_BAUDRATE       400000
#define I2C_MAIN_BUS            i2c1
#define I2C_TIMEOUT_US_BMEP280  10000
#define I2C_TIMEOUT_US_BH1750   10000

// Parâmetros de comunicação do WCM via UART
#define WCM_UART_ID             uart0
#define WCM_UART_TX_PIN         0       
#define WCM_UART_RX_PIN         1       
#define WCM_UART_BAUD_RATE      115200
#define WCM_TIMEOUT_US          10000000

#define WATCHDOG_TIME_MS        5000        // dispara o watchdog em 5 segundos se ele não for atualizado


#endif // CODE_CONFIG_H

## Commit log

2026-02-16 Update documentation and project structure
    [em01.csv, em02.csv]
2026-02-16 Daily export 2026-02-16
    [em01.csv, em02.csv]
2026-02-17 Backfill + fix: data até 2026-02-15 e offset=0
    [em01.csv, em02.csv, em03.csv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]
2026-02-17 Daily export 2026-02-17
    [em01.csv, em02.csv, em03.csv]
2026-02-17 Regenerate 2026-02-16 with correct timezone alignment (PC export)
    [em01.csv, em02.csv, em03.csv]
2026-02-18 Daily export 2026-02-18
    [em01.csv, em02.csv, em03.csv]
2026-02-19 Daily export 2026-02-19
    [em01.csv, em02.csv, em03.csv]
2026-02-20 Daily export 2026-02-20
    [em01.csv, em02.csv, em03.csv]
2026-02-21 Daily export 2026-02-21
    [em01.csv, em02.csv]
2026-02-22 Daily export 2026-02-22
    [em01.csv, em02.csv]
2026-02-23 Daily export 2026-02-23
    [em01.csv, em02.csv]
2026-02-24 Daily export 2026-02-24
    [em01.csv, em02.csv]
2026-02-25 Daily export 2026-02-25
    [em01.csv, em02.csv, em03.csv]
2026-02-26 Daily export 2026-02-26
    [em01.csv, em02.csv, em03.csv]
2026-02-27 Daily export 2026-02-27
    [em01.csv, em02.csv, em03.csv]
2026-02-28 Daily export 2026-02-28
    [em01.csv, em02.csv, em03.csv]
2026-03-01 Daily export 2026-03-01
    [em01.csv, em02.csv, em03.csv]
2026-03-02 Daily export 2026-03-02
    [em01.csv, em02.csv, em03.csv]
2026-03-03 Daily export 2026-03-03
    [em01.csv, em02.csv, em03.csv]
2026-03-04 Daily export 2026-03-04
    [em01.csv, em02.csv, em03.csv]
2026-03-05 Daily export 2026-03-05
    [em01.csv, em02.csv, em03.csv]
2026-03-06 Daily export 2026-03-06
    [em01.csv, em02.csv, em03.csv]
2026-03-07 Daily export 2026-03-07
    [em01.csv, em02.csv, em03.csv]
2026-03-08 Daily export 2026-03-08
    [em01.csv, em02.csv, em03.csv]
2026-03-09 Daily export 2026-03-09
    [em01.csv, em02.csv, em03.csv]
2026-03-10 Daily export 2026-03-10
    [em01.csv, em02.csv, em03.csv]
2026-03-11 Daily export 2026-03-11
    [em01.csv, em02.csv, em03.csv]
2026-03-12 Daily export 2026-03-12
    [em01.csv, em02.csv, em03.csv]
2026-03-13 Daily export 2026-03-13
    [em01.csv, em02.csv, em03.csv]
2026-03-14 Daily export 2026-03-14
    [em01.csv, em03.csv]
2026-03-15 Daily export 2026-03-15
    [em01.csv, em03.csv]
2026-03-16 Daily export 2026-03-16
    [em01.csv, em03.csv]
2026-03-17 Daily export 2026-03-17
    [em01.csv, em03.csv]
2026-03-18 Daily export 2026-03-18
    [em01.csv, em02.csv, em03.csv]
2026-03-19 Daily export 2026-03-19
    [em01.csv, em02.csv, em03.csv]
2026-03-20 Daily export 2026-03-20
    [em01.csv, em02.csv, em03.csv]
2026-03-21 Daily export 2026-03-21
    [em01.csv, em02.csv, em03.csv]
2026-03-22 Daily export 2026-03-22
    [em01.csv, em02.csv, em03.csv]
2026-03-23 Daily export 2026-03-23
    [em01.csv, em02.csv]
2026-03-24 Daily export 2026-03-24
    [em01.csv, em02.csv]
2026-03-25 Daily export 2026-03-25
    [em01.csv, em02.csv, em03.csv]
2026-03-26 Daily export 2026-03-26
    [em01.csv, em02.csv, em03.csv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]
2026-03-27 Daily export 2026-03-27
    [em01.csv, em02.csv, em03.csv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]
2026-03-28 Daily export 2026-03-28
    [em01.csv, em02.csv, em03.csv]
2026-03-29 Daily export 2026-03-29
    [em01.csv, em02.csv, em03.csv]
2026-03-30 Daily export 2026-03-30
    [em01.csv, em02.csv, em03.csv]
2026-03-31 Daily export 2026-03-31
    [em01.csv, em02.csv, em03.csv]
2026-04-01 Daily export 2026-04-01
    [em01.csv, em02.csv, em03.csv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]
2026-04-02 Daily export 2026-04-02
    [em01.csv, em02.csv, em03.csv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]
2026-04-03 Daily export 2026-04-03
    [em01.csv, em02.csv, em03.csv]
2026-04-04 Daily export 2026-04-04
    [em01.csv, em02.csv]
2026-04-05 Daily export 2026-04-05
    [em01.csv, em02.csv]
2026-04-06 Daily export 2026-04-06
    [em01.csv, em02.csv]
2026-04-07 Daily export 2026-04-07
    [em01.csv, em02.csv]
2026-04-08 Daily export 2026-04-08
    [em01.csv, em02.csv, em03.csv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]
2026-04-09 Daily export 2026-04-09
    [em02.csv, em03.csv, em04.csv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]
2026-04-10 Daily export 2026-04-10
    [em02.csv, em03.csv, em05.csv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]
2026-04-11 Daily export 2026-04-11
    [em02.csv, em05.csv, em06.csv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]
2026-04-12 Daily export 2026-04-12
    [em01.csv, em02.csv, em05.csv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]
2026-04-13 Daily export 2026-04-13
    [em01.csv, em02.csv, em03.csv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]
2026-04-14 Daily export 2026-04-14
    [em02.csv, em05.csv, em06.csv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]
2026-04-15 Daily export 2026-04-15
    [em02.csv, em05.csv, em06.csv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]
2026-04-16 Daily export 2026-04-16
    [em02.csv, em06.csv, em07.csv]
2026-04-17 Daily export 2026-04-17
    [em01.csv, em02.csv, em03.csv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]
2026-04-18 Daily export 2026-04-18
    [em01.csv, em02.csv, em03.csv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]
2026-04-19 Daily export 2026-04-19
    [em01.csv, em02.csv, em03.csv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]
2026-04-20 Daily export 2026-04-20
    [em01.csv, em02.csv, em03.csv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]
2026-04-21 Daily export 2026-04-21
    [em01.csv, em02.csv, em04.csv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]
2026-04-22 Daily export 2026-04-22
    [em01.csv, em02.csv, em04.csv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]
2026-04-23 Daily export 2026-04-23
    [em01.csv, em02.csv, em04.csv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]
2026-04-24 Daily export 2026-04-24
    [em01.csv, em02.csv, em04.csv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]
2026-04-25 Daily export 2026-04-25
    [em01.csv, em02.csv, em04.csv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]
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2026-06-04 Regenerate all data with comma delimiter
    [em01.csv, em02.csv, em03.csv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]
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2026-06-10 Hugging faces novo repositorio de database
    [em01.csv, em02.csv, em03.csv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]
